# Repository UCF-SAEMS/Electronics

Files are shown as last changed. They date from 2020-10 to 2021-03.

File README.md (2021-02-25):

# Electronics
This project contains the main electronics for the SAEMS Senior Design Project. Currently, this consists of a mainboard and an secondary LED daughter board.

## Mainboard
This is the main controller board for the SAEMS project. It's main functionality is the coordination with the Zigbee base station and sensor data acquisition.

### Block Diagram
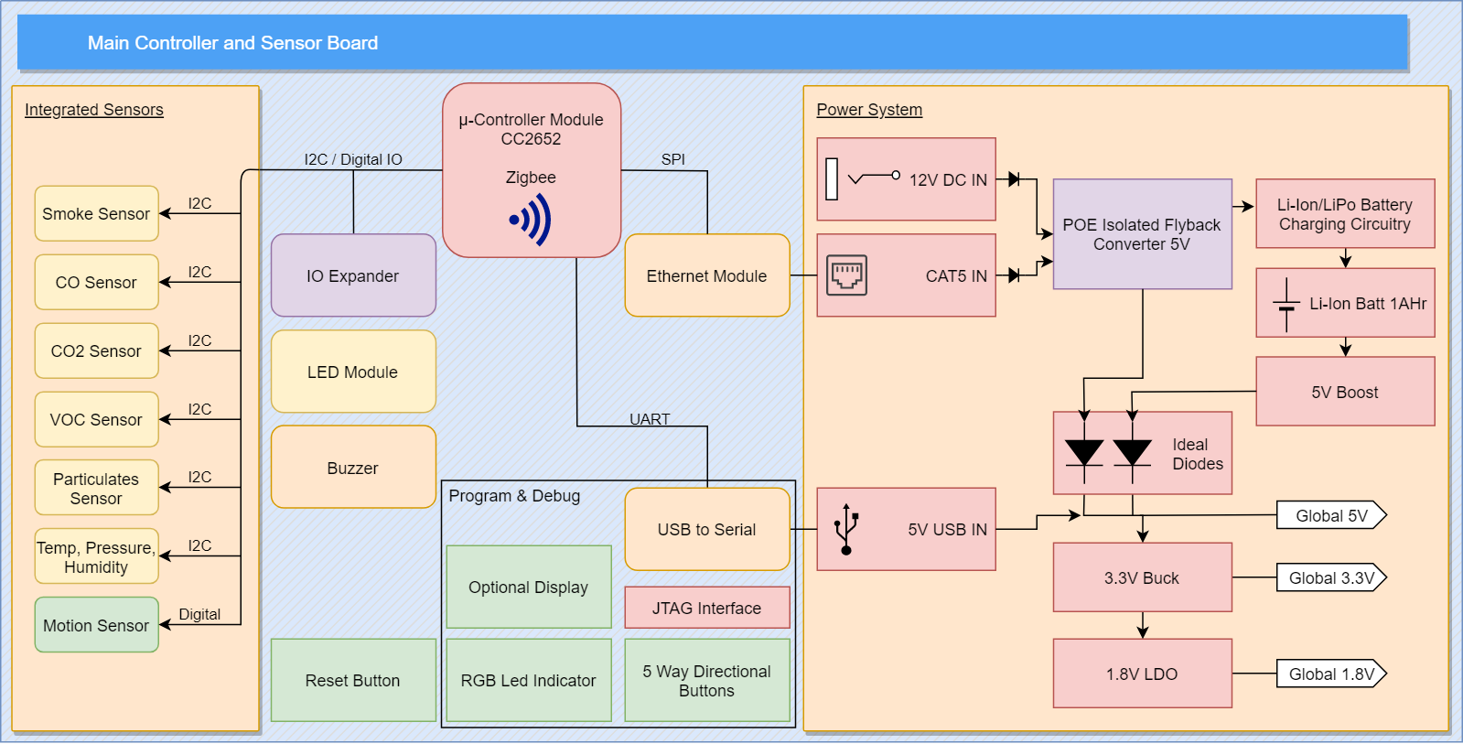
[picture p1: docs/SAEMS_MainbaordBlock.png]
Mainboard_Diagram


[Edit on draw.io](https://app.diagrams.net/#HUCF-SAEMS%2FElectronics%2Fmain%2Fdocs%2FSAEMS_MainbaordBlock.png)

### Schematic
STAIR_Mainboard-schematic

### Layout
<span>PCB Top</span>
<span>PCB Bottom</span>

## Gerbers
Can be found within the Github [repository](build/gerbers).

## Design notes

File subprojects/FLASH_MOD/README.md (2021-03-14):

## FLASH_MOD
This is a bit of a hack. The embedded web server and coresponding assets such as html, css, and javascript libraries took more space than expected to host completly locally. To solve this problem, a FLASH_MOD was developed to add additional external flash memory over SPI.

### Schematic
FLASH_MOD-schematic

### Layout
<span>PCB Top</span>
<span>PCB Bottom</span>

## Gerbers
Can be found within the Github [repository](build/gerbers).

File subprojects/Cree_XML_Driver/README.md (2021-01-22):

## LED Board / Cree_XML_Driver
This is the high power, RGBW LED driver and integrated module board. It includes 4 constant current buck switchers and a set WS2811's to control the individual brightnesses of each color.

### Block Diagram
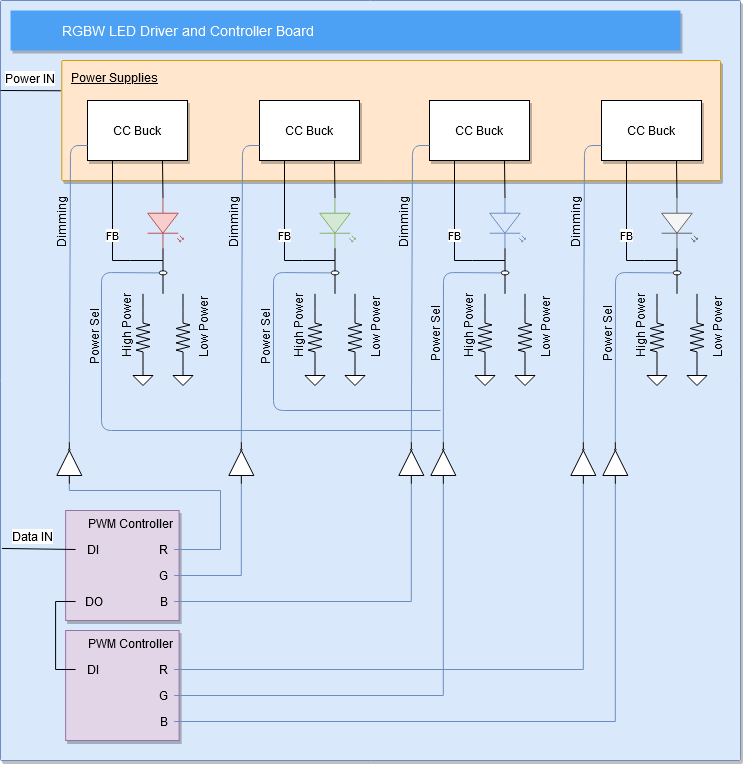
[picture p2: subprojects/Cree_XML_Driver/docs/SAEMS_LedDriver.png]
Cree_XML_Driver_Diagram


[Edit on draw.io](https://app.diagrams.net/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)

### Schematic
Cree_XML_Driver-schematic

### Layout
<span>PCB Top</span>
<span>PCB Bottom</span>

## Gerbers
Can be found within the Github [repository](build/gerbers).

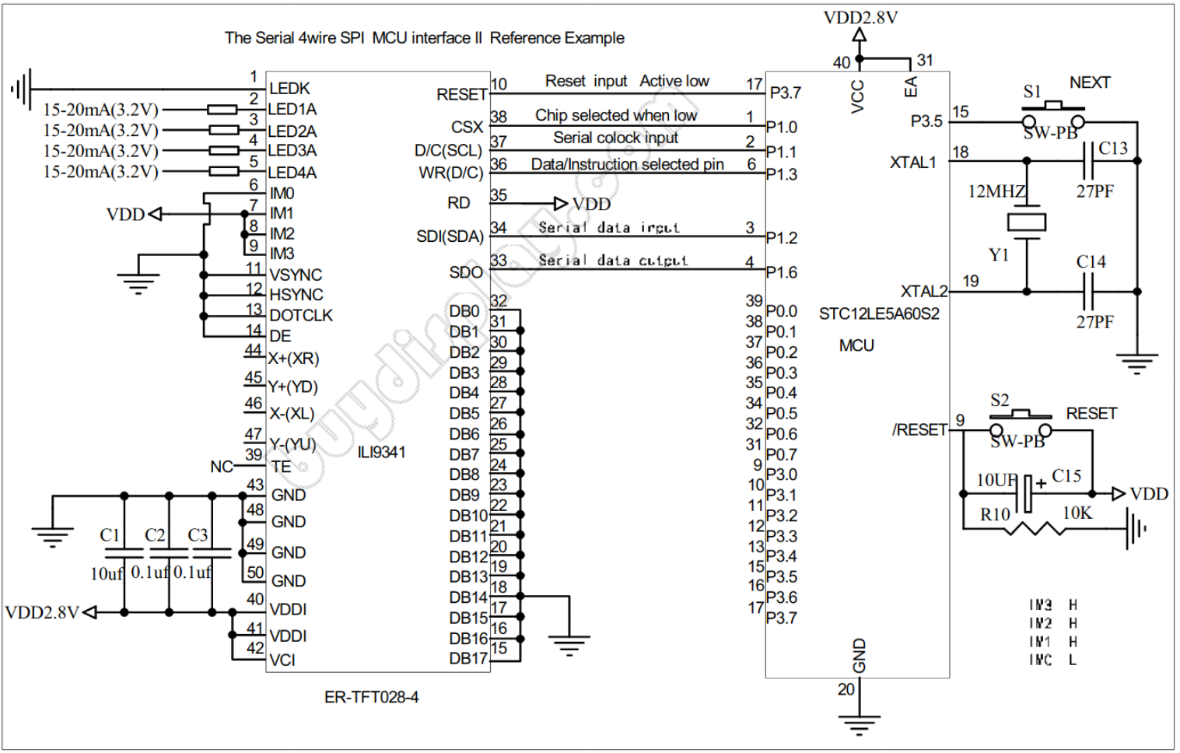
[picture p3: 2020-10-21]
docs/notes/display_rec.png

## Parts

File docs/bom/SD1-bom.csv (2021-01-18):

Row | Description | Part | References | Value | Footprint | Quantity Per PCB | Datasheet | Manufacturer | MPN | Note | Digikey | DNP | LCSC | Mouser | Error | Mfr | Size | Type | Voltage | Current | Power | Volt | Alt
1 | Particulate Matter Sensor I²C | SPS30 | $U101 | SPS30 |  | 1 |  |  | SPS30 | PM2.5 PARTICLE SENSOR | 1649-1106-ND
2 | Unpolarized capacitor, small symbol | C_Small | C602 | 0 | C_0603_1608Metric | 1 | ~ |  |  |  |  | 1
3 | Unpolarized capacitor, small symbol | C_Small | C216 C217 | 20p | C_0603_1608Metric | 2 | ~ |  | CC0603JRNPO9BN200 | CAP CER 20PF 50V C0G/NPO 0603 | 311-1424-1-ND |  | C105621
4 | Unpolarized capacitor, small symbol | C_Small | C314 C803 C807 | 100p | C_0603_1608Metric | 3 | ~ |  | CL10C101JC8NNNC | CAP CER 100PF C0G 50V 0603 | 1276-1295-1-ND | 1 | C296717 |  | 5% |  | 0603 | C0G | 50V
5 | Unpolarized capacitor, small symbol | C_Small | C313 | 330p | C_0805_2012Metric | 1 | ~ |  | CC0805KRX7RABB331 | CAP CER 330PF X7R 200V 0805 | 311-4334-1-ND |  | C527231 |  | 10% |  | 0805 | X7R | 200V
6 | Unpolarized capacitor, small symbol | C_Small | C305 | 680p | C_0603_1608Metric | 1 | ~ |  | 0603B681K500CT | CAP CER 680PF 25V X7R 0603 | 1292-1458-1-ND |  | C335547 |  | 10% |  | 0603 | X7R | 25V
7 | Unpolarized capacitor, small symbol | C_Small | C311 | 1n | C_0805_2012Metric | 1 | ~ |  | CL21B102KCANNNC | CAP CER 1NF X7R 100V 0805 | 1276-1169-1-ND |  | C15177 |  | 10% |  | 0805 | X7R | 100V
8 | Unpolarized capacitor | C | C301 | 2200p | C_1812_4532Metric | 1 | ~ |  | 202S43W222KV4E | CAP CER 2.2NF 2kV X7R 1812 |  |  | C426624 |  | 10% |  | 1812 | X7R | 2kV
9 | Unpolarized capacitor, small symbol | C_Small | C213 C214 | 6.8n | C_0603_1608Metric | 2 | ~ |  | CC0603KRX7R9BB682 | CAP CER 6800PF 50V X7R 0603 | 311-1084-1-ND |  | C107097
10 | Unpolarized capacitor, small symbol | C_Small | C215 C316 | 8.2n | C_0603_1608Metric | 2 |  |  | CC0603KRX7R9BB822 | CAP CER 8.2NF X7R 50V 0603 | 311-1811-1-ND |  | C113812 |  | 10% |  | 0603 | X7R | 50V
11 | Unpolarized capacitor, small symbol | C_Small | C212 C318 | 22n | C_0603_1608Metric | 2 | ~ |  | CL10B223KC8WPNC | CAP CER 22NF X7R 50V 0603 | 1276-CL10B223KC8WPNCCT-ND |  | C472763 |  | 10% |  | 0603 | X7R | 50V
12 | Unpolarized capacitor, small symbol | C_Small | C105 C106 C108 C203 C204 C205 C206 C207 C208 C209 C218 C315 C401 C403 C405 C501 C601 C703 C704 | 0.1u | C_0603_1608Metric | 19 | ~ |  | 0603B104K500CT | CAP CER 0.1UF 50V X7R 0603 | 1292-1643-1-ND |  |  |  | 10% |  | 0603 | X7R | 50V
13 | Unpolarized capacitor, small symbol | C_Small | C312 | 0.1u | C_0805_2012Metric | 1 | ~ |  | CL21B104KCFWPNE | CAP CER 0.1UF X7R 100V 0805 | 1276-6733-1-ND |  | C307361 |  | 10% |  | 0805 | X7R | 100V
14 | Unpolarized capacitor, small symbol | C_Small | C307 | 0.22u | C_0805_2012Metric | 1 | ~ |  | CL21B224KBFNNNE | CAP CER 220NF 25V X7R 0805 | 1276-1093-1-ND |  | C5378 |  | 10% |  | 0805 | X7R | 25V
15 | Unpolarized capacitor, small symbol | C_Small | C102 C104 C317 C701 C702 C707 | 1u | C_0603_1608Metric | 6 | ~ |  | TMK107B7105KA-T | CAP CER 1UF 25V X7R 0603 | 587-2984-1-ND
16 | Unpolarized capacitor, small symbol | C_Small | C302 C304 | 1u | C_1210_3225Metric | 2 | ~ |  | C1210C105K1RACAUTO | CAP CER 1UF 100V X7R 1210 | 399-7044-1-ND |  | C129676 |  | 10% |  | 1210 | X7R | 100V
17 | Unpolarized capacitor, small symbol | C_Small | C201 C202 C210 C211 C219 C402 C404 C808 C811 | 4.7u | C_0603_1608Metric | 9 | ~ |  | C0603C475K9PACTU | CAP CER 4.7UF 6.3V X5R 0603 | 399-3482-1-ND |  | C86016
18 | Unpolarized capacitor, small symbol | C_Small | C101 C103 C107 C705 C706 C801 C802 C806 C809 C810 | 10u | C_0603_1608Metric | 10 |  |  | C1608X5R1A106M080AC | CAP CER 10UF 10V X5R 0603 | 445-6853-1-ND
19 | Polarized capacitor, small US symbol | CP1_Small | C306 | 10u | CP_Elec_4x5.8 | 1 | ~ |  | EEEHD1C100AR | CAP ALU 10UF 16V 4x5.8 | PCE4949CT-ND |  | C401842 |  | 20% |  | .2x.21in | Aluminum | 16V
20 | Polarized capacitor, small US symbol | CP1_Small | C303 | 22u | C_Elec_6.3x7.7 | 1 | ~ |  | EEHZC1J220XP | CAP ALU 22UF 63V 6.3x7.7 | P15467CT-ND |  | C264048 |  | 20% |  | .26x.276in | Aluminum | 63V
21 | Unpolarized capacitor, small symbol | C_Small | C308 C310 C804 C805 | 47u | C_1210_3225Metric | 4 |  |  | 1210X476K160CT | CAP CER 47UF X5R 10V 1210 | 587-5922-1-ND |  | C396815 |  | 20% |  | 1210 | X5R | 10V
22 | Polarized capacitor, small US symbol | CP1_Small | C309 | 47u | CP_Elec_4x5.8 | 1 | ~ |  | EEEFT1C470AR | CAP ALU 47UF 6.3V 4x5.8 | P15090CT-ND |  | C178589 |  | 20% |  | .2x.21in | Aluminum | 6.3V
23 | Diode, filled shape | D_ALT | D305 D306 D307 D801 | BAS16 | D_SOT-23_ANK | 4 | ~ |  | BAS16-7-F | DIODE GEN PURP 75V 200MA SOT23-3 | BAS16-FDICT-ND |  | C69162* |  |  |  |  |  |  | 150mA | 350mW | 75V
24 | BAV99 High-speed switching diodes, SOT-23 | BAV99 | D310 | BAV99 | SOT-23 | 1 | https://assets.nexperia.com/documents/data-sheet/BAV99_SER.pdf |  | BAV99,215 | BAV99 switching diode, generic | 1727-2914-1-ND |  | C152481
25 | Light emitting diode, filled shape | LED_ALT | D311 D402 D403 D404 D802 D803 | LED_ALT | LED_0603_1608Metric | 6 |  |  | 150060RS75000 | LED RED CLEAR 0603 SMD | 732-4978-1-ND |  | C205443
26 | RGB LED, red/green/blue/anode | LED_RGBA | D101 | LED_RGBA | LED_19-237_1.6x1.6mm | 1 | ~ |  | 19-237 | RGB PCB TOP VIEW SMD LED 0606 | 19-237A/R6GHBHC-B01/2T |  | C264508
27 | Schottky diode, filled shape | D_Schottky_ALT | D308 | MBRS540T3 | D_SMC | 1 | ~ |  | MBRS540T3G | RECTIFIER DIODE, SCHOTTKY, 5A, 4 |  |  | C31849 |  |  |  |  |  |  | 5A |  | 40V
28 | Diode | D | D301 D302 D303 D304 | MURA120 | D_SMA | 4 | ~ |  | MURA120T3G |  | MURA120T3GOSCT-ND |  | C111832 |  |  |  |  |  |  | 1A |  | 200V
29 | Photodiode, filled shape | D_Photo_ALT | D701 | Photodiode alt | LED_D3.0mm_Clear | 1 | ~ |  | PD204-6C | SENSOR PHOTODIODE 940NM RADIAL | 1080-1140-ND |  | C264281
30 | Bidirectional transient-voltage-suppression diode, filled shape | D_TVS_ALT | D309 | SMAJ58A | D_SMA | 1 | ~ |  | SMAJ58CA-E3/61 | TVS DIODE 58V 93.6V DO214AC | SMAJ58CA-E3/61GICT-ND |  | C506567 |  |  |  |  |  |  |  | 1W | 58V
31 | TVS Diode Array, 5.5V Standoff, 3 Channels, SOT-143 package | SP0503BAHT | D401 | SP0503BAHT | SOT-143 | 1 | http://www.littelfuse.com/~/media/files/littelfuse/technical%20resources/documents/data%20sheets/sp05xxba.pdf |  | SP0503BAHTG | TVS DIODE 5.5V 8.5V SOT143-4 | F2715CT-ND |  | C7074
32 | Ferrite bead, small symbol | Ferrite_Bead_Small | FB301 FB302 | 10 | L_0603_1608Metric | 2 | ~ | Chilisin Elec | PBY160808T-110Y-N | 11Ω @ 100MHz 4A 1 20mΩ 0603 Ferrite Beads |  |  | C280672 |  |  | MMZ2012R150AT000
33 | Ferrite bead, small symbol | Ferrite_Bead_Small | FB101 FB201 FB601 FB701 | Ferrite_Bead_Small | L_0603_1608Metric | 4 | ~ |  | BLM18PG471SN1D | 470 Ohms @ 100MHz 1 Power Line Ferrite Bead 0603 1A 200mOhm | 490-5223-1-ND |  | C97853 | 81-BLM18PG471SN1D
34 | USB Micro Type B connector | USB_B_Micro | J403 | 10118194-0001LF | USB_Micro-B_Amphenol_10118194_Horizontal | 1 | ~ |  | 10118194-0001LF | CONN RCPT USB2.0 MICRO B SMD R/A | 609-4618-1-ND |  | C132563
35 | Generic connector, single row, 01x02, script generated (kicad-library-utils/schlib/autogen/connector/) | Conn_01x02 | J303 J304 | Conn_01x02 | PinSocket_1x02_P2.54mm_Vertical | 2 | ~
36 | Generic connector, single row, 01x02, script generated (kicad-library-utils/schlib/autogen/connector/) | Conn_01x02 | J801 | Conn_01x02 | JST_PH_B2B-PH-K_1x02_P2.00mm_Vertical | 1 | ~ |  | B2B-PH-K-S(LF)(SN) | CONN HEADER VERT 2POS 2MM | B2B-PH-K-S(LF)(SN) |  | C131337
37 | Generic connector, single row, 01x02, script generated (kicad-library-utils/schlib/autogen/connector/) | Conn_01x02 | J802 | Conn_01x02 | PinHeader_1x02_P2.54mm_Vertical | 1 | ~
38 | Generic connector, single row, 01x11, script generated (kicad-library-utils/schlib/autogen/connector/) | Conn_01x11 | J401 | Conn_01x11 | Molex_SL_171971-0011_1x11_P2.54mm_Vertical | 1 | ~ |  |  | TI Eval connector
39 | Cortex Debug Connector, standard ARM Cortex-M SWD and JTAG interface | Conn_ARM_JTAG_SWD_10 | J404 | Conn_ARM_JTAG_SWD_10 | PinHeader_2x05_P1.27mm_Wide_Shrouded_Vertical_SMD | 1 | http://infocenter.arm.com/help/topic/com.arm.doc.ddi0314h/DDI0314H_coresight_components_trm.pdf |  | FTSH-105-01-L-DV-K | 2x5 1.27mm SMD connector | SAM8799-ND |  |  |  |  |  |  |  |  |  |  |  | BXIDM03
40 | FTDI, USB to serial TTL cable | FTDI_TTL_Cable | J402 | FTDI_TTL_Cable | PinHeader_1x06_P2.54mm_Vertical | 1 |  |  |  |  |  |  | C190819
41 | RJ45 PoE 10/100 Base-TX Jack with Magnetic Module | RJ45_Abracon_ARJP11A-MASA-B-A-EMU2 | J201 | HR861153C | RJ45_Abracon_ARJP11A-MA_Horizontal | 1 | https://abracon.com/Magnetics/lan/ARJP11A.PDF |  | ARJP11A-MASA-B-A-EMU2 | Alt HR861153C verified | ARJP11A-MASA-B-A-EMU2-ND |  | HR861153C
42 | Generic connectable mounting pin connector, single row, 01x08, script generated (kicad-library-utils/schlib/autogen/connector/) | Conn_01x08_MountingPin | J101 | JST 1.25mm | Molex_PicoBlade_53398-0871_1x08-1MP_P1.25mm_Vertical | 1 | ~ |  | 0533980871 |  | WM7612CT-ND |  | C53040
43 | RECAPS connector pinout | RECAPS_Master_r0 | J102 | JST 1.25mm | Molex_PicoBlade_53398-0871_1x08-1MP_P1.25mm_Vertical | 1 |  |  | 0533980871 |  | WM7612CT-ND |  | C53040 | -
44 | Generic connectable mounting pin connector, single row, 01x05, script generated (kicad-library-utils/schlib/autogen/connector/) | Conn_01x05_MountingPin | J103 | JST ZH 1.5mm 1x5 | JST-ZR-B5B-SM4-TFLFSN_1x05-1MP_P1.5mm_Vertical | 1 | ~ |  | B5B-ZR-SM4-TF(LF)(SN) | 1.5mm 01x05 JST ZH | 455-1684-1-ND |  | C265440
45 | DC Barrel Jack with an internal switch | Barrel_Jack_Switch | J301 J302 | PJ-102AH | BarrelJack_CUI_PJ-102AH_Horizontal | 2 | ~ |  | PJ-102AH | CONN PWR JACK 2X5.5MM SOLDER | CP-102AH-ND |  | C84007
46 | Jumper, 3-pole, both open | Jumper_3_Open | JP104 | Jumper_3_Open | PinHeader_1x03_P2.54mm_Vertical | 1 | ~
47 | Jumper, normally open, small symbol | Jumper_NO_Small | JP401 | Jumper_NO_Small | PinHeader_1x02_P2.54mm_Vertical | 1 | ~
48 | Inductor with ferrite core | L_Core_Ferrite | L801 L802 | 1u | L_Wuerth_HCI-5040 | 2 | ~ |  | 744316100 | FIXED IND 1UH 11.5A 4.75 MOHM | 732-6176-1-ND
49 | Inductor with ferrite core | L_Core_Ferrite | L301 | 4.7u | L_Taiyo-Yuden_MD-4040 | 1 | ~ |  | SLW4030S4R7MST | 4.7uH ±20% 2A 60mΩ SMD,4x4x3mm | 587-5994-1-ND |  | C206284, C326301, C15269
50 | Crystal speaker/transducer | Speaker_Crystal | LS101 | Speaker_Crystal | Buzzer_TDK_PS1240P02BT_D12.2mm_H6.5mm | 1 | ~ |  | PS1240P02BT | AUDIO PIEZO TRANSDUCER 30V TH | 445-2525-1-ND |  | C76871
51 | 50V Vds, 0.22A Id, N-Channel MOSFET, SOT-23 | BSS138 | Q101 | BSS138 | SOT-23 | 1 | https://www.fairchildsemi.com/datasheets/BS/BSS138.pdf |  | BSS138 | MOSFET N-CH 50V 200MA SOT23-3 | BSS138-FDICT-ND
52 | Dual PNP transistor, 6 pin package | Q_DUAL_PNP_PNP_C1B1B2C2E2E1 | Q302 Q802 | DMMT5401 | SOT-23-6 | 2 | ~ |  | DMMT5401-7-F | TRANS 2PNP 150V 0.2A SOT26 | DMMT5401-FDICT-ND |  | C154733
53 | P-MOSFET transistor, gate/source/drain | Q_PMOS_GSD | Q301 Q801 | DMP3098L-7 | SOT-23-6 | 2 | ~ |  | DMP3098L-7 | MOSFET P-CH 30V 3.8A SOT23-3 | DMP3098LDICT-ND |  | C150492
54 | N-MOSFET transistor, gate/drain/source | Q_NMOS_GDS | Q303 | FDT86244 | SOT-223-3_TabPin2 | 1 | https://www.onsemi.com/pub/Collateral/FDT86244-D.pdf |  | FDT86244 | MOSFET N-CH 150V 2.8A SOT-223 | FDT86244CT-ND |  | C489347
55 | NPN bias resistor transistor, base/emitter/collector | Q_NPN_BEC_BRT | Q102 | PDTC114EU,115 | SOT-323_SC-70 | 1 | ~ |  | PDTC114EU,115 | TRANS PREBIAS NPN 200MW SOT323 | 1727-5132-1-ND |  | C135830
56 | Resistor, US symbol | R_US | R308 R316 | 0 | R_0603_1608Metric | 2 | ~ |  |  |  |  |  |  |  | 1% |  | 0603 |  |  |  | 1/16W
57 | Resistor, small US symbol | R_Small_US | R602 | 0 | R_0603_1608Metric | 1 | ~ |  |  |  |  | 1
58 | Resistor, US symbol | R_US | R318 | 0.56 | R_1206_3216Metric | 1 | ~ |  | KDV12FR560ET | RES 560M OHM 1% 1/2W 1206 | 273-KDV12FR560ETCT-ND |  | C175807 |  | 1% |  | 1206 |  |  |  | 1/4W
59 | Resistor, US symbol | R_US | R201 | 10 | R_0603_1608Metric | 1 |  |  | RC0603JR-0710RL | RES SMD 10 OHM 5% 1/10W 0603 | 311-10GRDKR-ND |  | C109317
60 | Resistor, US symbol | R_US | R302 R401 | 22.1 | R_0603_1608Metric | 2 |  |  | RC0603FR-0722R1L | RES SMD 22.1 OHM 1% 1/10W 0603 | 311-22.1HRCT-ND |  | C137767
61 | Resistor, US symbol | R_US | R202 R203 R207 R208 R304 R311 | 49.9 | R_0603_1608Metric | 6 |  |  | RC0603FR-0749R9L | RES SMD 49.9 OHM 1% 1/16W 0603 | 311-49.9HRCT-ND |  | C114625 |  | 1% |  | 0603 |  |  |  | 1/16W
62 | Resistor, US symbol | R_US | R312 | 82 | R_2010_5025Metric | 1 | ~ |  |  | RES SMD 82 OHM 5% 1/2W 2010 |  |  | C421678, C20464 |  | 5% |  | 2010 |  |  |  | 1/2W
63 | Resistor, US symbol | R_US | R320 | 499 | R_0603_1608Metric | 1 | ~ |  | AC0603FR-07499RL | RES SMD 499 OHM 1% 1/16W 0603 | 13-AC0603FR-07499RLCT-ND |  | C144655 |  | 1% |  | 0603 |  |  |  | 1/16W
64 | Resistor, US symbol | R_US | R109 R110 R111 R112 R113 R204 R205 R206 R313 R322 R323 R326 R403 R404 R405 R406 R810 R811 | 1k | R_0603_1608Metric | 18 | ~ |  | RC0603FR-071KL | RES SMD 1K OHM 1% 1/10W 0603 | 311-1.00KHRCT-ND |  | C125933 |  | 1% |  | 0603 |  |  |  | 1/16W
65 | Resistor, US symbol | R_US | R317 | 1.27k | R_0603_1608Metric | 1 | ~ |  | RC0603FR-071K27L | RES SMD 1.27K OHM 1% 1/16W 0603 | 311-1.27KHRCT-ND |  | C245930 |  | 1% |  | 0603 |  |  |  | 1/16W
66 | Resistor, US symbol | R_US | R105 R106 R107 R108 R210 R211 R212 R213 R214 R215 R309 R314 R501 R502 R503 R804 R808 R812 R813 | 10k | R_0603_1608Metric | 19 |  |  | RC0603FR-0710KL | RES SMD 10K OHM 1% 1/10W 0603 | 311-10.0KHRCT-ND |  | C98220 |  | 1% |  | 0603 |  |  |  | 1/16W
67 | Resistor, US symbol | R_US | R216 | 12.4k | R_0603_1608Metric | 1 |  |  | RC0603FR-0712K1L | RES SMD 12.1K OHM 1% 1/10W 0603 | 311-12.1KHRCT-ND |  | C123417
68 | Resistor, US symbol | R_US | R324 | 13.3k | R_0603_1608Metric | 1 | ~ |  | RC0603FR-0713K3L | RES SMD 13.3K OHM 1% 1/16W 0603 | 311-13.3KHRCT-ND |  | C185373 |  | 1% |  | 0603 |  |  |  | 1/16W
69 | Resistor, US symbol | R_US | R319 | 19.1k | R_0603_1608Metric | 1 | ~ |  | AC0603FR-0719K1L | RES SMD 19.1K OHM 1% 1/16W 0603 | 13-AC0603FR-0719K1LCT-ND |  | C227638 |  | 1% |  | 0603 |  |  |  | 1/16W
70 | Resistor, US symbol | R_US | R301 | 24.9k | R_0603_1608Metric | 1 | ~ |  | RC0603FR-0724K9L | RES SMD 24.9K OHM 1% 1/16W 0603 | 311-24.9KHRCT-ND |  | C137761 |  | 1% |  | 0603 |  |  |  | 1/16W
71 | Resistor, US symbol | R_US | R305 | 39.2k | R_0603_1608Metric | 1 | ~ |  | AC0603FR-0739K2L | RES SMD 39.2K OHM 1% 1/16W 0603 | YAG3602CT-ND |  | C227854 |  | 1% |  | 0603 |  |  |  | 1/16W
72 | Resistor, US symbol | R_US | R315 | 41.2k | R_0603_1608Metric | 1 | ~ |  | RC0603FR-0741K2L | RES SMD 41.2K OHM 1% 1/16W 0603 | 311-41.2KHRCT-ND |  | C185330 |  | 1% |  | 0603 |  |  |  | 1/16W
73 | Resistor, US symbol | R_US | R115 R310 R402 R805 | 47.5k | R_0603_1608Metric | 4 |  |  | RC0603FR-0747K5L | RES SMD 47.5K OHM 1% 1/10W 0603 | 311-47.5KHRCT-ND |  | C137715
74 | Resistor, US symbol | R_US | R306 R807 | 59k | R_0603_1608Metric | 2 | ~ |  | RC0603FR-0759KL | RES SMD 59K OHM 1% 1/16W 0603 | 311-59.0KHRCT-ND |  | C309564 |  | 1% |  | 0603 |  |  |  | 1/16W
75 | Resistor, US symbol | R_US | R307 | 80.6k | R_0603_1608Metric | 1 | ~ |  | RC0603FR-0780K6L | RES SMD 80.6K OHM 1% 1/16W 0603 | 311-80.6KHRCT-ND |  | C482928 |  | 1% |  | 0603 |  |  |  | 1/16W
76 | Resistor, US symbol | R_US | R101 R321 R325 R407 R801 R803 R809 | 100k | R_0603_1608Metric | 7 | ~ |  | RC0603FR-07100KL | RES SMD 100K OHM 1% 1/10W 0603 | 311-100KHRCT-ND
77 | Resistor, US symbol | R_US | R303 R806 | 392k | R_0603_1608Metric | 2 | ~ |  | RC0603FR-07392KL | RES SMD 392K OHM 1% 1/16W 0603 | 311-392KHRCT-ND |  | C245963 |  | 1% |  | 0603 |  |  |  | 1/16W
78 | Resistor, US symbol | R_US | R114 R601 R802 | 732k | R_0603_1608Metric | 3 |  |  | RC0603FR-07732KL | RES SMD 732K OHM 1% 1/10W 0603 | 311-732KHRCT-ND |  | C246003
79 | Resistor, US symbol | R_US | R102 R103 R104 R209 R701 | 1M | R_0603_1608Metric | 5 |  |  | RC0603FR-071ML | RES SMD 1M OHM 1% 1/10W 0603 | 311-1.00MHRCT-ND |  | C105578
80 | Alps 4-direction Type with Center-push Function | Multidirection_Switch | SW101 | Multidirection_Switch | SKRHA_bosses | 1 | https://tech.alpsalpine.com/prod/e/html/multicontrol/switch/skrh/skrh_list.html |  | SKRHADE011, SKRHADE010 |  |  |  | C602036, C202415
81 | Push button switch, generic, two pins | SW_Push | SW401 | PTS810 | SW_SPST_PTS810 | 1 | ~ |  |  | SWITCH TACTILE SPST-NO 0.05A 16V | CKN10503CT-ND |  | C221897
82 | SMT POE Gate Drive Transformer, 1:0.667:0.262, 36-72 to 5V | HR051067 | T301 | HR051067 | HR051067 | 1 |  |  | HR051067 |  |  |  | C93830
83 | SPEC Carbon Monoxide (CO) Sensor 1000ppm THT | 110-102 | U601 | 110-102 | SPEC_110-102 | 1 |  | SPEC Sensors, LLC | 110-102 |  | 1684-1000-ND
84 | Integrated Optical Module for Smoke Detection | ADPD188BI | U702 | ADPD188BI | ADPD188BI | 1 | https://www.analog.com/media/en/technical-documentation/data-sheets/ADPD188BI.pdf | Analog Devices Inc. | ADPD188BI-ACEZR7 | SENSOR SMOKE 470NM/850NM AMB 24LGA | ADPD188BI-ACEZR7
85 | 3-in-1 sensor, humidity, pressure, temperature, I2C and SPI interface, 1.71-3.6V, LGA-8 | BME280 | U105 | BME280 | Bosch_LGA-8_2.5x2.5mm_P0.65mm_ClockwisePinNumbering | 1 | https://www.bosch-sensortec.com/media/boschsensortec/downloads/datasheets/bst-bme280-ds002.pdf | Bosch | BME280 | Humidity Temperature Sensor 0 ~ 100% RH I²C, SPI ±3% 1s Surface Mount | 828-1063-1-ND |  | C92489 | 262-BME280
86 | RF TxRx+MCU 802.15.4, Bluetooth Bluetooth v5.0, Thread, Zigbee | CC2652P | U103 | CC2652P | RF-BM-2652P2 | 1 | https://www.szrfstar.com/product/237-en.html | RF-star | RF-BM-2652P2
87 | Ultra-low power digital gas sensor for monitoring indoor air quality | CCS811 | U501 | CCS811 | AMS_LGA-10-1EP_2.7x4mm_P0.6mm | 1 | http://ams.com/eng/Products/Environmental-Sensors/Air-Quality-Sensors/CCS811 | ScioSense | CCS811B-JOPR5K | CCS811B-JOPR5K LGA10 LF T&R | CCS811B-JOPR5KCT-ND
88 | USB to UART master bridge, QFN-28 | CP2102N-A01-GQFN28 | U401 | CP2102N-A02-GQFN28R | QFN-28-1EP_5x5mm_P0.5mm_EP3.35x3.35mm | 1 | https://www.silabs.com/documents/public/data-sheets/cp2102n-datasheet.pdf | Silicon Labs | CP2102N-A02-GQFN28R | USB Bridge, USB to UART USB 2.0 UART Interface 28-QFN (5x5) | 336-5890-1-ND |  | C428937 |  |  |  |  |  |  |  |  |  | CP2102N-A02-GQFN28R
89 | PIR Motion Sensor EKMC VZ Panasonic | EKMC1691111 | U106 | EKMC1691111 | EKM | 1 | https://www3.panasonic.biz/ac/ae/search_num/index.jsp?c=detail&part_no=EKMC1691111 | Panasonic Electric Works | EKMC1691111 | Sensor PIR (Passive Infrared) 98.425 (2.5m) - Module | 255-6303-ND
90 | 2.8"TFT Touch Shield for Arduino w/Capacitive Touch Screen Module | ER-TFTM028-4 | U101 | ER-TFTM028-4 | ER-TFTM028-4 | 1 | https://www.buydisplay.com/2-8-inch-tft-touch-shield-for-arduino-w-capacitive-touch-screen-module |  | DS1023-2*20SF11 | Header Female 2x20 2.54mm |  |  | C132132
91 | Electrochemical Sensor AFE | LMP91000 | U602 | LMP91000 | WSON-14-1EP_4.0x4.0mm_P0.5mm_EP2.6x2.6mm | 1 | https://www.ti.com/lit/ds/symlink/lmp91000.pdf | Texas Instruments | LMP91000SD | IC AFE 1 CHAN 8BIT 14WSON | 296-44382-1-ND |  | C181364, C84366
92 | 16-bit I/O expander, I2C, interrupts, w pull-ups, SSOP-28 | MCP23017_SS | U102 | MCP23017 | SSOP-28_5.3x10.2mm_P0.65mm | 1 |  | Microchip Technology | MCP23017T-E/SS | IC I/O EXPANDER 16BIT I2C 28SSOP | MCP23017T-E/SSCT-ND
93 | Single cell, Li-Ion/Li-Po charge management controller, 4.20V, Tri-State Status Output, in SOT23-5 package | MCP73831-2-OT | U803 | MCP73831-2-OT | SOT-23-5 | 1 | http://ww1.microchip.com/downloads/en/DeviceDoc/20001984g.pdf | Microchip Technology | MCP73831T-2ACI/OT | IC CONTROLLR LI-ION 4.2V SOT23-5 | MCP73831T-2ACI/OTCT-ND |  | C424093
94 | I2C CO2, humidity, and temperature sensor | SCD30 | U104 | SCD30 | SCD30_reverse_mount | 1 | https://www.sensirion.com/fileadmin/user_upload/customers/sensirion/Dokumente/9.5_CO2/Sensirion_CO2_Sensors_SCD30_Datasheet.pdf | Sensirion | SCD30 | CO2 SENSOR I2C/MODBUS/PWM DIGITL | 1649-1098-ND |  |  | 403-SCD30
95 | Smoke Chamber for ADPD188BI | Chamber | U703 | Smoke Chamber | ADPD188BI_Chamber | 1 |  |  |  | 3D printed smoke chamber |  | 1
96 | Optocoupler, Phototransistor Output, 5300 VRMS, VCEO 70V, CTR% 40-80, -55 to +110 degree Celcius, UL, BSI, FIMKO, cUL, THT PDIP-4 | SFH617A-1 | U303 | TCMT1107 | SOIC-4_4.55x2.6mm_P1.27mm | 1 | https://www.vishay.com/docs/83510/tcmt1100.pdf |  | TCMT1107 | Optoisolator Transistor Output 3750Vrms 1 Channel 4-SOP | TCMT1107CT-ND |  | C81148
97 | Shunt Regulator, SOT-23 | TL431DBZ | U302 | TL431A | SOT-23 | 1 | http://www.ti.com/lit/ds/symlink/tl431.pdf | Texas Instruments | TL431ACDBZR | IC VREF SHUNT 36V 1% SOT23-3 | 296-17328-1-ND |  | C113312
98 | High Efficiency Synchronous Buck Converter, Adjustable Output 0.6V-5.5V, 3A, SOT563 | TLV62585 | U802 | TLV62585 | SOT-563 | 1 | http://www.ti.com/lit/ds/symlink/tlv62585.pdf |  | TLV62585DRLR | IC REG BUCK ADJUSTABLE 3A SOT563 | 296-51694-1-ND |  | C485117
99 | 200mA Low Dropout Voltage Regulator, Fixed Output 1.8V, SOT-23-5 | TLV70018_SOT23-5 | U701 | TLV70018 | SOT-353_SC-70-5 | 1 | http://www.ti.com/lit/ds/symlink/tlv700.pdf | Texas Instruments | TLV70018DCK | IC REG LINEAR 1.8V 200MA SC70-5 | 296-32409-1-ND |  | C133796
100 | IEEE 802.3 PoE Interfaceand ConverterController | TPS23753A | U301 | TPS23753A | TSSOP-14_4.4x5mm_P0.65mm | 1 |  | Texas Instruments | TPS23753APWR | IC POE CNTRL 1 CHANNEL 14TSSOP | 296-39365-1-ND |  | C92115
101 | 1MHz 8A Boost converter with 0.5-V ultra-low input voltage | TPS61022 | U801 | TPS61022 | Texas_VQFN-HR-7 | 1 | http://www.ti.com/lit/ds/symlink/tps61022.pdf | Texas Instruments | TPS61022 | Boost Switching Regulator IC Positive Adjustable 2.2V 1 Output 7-VFQFN | 296-TPS61022RWURCT-ND
102 | 10/100Mb SPI Ethernet controller with TCP/IP stack, LQFP-48 | W5500 | U201 | W5500 | LQFP-48_7x7mm_P0.5mm | 1 | http://wizwiki.net/wiki/lib/exe/fetch.php/products:w5500:w5500_ds_v109e.pdf | WIZnet | W5500 | IC CTLR 3-1 ETH TCP/IP 48LQFP | 1278-1021-ND |  | C32843
103 | Three pin crystal, GND on pin 2 | Crystal_GND2 | Y201 | 25MHz | Crystal_SMD_3225-4Pin_3.2x2.5mm | 1 | ~ |  | X1E000021035200 | CRYSTAL 25MHZ 20PF SMD | SER4375CT-ND |  | C91738, C255955
Project info:
Schematic: | SD1
Variant: | default
Revision:
Date: | 2021-01-18_13-06-37
KiCad Version: | 5.1.7-a382d34a8~87~ubuntu18.04.1
Statistics:
Component Groups: | 103
Component Count: | 232
Fitted Components: | 232
Number of PCBs: | 1
Total Components: | 232

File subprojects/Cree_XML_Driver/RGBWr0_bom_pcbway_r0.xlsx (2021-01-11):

 |  |  | RGBW_R0 4PCS BOM
Item # | *Ref Des | *Qty | Manufacturer | *Mfg Part # | Description / Value | *Package | Type | Your Instructions / Notes | LCSC | DigiKey
1 | C106 C102 C107 C103 C104 C108 C101 C105 | 8 | Murata Electronics | GRM21BR61C106KE15L | CAP CER 10UF 16V X5R 0805 | Capacitor_SMD:C_0805_2012Metric | SMD |  | C77075 | 490-3886-1-ND
2 | C111 C110 C109 | 3 | Walsin | 0603B104K500CT | CAP CER 0.1UF 50V X7R 0603 | Capacitor_SMD:C_0603_1608Metric | SMD |  | C314282 | 1292-1643-1-ND
3 | D101 | 1 |  |  |  | mylib:LED_Cree_XM-L_20mm_Module | DNS
4 | D102 | 1 |  | PMEG4030ER,115 | DIODE SCHOTTKY 40V 3A SOD123W | Diode_SMD:D_SOD-123F | SMD |  | C389355 | 1727-5313-1-ND
5 | J101 | 1 |  | PJ-102AH | CONN PWR JACK 2X5.5MM SOLDER | Connector_BarrelJack:BarrelJack_CUI_PJ-102AH_Horizontal | DNS |  | C84007 | CP-102AH-ND
6 | J102 | 1 |  |  |  | Connector_PinHeader_2.54mm:PinHeader_1x03_P2.54mm_Horizontal | DNS
7 | J103 | 1 |  | 0532610871 | CONN HEADER SMD R/A 8POS 1.25MM | Connector_Molex:Molex_PicoBlade_53261-0871_1x08-1MP_P1.25mm_Horizontal | SMD |  | C29041 | WM7626CT-ND
8 | JP104 JP103 JP102 JP101 | 4 |  |  |  | Jumper:SolderJumper-3_P1.3mm_Bridged12_Pad1.0x1.5mm | DNS
9 | L101 L103 L102 L104 | 4 |  | SLW4030S4R7MST | 4.7uH ±20% 2A 60m Ohm SMD,4x4x3mm | Inductor_SMD:L_Taiyo-Yuden_MD-4040 | SMD | LCSC | C206284, C15269 | 587-5994-1-ND
10 | LOGO101 | 1 |  |  |  | mylib:MYLIB_CWW_COPPER | DNS
11 | MK101 MK102 MK103 MK104 | 4 |  |  |  | mylib:MountingHole_3.2mm_M3_ISO14580_Pad | DNS
12 | Q101 Q102 Q103 Q104 | 4 |  | Si2302CDS-T1 | MOSFET N-CH 20V 2.6A SOT-23 | Package_TO_SOT_SMD:SOT-23 | SMD |  | C10488 | SI2302CDS-T1-E3CT-ND
13 | R101 R104 R108 R105 | 4 |  | SR732ATTDR120F | RES 0.12 OHM 1% 1/3W 0805 | Resistor_SMD:R_0805_2012Metric | SMD | Order from Digikey | C186575, C171368 | RL12S.12FCT-ND
14 | R102 R103 R107 R106 | 4 |  | SR732ATTDR270F | RES 0.27 OHM 1% 1/3W 0805 | Resistor_SMD:R_0805_2012Metric | SMD | Order from Digikey | C186583, C171374 | RL12S.27FCT-ND
15 | R113 R118 R109 R110 R112 R111 | 6 |  | RC0603FR-07100RL | RES SMD 100 OHM 1% 1/10W 0603 | Resistor_SMD:R_0603_1608Metric | SMD |  | C105588 | 311-100HRCT-ND
16 | R114 R115 R116 R119 R120 R121 | 6 |  | RC0603FR-07100KL | RES SMD 100K OHM 1% 1/10W 0603 | Resistor_SMD:R_0603_1608Metric | SMD |  | C14675 | 311-100KHRCT-ND
17 | R117 R122 | 2 |  | RC0603FR-0733RL | RES SMD 33 OHM 1% 1/10W 0603 | Resistor_SMD:R_0603_1608Metric | SMD |  | C108661 | 311-33.0HRCT-ND
18 | TP101 | 1 |  |  |  | TestPoint:TestPoint_THTPad_1.0x1.0mm_Drill0.5mm | DNS
19 | U101 U103 U102 U104 | 4 | Diodes Incorporated | PAM2804AAB010 | IC LED DRIVER RGLTR 1A TSOT25 | Package_TO_SOT_SMD:TSOT-23-5 | SMD |  | C71463 | PAM2804AAB010DICT-ND
20 | U106 | 1 | Nexperia | 74HC14D,653 | IC INVERTER SCHMITT 6CH 14SO | Package_SO:SOIC-14_3.9x8.7mm_P1.27mm | SMD |  | C5605 | 1727-2783-1-ND
21 | U107 U105 | 2 | Worldsemi | WS2811 | IC LED DRIVER RGB | Package_SO:SOIC-8_3.9x4.9mm_P1.27mm | SMD |  | C114581
Need a quick and accurante quote? Need an efficient production? Please read SMT Ordering Necessary Files & Info in 1 minute. Thank you very much! (https://www.pcbway.com/smt_ordering_guide.html)
Click for Instructions on How to Create a BOM (https://www.pcbway.com/blog/PCB_Assembly/How_to_Build_a_BOM__Bill_Of_Materials_.html)
 | for expensive parts (more than $1) please also quote LCSC and pick the cheaper.

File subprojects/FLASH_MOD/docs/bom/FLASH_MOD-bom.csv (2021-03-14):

Row | Description | Part | References | Value | Footprint | Quantity Per PCB | Datasheet | DNP | MPN | Note | LCSC | Digikey
1 | Unpolarized capacitor, small symbol | C_Small | C2 | 0.1u | C_0603_1608Metric | 1 | ~ |  | 0603B104K500CT | CAP CER 0.1UF 50V X7R 0603 |  | 1292-1643-1-ND
2 | Unpolarized capacitor, small symbol | C_Small | C1 | 1u | C_0603_1608Metric | 1 | ~ |  | TMK107B7105KA-T | CAP CER 1UF 25V X7R 0603 |  | 587-2984-1-ND
3 | Jumper, normally open, small symbol | Jumper_NO_Small | JP1 JP2 JP3 | Jumper_NO_Small | R_0201_0603Metric | 3 | ~
4 | CWW Logo | MYLIB_CWW_COPPER | LOGO101 | MYLIB_CWW_COPPER | MYLIB_CWW_COPPER | 1 |  | 1
5 | Resistor, US symbol | R_US | R1 | 10k | R_0603_1608Metric | 1 |  |  | RC0603FR-0710KL | RES SMD 10K OHM 1% 1/10W 0603 | C98220 | 311-10.0KHRCT-ND
6 | 2.8"TFT Touch Shield for Arduino w/Capacitive Touch Screen Module | ER-TFTM028-4 | U101 | ER-TFTM028-4 | ER-TFTM028-4 | 1 | https://www.buydisplay.com/2-8-inch-tft-touch-shield-for-arduino-w-capacitive-touch-screen-module |  | DS1023-2*20SF11 | Header Female 2x20 2.54mm | C132132
7 | 128Mb Serial Flash Memory, Standard/Dual/Quad SPI, SOIC-8 | W25Q128JVS | U1 | W25Q128JVS | SOIC-8_5.23x5.23mm_P1.27mm | 1 | http://www.winbond.com/resource-files/w25q128jv_dtr%20revc%2003272018%20plus.pdf
Project info:
Schematic: | FLASH_MOD
Variant: | default
Revision:
Date: | 2021-03-14_15-13-46
KiCad Version: | 5.1.7-a382d34a8~87~ubuntu18.04.1
Statistics:
Component Groups: | 7
Component Count: | 9
Fitted Components: | 9
Number of PCBs: | 1
Total Components: | 9

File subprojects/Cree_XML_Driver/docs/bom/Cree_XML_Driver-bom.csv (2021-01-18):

Row | Description | Part | References | Value | Footprint | Quantity Per PCB | Datasheet | LCSC | Manufacturer | Digikey | MPN | Note | DNP | RDS
1 | Unpolarized capacitor, small symbol | C_Small | C109 C110 C111 | 0.1u | C_0603_1608Metric | 3 | ~ | C314282 | Walsin | 1292-1643-1-ND | 0603B104K500CT | CAP CER 0.1UF 50V X7R 0603
2 | Unpolarized capacitor, small symbol | C_Small | C101 C102 C103 C104 C105 C106 C107 C108 | 10u | C_0805_2012Metric | 8 | ~ | C77075 | Murata Electronics | 490-3886-1-ND | GRM21BR61C106KE15L | CAP CER 10UF 16V X5R 0805
3 | RGB LED, 6 pin package with exposed pad | LED_RGBW_EP | D101 | Cree XM-L | LED_Cree_XM-L_20mm_Module | 1 | https://www.cree.com/led-components/media/documents/XLampXML_Color.pdf |  |  |  |  |  | 1
4 | Schottky diode, filled shape | D_Schottky_ALT | D102 | PMEG4030 | D_SOD-123F | 1 | ~ | C389355 |  | 1727-5313-1-ND | PMEG4030ER,115 | DIODE SCHOTTKY 40V 3A SOD123W
5 | Generic connector, single row, 01x03, script generated (kicad-library-utils/schlib/autogen/connector/) | Conn_01x03 | J102 | Conn_01x03 | PinHeader_1x03_P2.54mm_Horizontal | 1 | ~ |  |  |  |  |  | 1
6 | Generic connectable mounting pin connector, single row, 01x08, script generated (kicad-library-utils/schlib/autogen/connector/) | Conn_01x08_MountingPin | J103 | JST 1.25mm | Molex_PicoBlade_53261-0871_1x08-1MP_P1.25mm_Horizontal | 1 | ~ | C29041 |  | WM7626CT-ND | 0532610871 | 1.25mm JST-like 01x08
7 | DC Barrel Jack with an internal switch | Barrel_Jack_Switch | J101 | PJ-102AH | BarrelJack_CUI_PJ-102AH_Horizontal | 1 | ~ | C84007 |  | CP-102AH-ND | PJ-102AH | CONN PWR JACK 2X5.5MM SOLDER
8 | Inductor with ferrite core | L_Core_Ferrite | L101 L102 L103 L104 | 4.7u | L_Taiyo-Yuden_MD-4040 | 4 | ~ | C206284, C15269 |  | 587-5994-1-ND | SLW4030S4R7MST | 4.7uH ±20% 2A 60mΩ SMD,4x4x3mm
9 | N-MOSFET transistor, gate/source/drain | Q_NMOS_GSD | Q101 Q102 Q103 Q104 | Si2302CDS-T1 | SOT-23 | 4 | https://www.vishay.com/docs/68645/si2302cds.pdf | C10488 |  | SI2302CDS-T1-E3CT-ND | Si2302CDS-T1 | MOSFET N-CH 20V 2.6A SOT-23 |  | 0.045@1A
10 | Resistor, US symbol | R_US | R101 R104 R105 R108 | 0.120 | R_0805_2012Metric | 4 | ~ | C186575, C171368 |  | RL12S.12FCT-ND | SR732ATTDR120F | 0.12 0805 330mW
11 | Resistor, US symbol | R_US | R102 R103 R106 R107 | 0.270 | R_0805_2012Metric | 4 | ~ | C186583, C171374 |  | RL12S.27FCT-ND | SR732ATTDR270F | 0.27 0805 330mW
12 | Resistor, US symbol | R_US | R117 R122 | 33 | R_0603_1608Metric | 2 | ~ | C108661 |  | 311-33.0HRCT-ND | RC0603FR-0733RL
13 | Resistor, US symbol | R_US | R109 R110 R111 R112 R113 R118 | 100 | R_0603_1608Metric | 6 | ~ | C105588 |  | 311-100HRCT-ND | RC0603FR-07100RL
14 | Resistor, US symbol | R_US | R114 R115 R116 R119 R120 R121 | 100k | R_0603_1608Metric | 6 | ~ | C14675 |  | 311-100KHRCT-ND | RC0603FR-07100KL
15 | IC INVERTER SCHMITT 6CH | SN74HC14N-dk_Logic-Gates-and-Inverters | U106 | 74HC14D,653 | SOIC-14_3.9x8.7mm_P1.27mm | 1 |  | C5605 | Nexperia | 1727-2783-1-ND | 74HC14D,653 | IC INVERTER SCHMITT 6CH 14SO
16 | 1A, Step-Down CC Led Driver, 250kHz, TSOT-23 | PAM2804 | U101 U102 U103 U104 | PAM2804 | TSOT-23-5 | 4 | https://www.diodes.com/assets/Datasheets/PAM2804.pdf | C71463 | Diodes Incorporated | PAM2804AAB010DICT-ND | PAM2804AAB010 | IC LED DRIVER RGLTR 1A TSOT25
17 | 3-Channel 8-Bit PWM LED Driver, DIP-8/SOIC-8 | WS2811 | U105 U107 | WS2811 | SOIC-8_3.9x4.9mm_P1.27mm | 2 | https://cdn-shop.adafruit.com/datasheets/WS2811.pdf | C114581 | Worldsemi
Project info:
Schematic: | Cree_XML_Driver
Variant: | default
Revision:
Date: | 2021-01-18_14-16-22
KiCad Version: | 5.1.7-a382d34a8~87~ubuntu18.04.1
Statistics:
Component Groups: | 17
Component Count: | 53
Fitted Components: | 53
Number of PCBs: | 1
Total Components: | 53

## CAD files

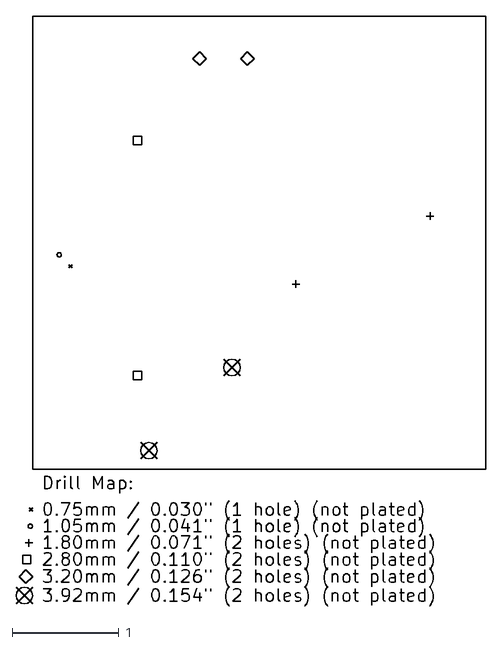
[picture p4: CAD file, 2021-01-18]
build/gerber/SD1-NPTH_drill_map.dxf
4.41 x 5.53

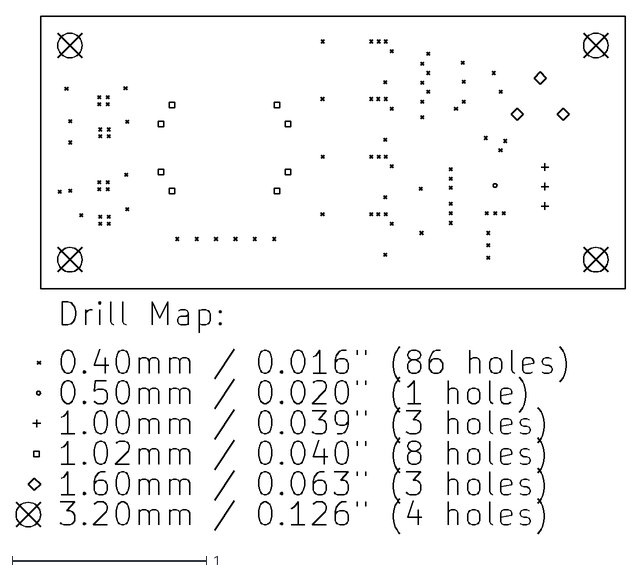
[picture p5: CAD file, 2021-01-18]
subprojects/Cree_XML_Driver/build/gerber/Cree_XML_Driver-PTH_drill_map.dxf
3.13 x 2.66

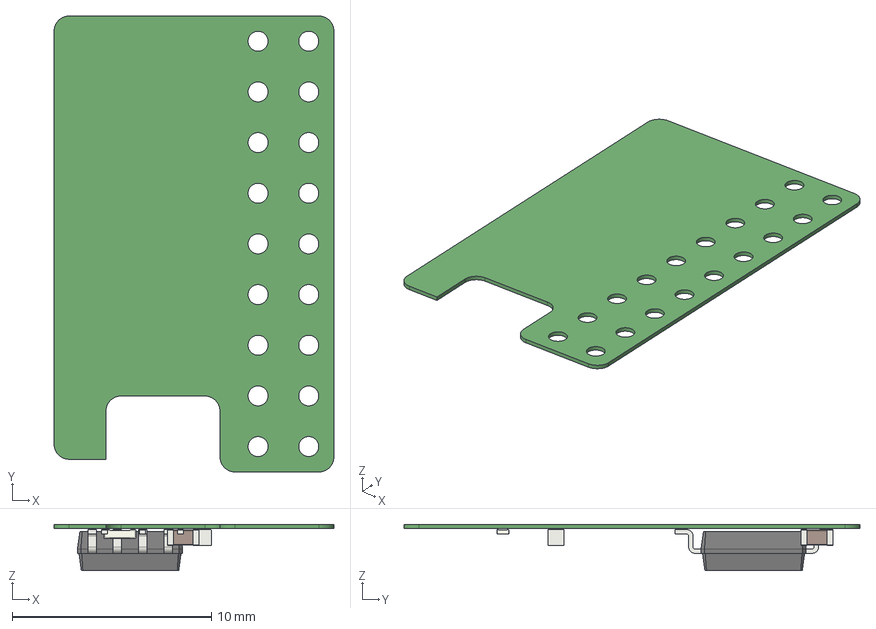
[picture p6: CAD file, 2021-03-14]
subprojects/FLASH_MOD/build/cad/FLASH_MOD.step
14.0 x 22.9 x 2.32 mm

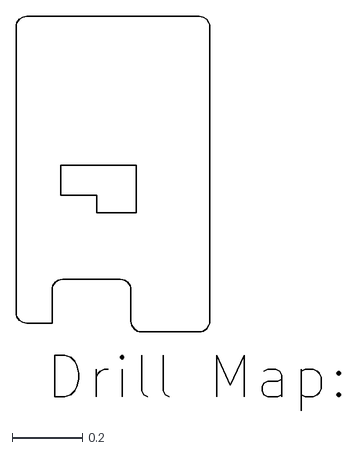
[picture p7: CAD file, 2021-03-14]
subprojects/FLASH_MOD/build/gerber/FLASH_MOD-NPTH_drill_map.dxf
0.926 x 1.12

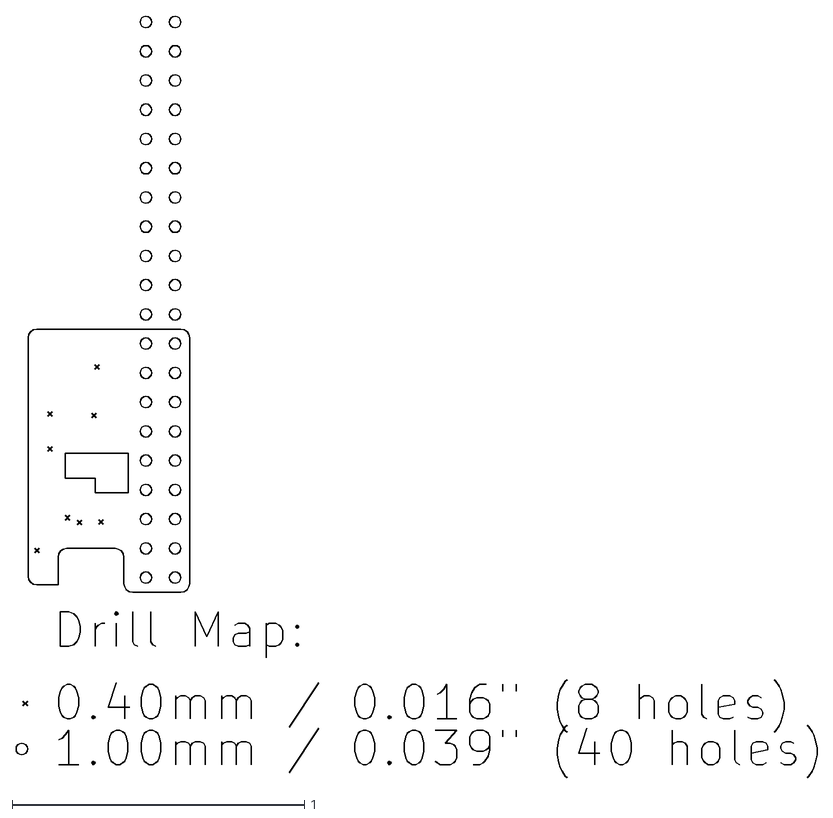
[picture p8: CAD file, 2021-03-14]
subprojects/FLASH_MOD/gerber/FLASH_MOD-PTH-drl_map.dxf
2.74 x 2.60

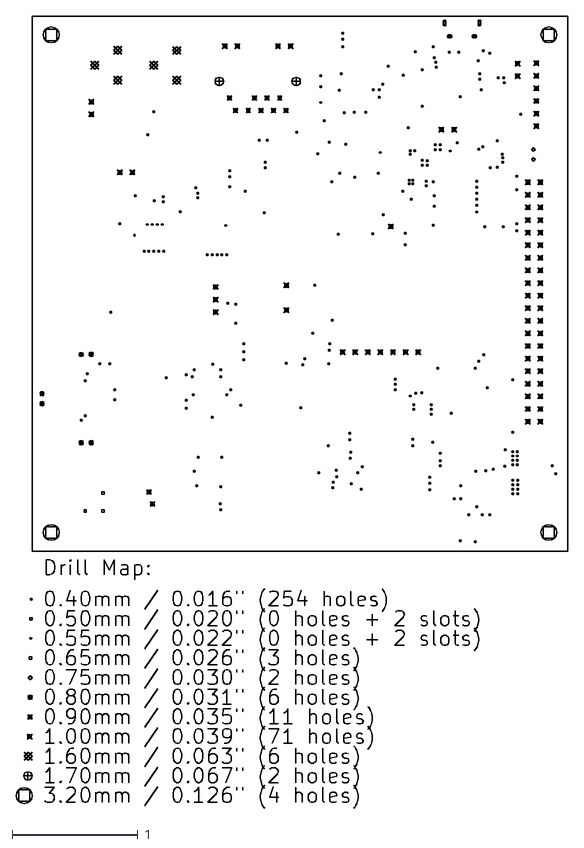
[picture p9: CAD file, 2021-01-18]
build/gerber/SD1-PTH_drill_map.dxf
4.38 x 6.29

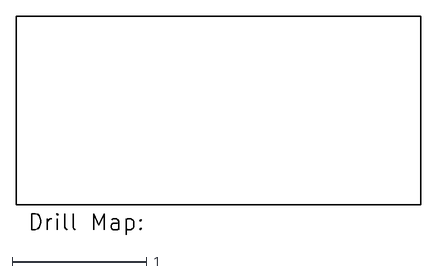
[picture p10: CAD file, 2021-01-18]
subprojects/Cree_XML_Driver/build/gerber/Cree_XML_Driver-NPTH_drill_map.dxf
3.00 x 1.62

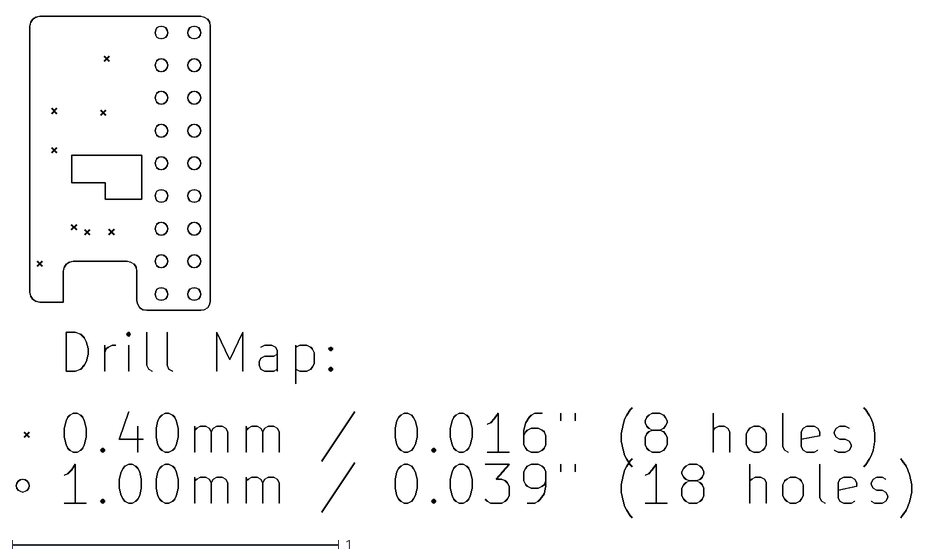
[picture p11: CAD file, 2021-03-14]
subprojects/FLASH_MOD/build/gerber/FLASH_MOD-PTH_drill_map.dxf
2.74 x 1.53

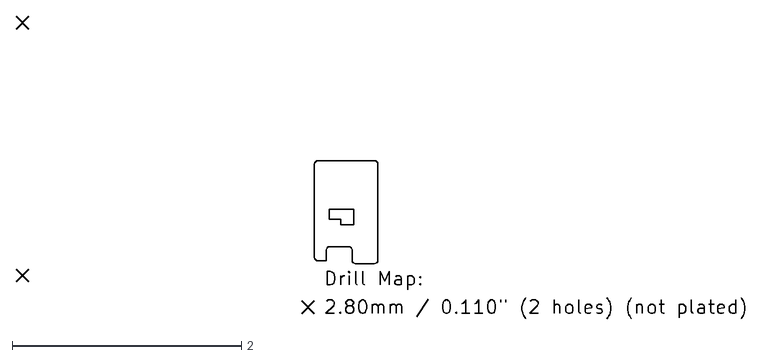
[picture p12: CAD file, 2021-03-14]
subprojects/FLASH_MOD/gerber/FLASH_MOD-NPTH-drl_map.dxf
6.36 x 2.64

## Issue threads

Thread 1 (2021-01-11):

Incorrect footprints: ideal doide fet

clayton13, 2021-01-11:
Q301 and Q801 both have SOT-23-6 footprints when the physical part is really just a SOT-23.

clayton13, 2021-01-11:
As the board is in the middle of SMT we cannot change the PCB design. To wiremod this we will need to do the following:

| Part | Pcbnew | 3D |
| --- | --- | --- |
| Q301 | |
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

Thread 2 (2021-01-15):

Incorrect footprint:    RF-BM-2652P2

clayton13, 2021-01-15:
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

clayton13, 2021-01-15:
Now that its morning, I can more clearly describe the issue.

## Antenna options
The [datasheet](https://www.szrfstar.com/download/604-en.html) lists the following:
> RF-BM-2652P2 integrates three kind of antenna output modes: PCB, IPEX connector and half-hole interface,
which make the module more convenient for application and development.

Meaning there are 3 antenna configuration based on the jumper configuration on the top of the board:

1. Internal Embedded PCB Antenna 🔴
2. External IPEX 🔵
3. External on the parent board 🟢

## Module documentation
| Functional Schematic | PCB | Desc |
| --- | --- | --- |
| 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 | 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 | Position 1[🔴]  and 2[🔵+🟢] control which antenna configuration is being used. <br><br> When not in use, the other channel is left floating. |

## Our case
For our case, as we are using the factory default of Position 1, the `ANT` #3 🟢 signal, exposed on the half-hole interface, is fully floating and not connected to anything. As it is completely floating, it will not be and issue if the pin were to be shorted to the nearby `GND` pad.

The current board can be manufactured as planned with no changes.

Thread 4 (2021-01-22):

Incorrect footprint design: RGB LED, D101 - 19-237/R6GHBHW-C01/2T

clayton13, 2021-01-22:
The assembler caught this and came up with a solution, of merely rotating the part 90deg. If one zooms in on the left photo it can be more clearly seen.

| PIC | Footprint |
| --- | --- |
| 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 | 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 |

clayton13, 2021-01-22:
Researching the root cause, I made the mistake as the datasheet did not indicate the footprint numbering was from the bottom view, so the pads' numbering is reversed.

This can be further checked if one looks at the die and observes the 3 gold bond wires meeting at the common anode.

The correct view is as follows:
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

clayton13, 2021-01-22:
As it looks like we can get away with the rotated part, as in no shorts. The color mapping will have to be changed. The color mapping for this revision can be found as follows.

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

The previous mapping is shown in yellow where the new mapping is in pink. This means that software we will have to swap the red and blue channels when interfacing with this led.

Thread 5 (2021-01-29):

Ethernet jack 3D model going through board surface

clayton13, 2021-01-29:
The J201 jack is not properly offset in the part. This directly drives the connector faceplate in SolidWorks and as such should be amended here. I have added a fix there, but going forward we should fix this. See image:

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

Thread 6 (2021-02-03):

Flyback reference not correct

clayton13, 2021-02-03:
The U302 reference was correctly chosen as a TL431 ([TL431ACDBZR](https://www.digikey.com/en/products/detail/texas-instruments/TL431ACDBZR/686855)) which has a reference voltage of 2.5V instead of the expected 1.24V. This has the effect of doubling the expected 5V output from the flyback.

clayton13, 2021-02-03:
I see two possible solutions:

1. Recalculate the feedback resistors to match, R315 and R324
2. Purchase the expected TL**V**431 and put in its place.

clayton13, 2021-02-11:
As option 2 does not work due to incompatible footprints so we will proceed with option 1.

This is an easy calculation to get 5V as it is exactly double the 2.5V reference so if two identical resistors are used in the range of 30k - 100k the output voltage would be suitable. However, under load this voltage my droop so we want to aim a little higher.

Taking advantage of the existing 41.2k and a parallel combo of common 75k and 100k (42.857k equivalent) generates an output voltage of 5.10V.

| Original | Modded |
| --- | --- |
| | <ol><li>Desolder R324 (marking is **13C**), discard</li><li>Move R315 to R324 (marking is **60C**)</li><li> Solder 100k on R315</li><li>Solder 75k ontop of R315</li></ol>|
| 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  | 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 |

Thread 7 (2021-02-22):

CO Sensor, analog ground reference not connected

clayton13, 2021-02-22:
The LMP91000's GNDA is not directly connected to the system digital GND or to the ground of the ADC.

clayton13, 2021-02-23:
Temporary fix: simply short the localized GNDA into system global GND. This can be achieved by shorting The GNDA side of R601 or C601 to the ground pour.

Going forward: a local nettie will have to be added or GNDA should be replaced with GND.

| Schematic | Options |
| --- | --- |
| 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  | 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

After employing the 🔴 option above, I was able to get correct (enough) analog readings from the LMP's internal temperature sensor.  The separated grounds lead to an erroneous measurement of ~0.5V over expected.

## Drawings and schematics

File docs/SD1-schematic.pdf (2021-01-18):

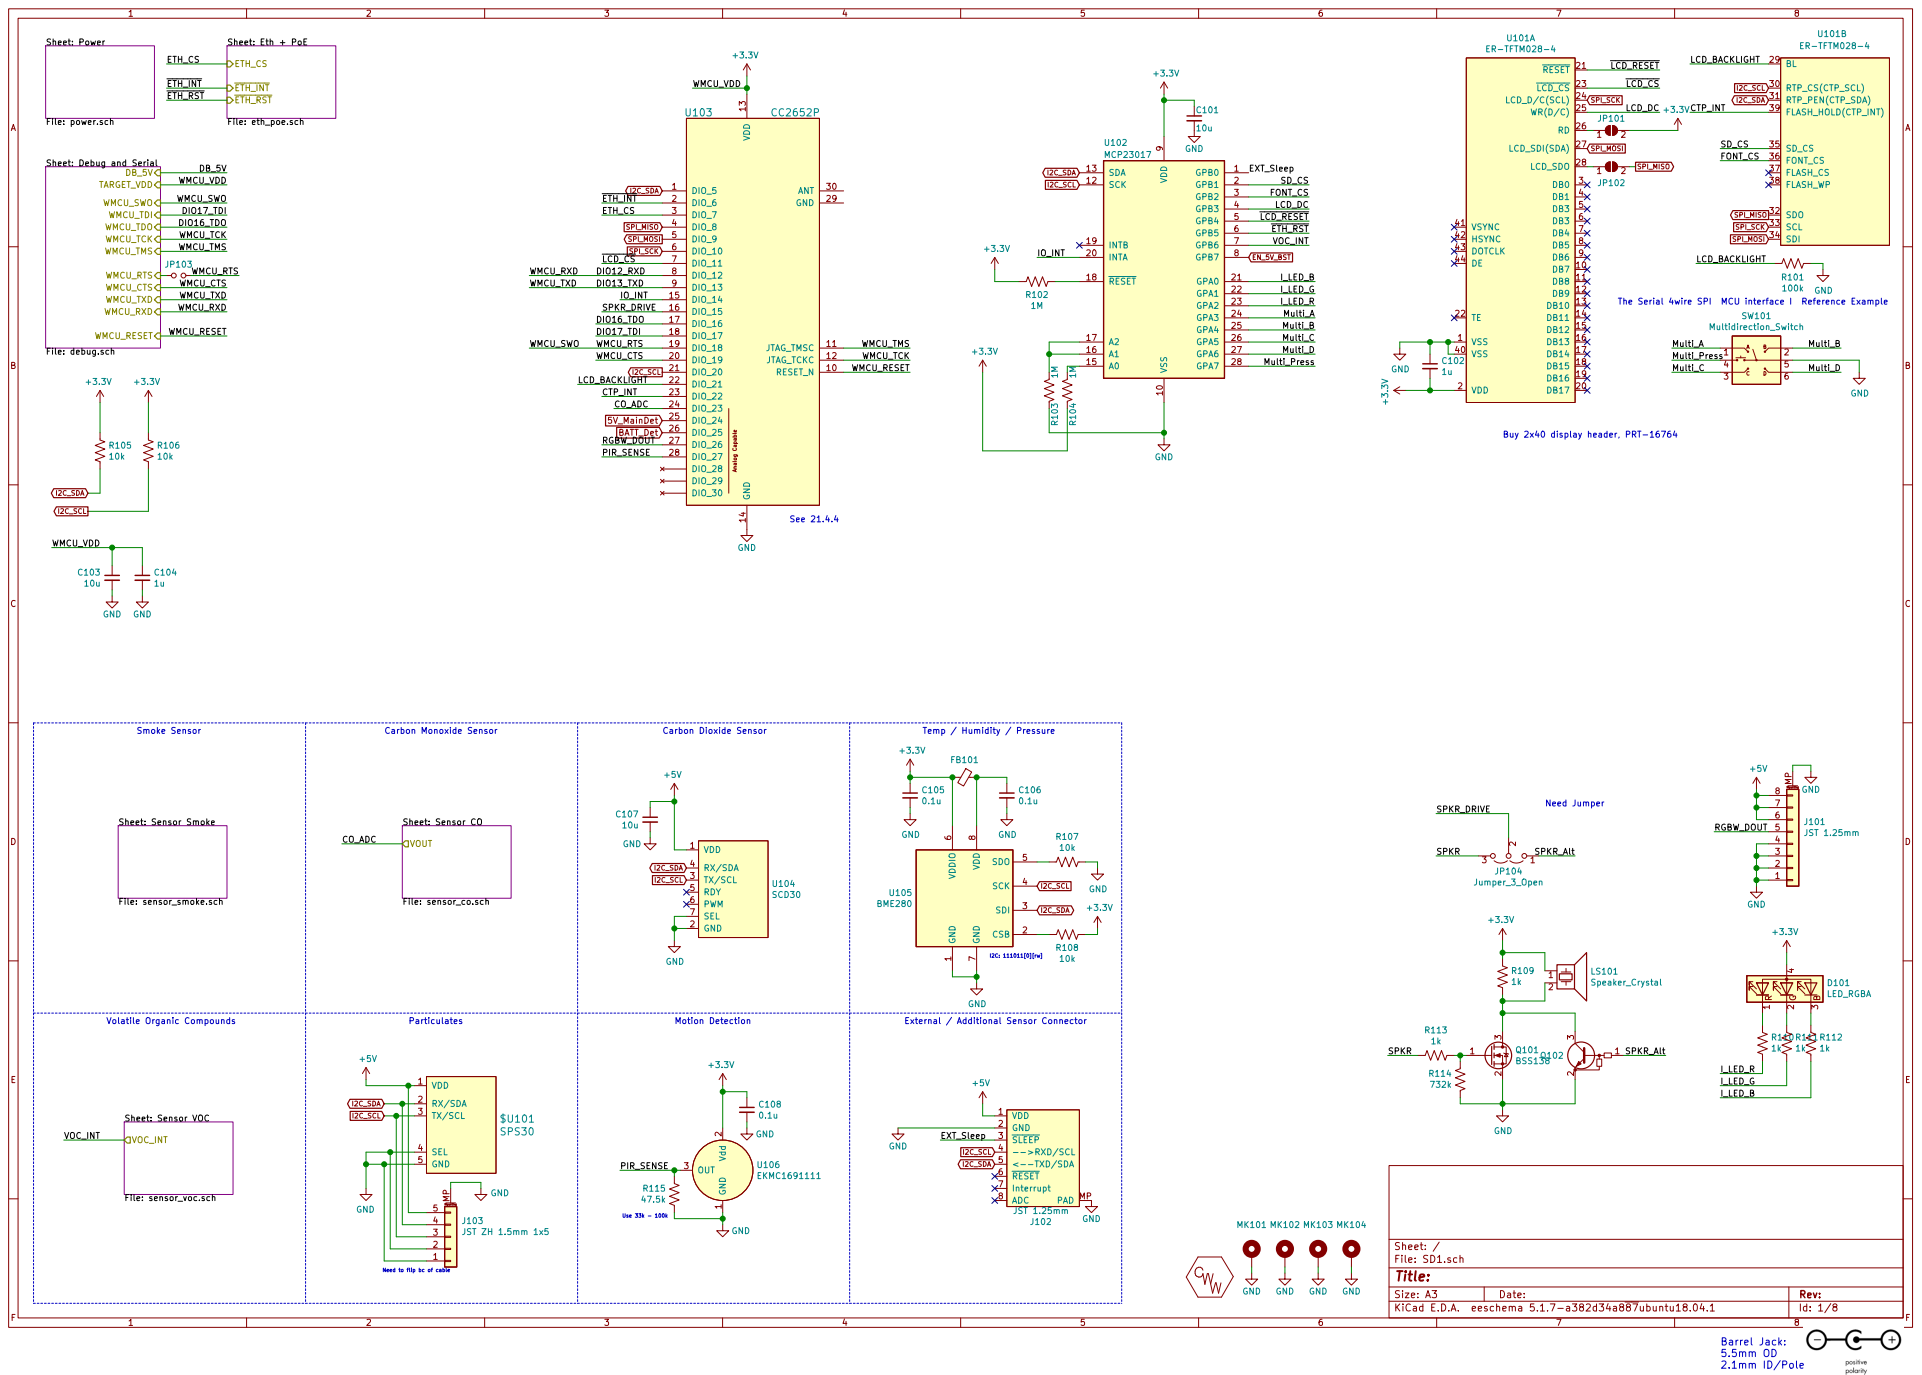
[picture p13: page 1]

The Serial 4wire SPI MCU interface I Reference Example See 21.4.4

Temp / Humidity / Pressure Particulates

1 CSB 2 SDI 3 SCK 4 SDO 5 VDDIO

Id: 1/8 Title: File: SD1.sch Sheet: /

Need to flip bc of cable

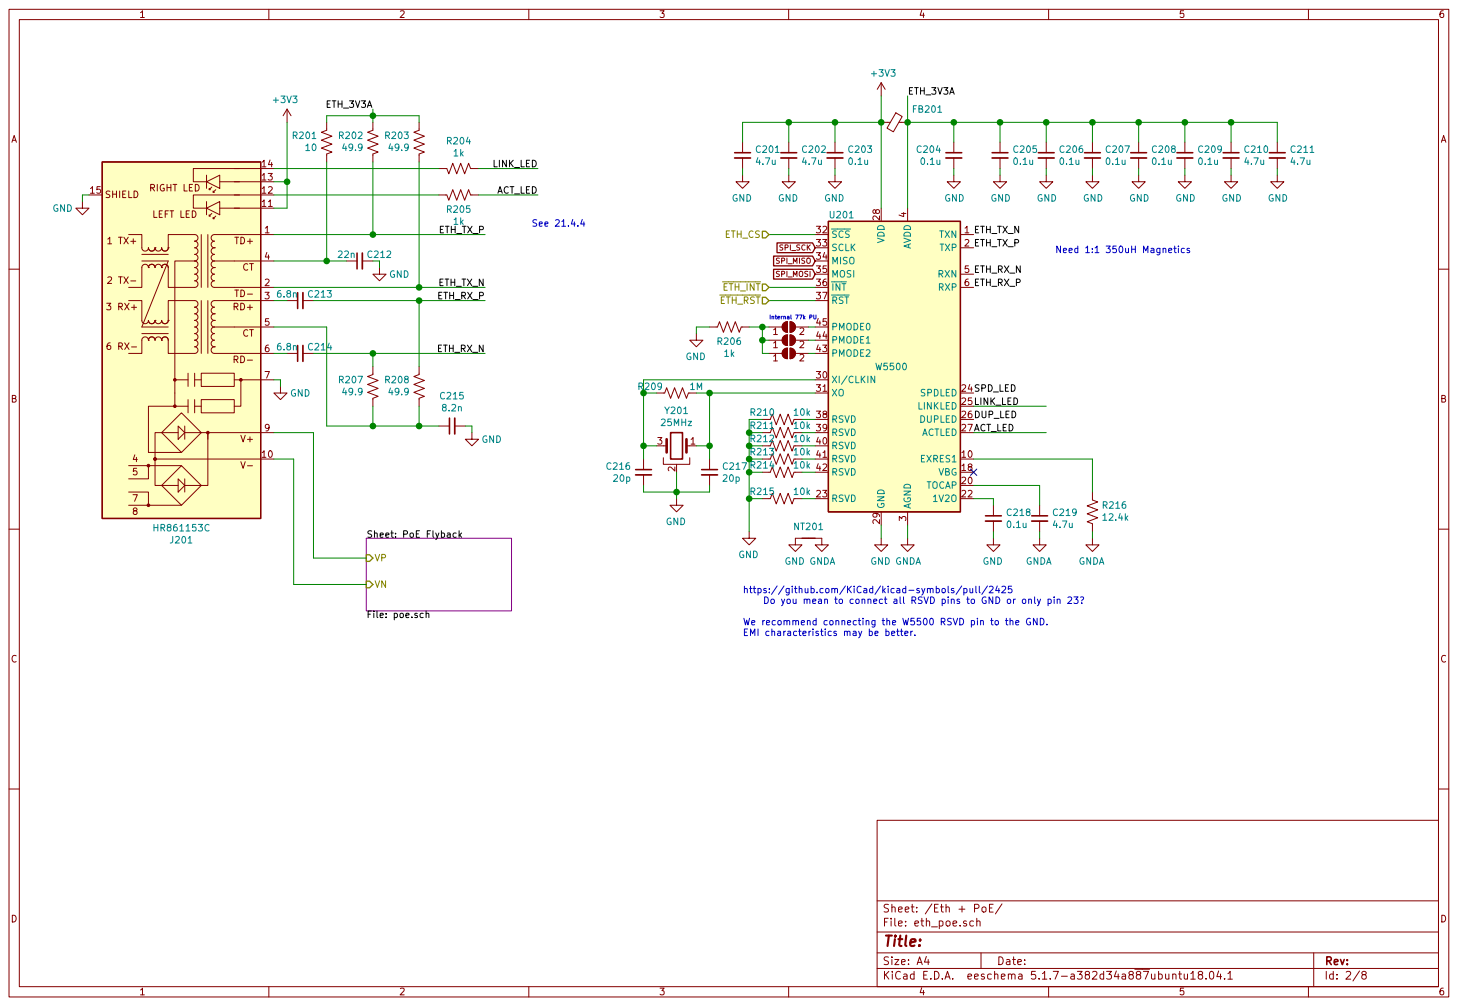
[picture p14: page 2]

V+V- CT RD+ RIGHT LED

4 RSVD 40 RSVD 41 RSVD 42 PMODE2 43 PMODE1 44 PMODE0 45 RXN 5 RXP 6 U201 W5500 GND

3 XI/CLKIN 30 XO 31 SCS 32 SCLK 33 MISO 34 MOSI 35

File: eth_poe.sch Sheet: /Eth + PoE/ Sheet: PoE Flyback

File: poe.sch VP

https://github.com/KiCad/kicad-symbols/pull/2425
Do you mean to connect all RSVD pins to GND or only pin 23?

We recommend connecting the W5500 RSVD pin to the GND.
EMI characteristics may be better.

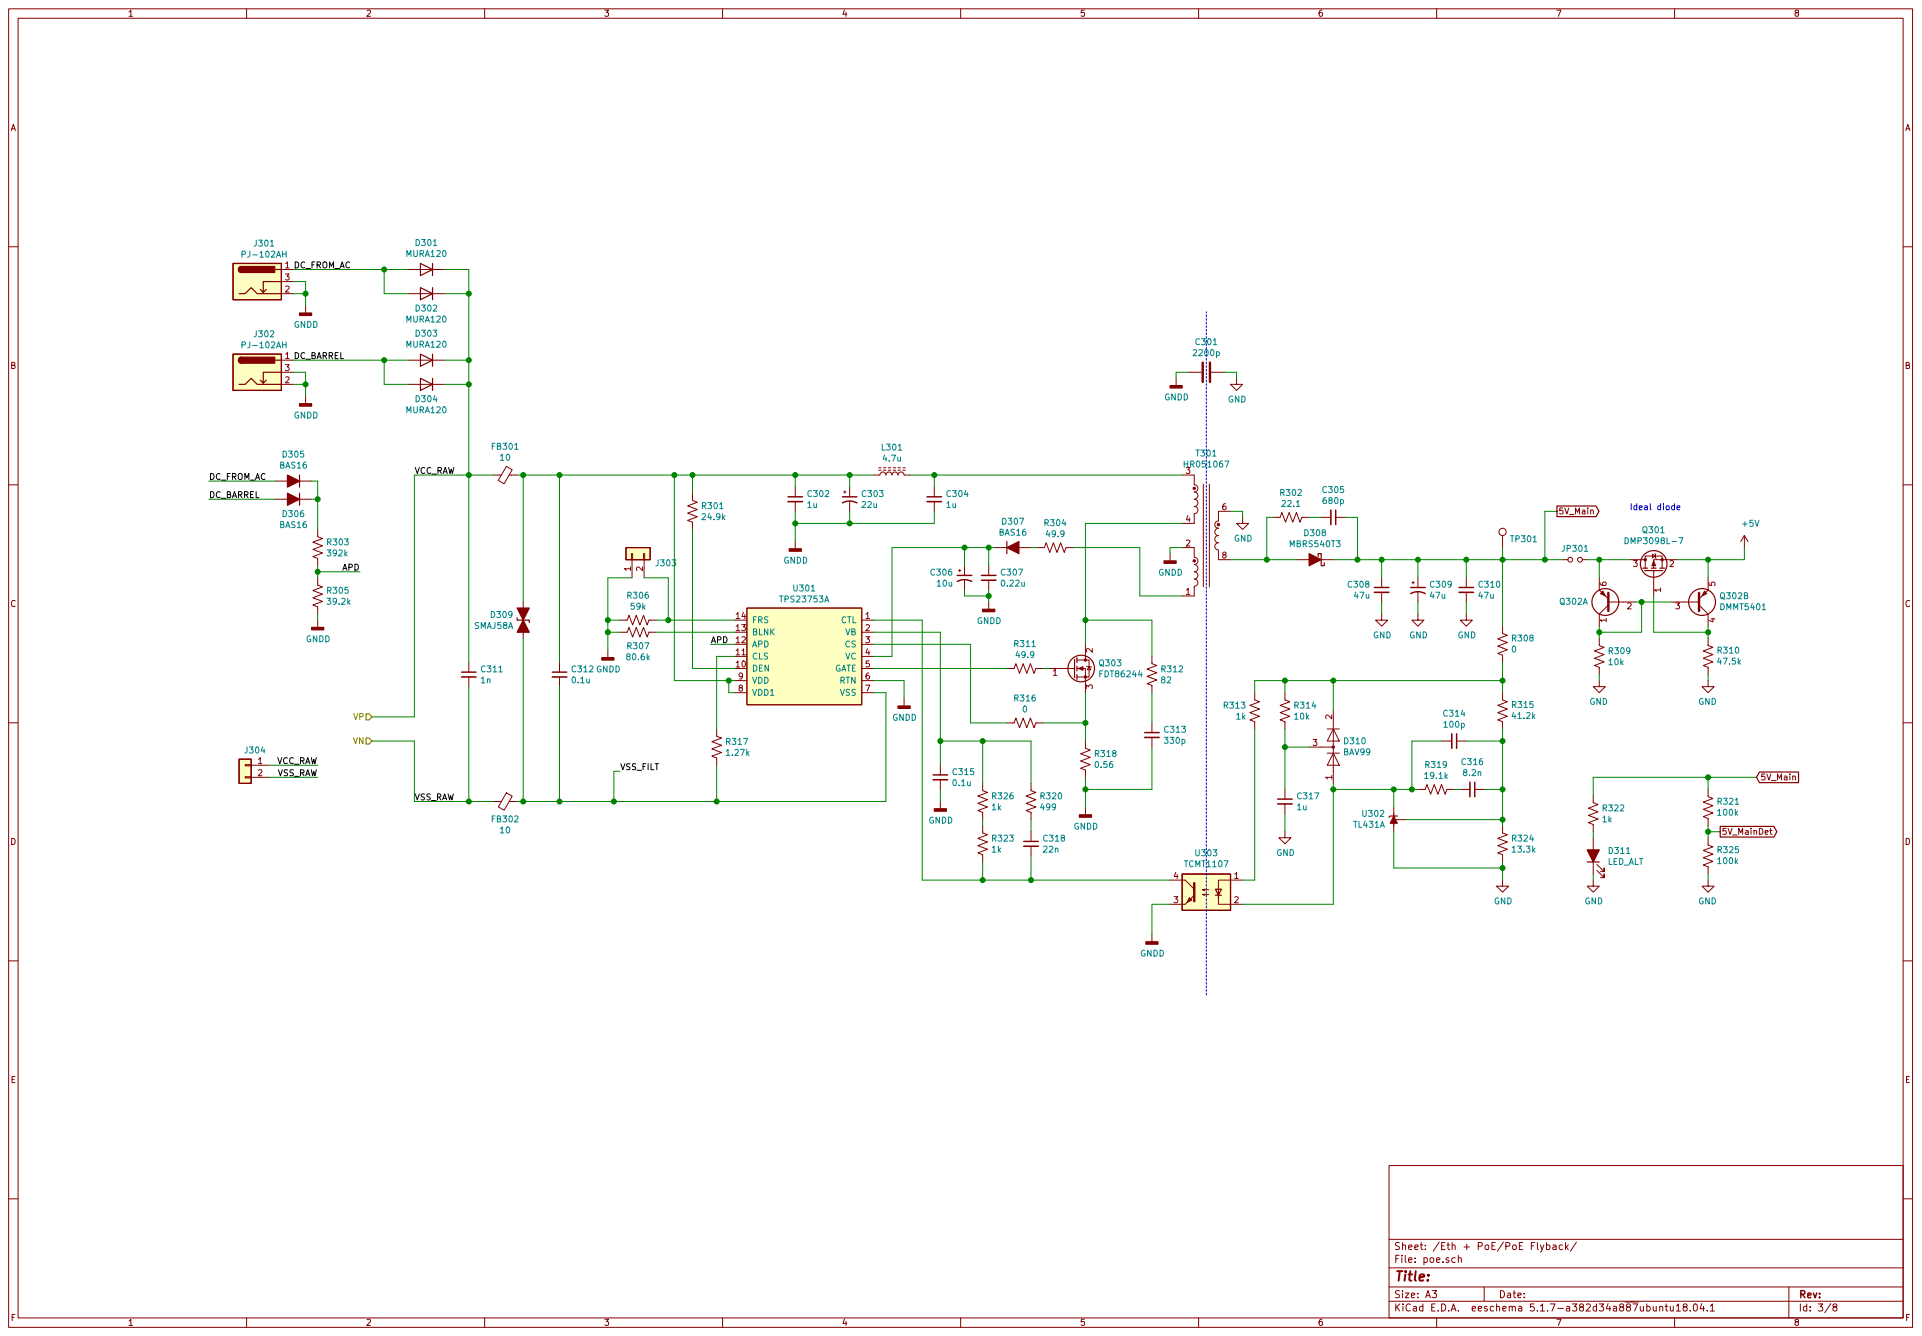
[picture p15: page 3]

Sheet: /Eth + PoE/PoE Flyback/
File: poe.sch
Id: 3/8 Title:

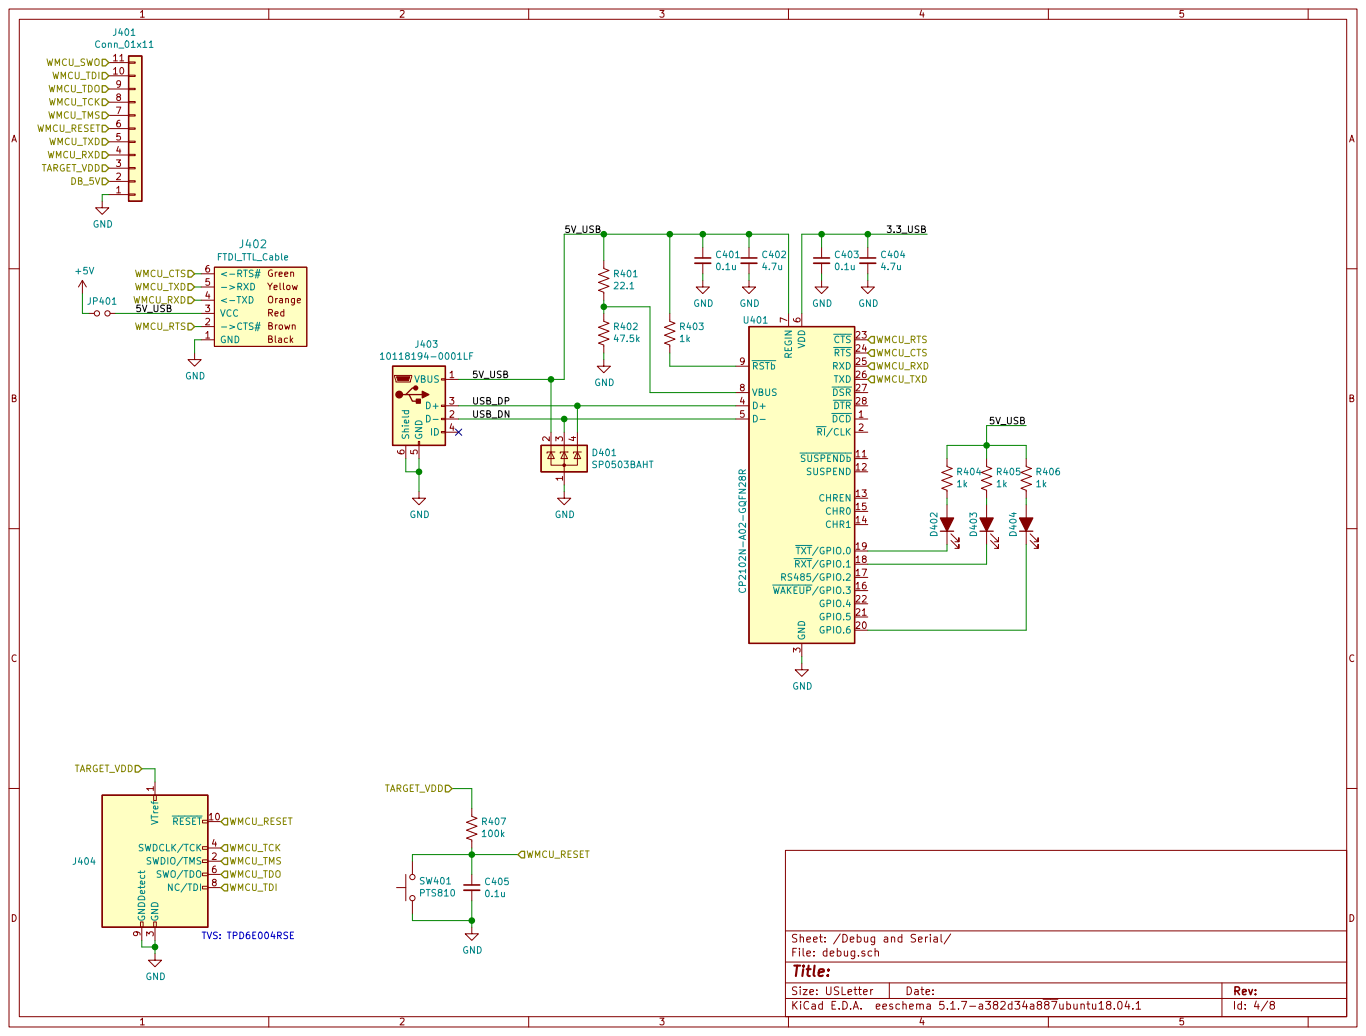
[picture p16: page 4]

FTDI_TTL_Cable GND
Black Brown Green Orange Red Yellow GND 1

Sheet: /Debug and Serial/
File: debug.sch
Id: 4/8 Title:

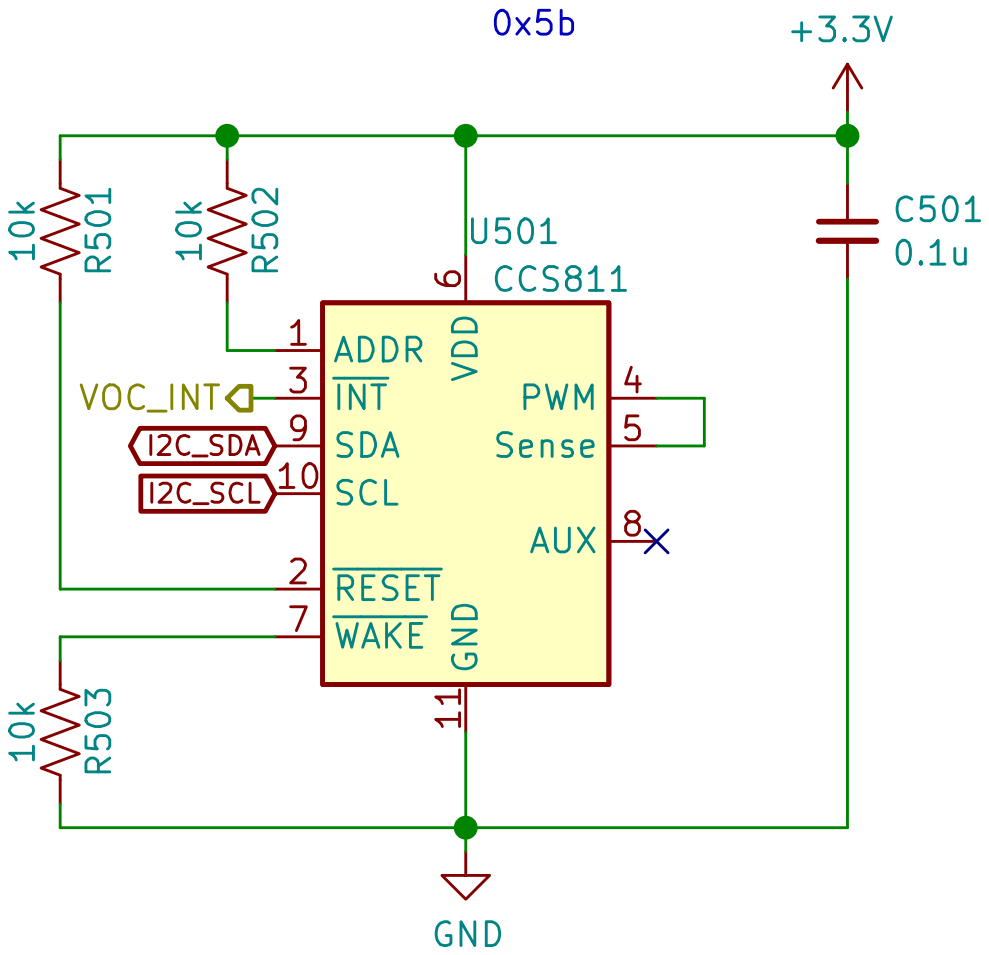
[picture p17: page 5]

File: sensor_voc.sch Sheet: /Sensor VOC/ GND

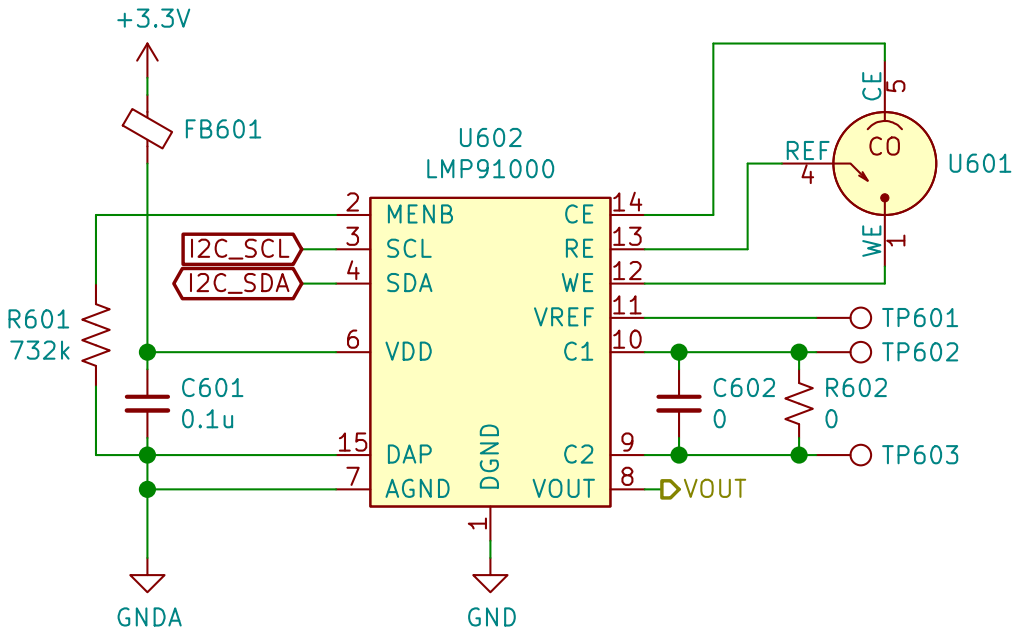
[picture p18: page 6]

1 C1 10 VREF 11 WE 12 RE 13 CE 14 MENB 2 SCL 3 SDA 4 VDD 6 AGND 7 VOUT 8 C2 9 DAP 15 U602

1) No external bias required for CO, thus no accurate bias source for ic

File: sensor_co.sch Sheet: /Sensor CO/
Id: 6/8 Title:

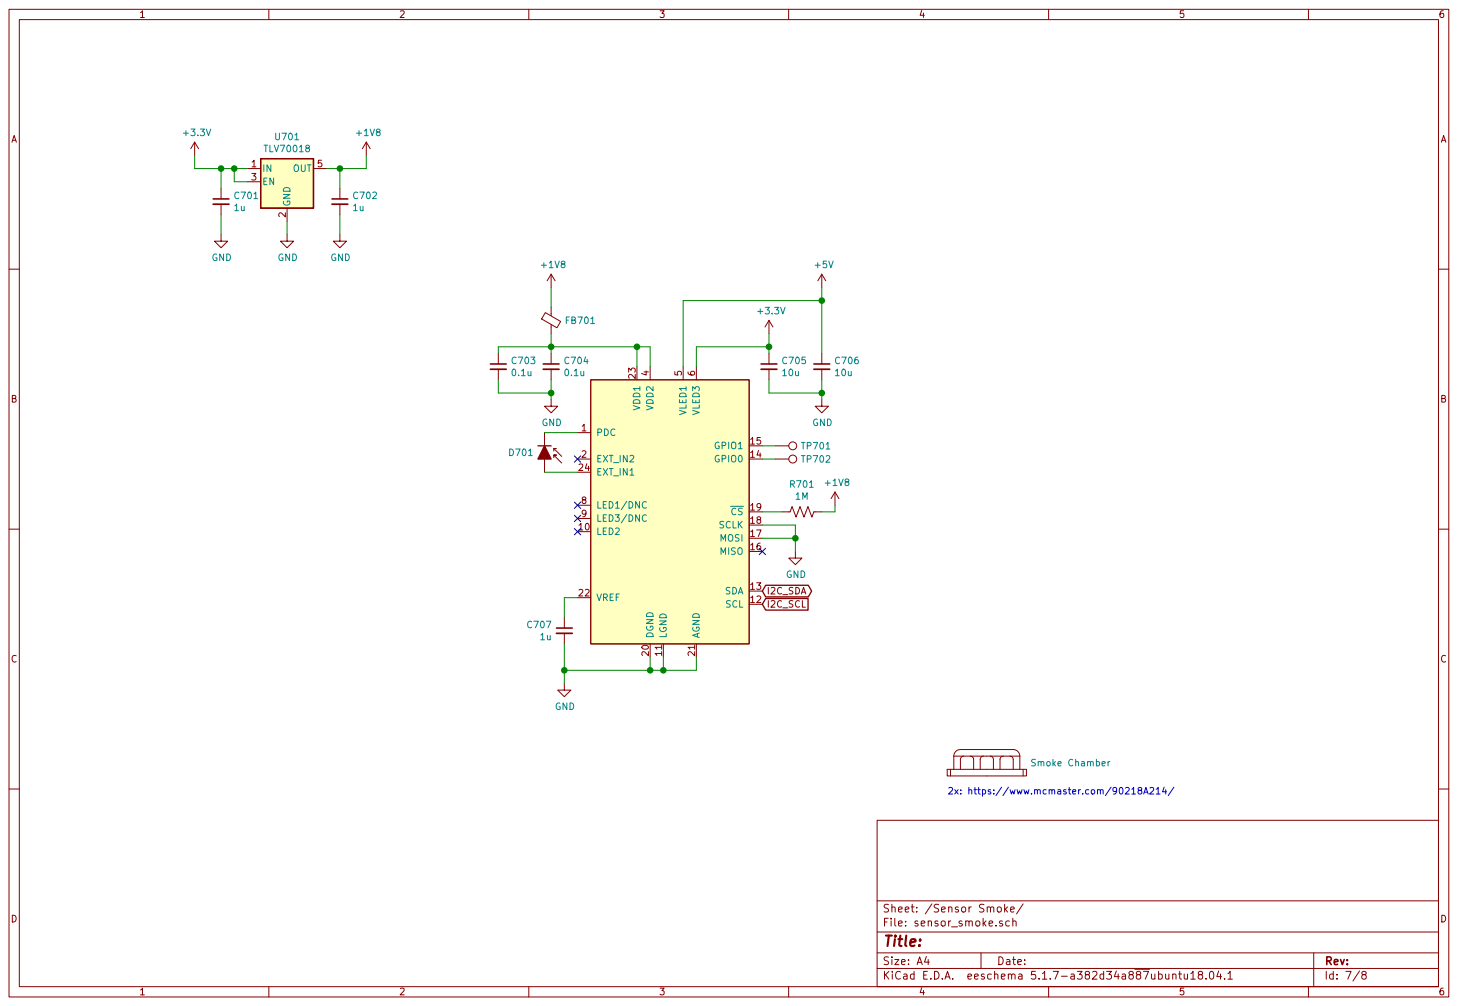
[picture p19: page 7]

2x: https://www.mcmaster.com/90218A214/ SERCOM 0

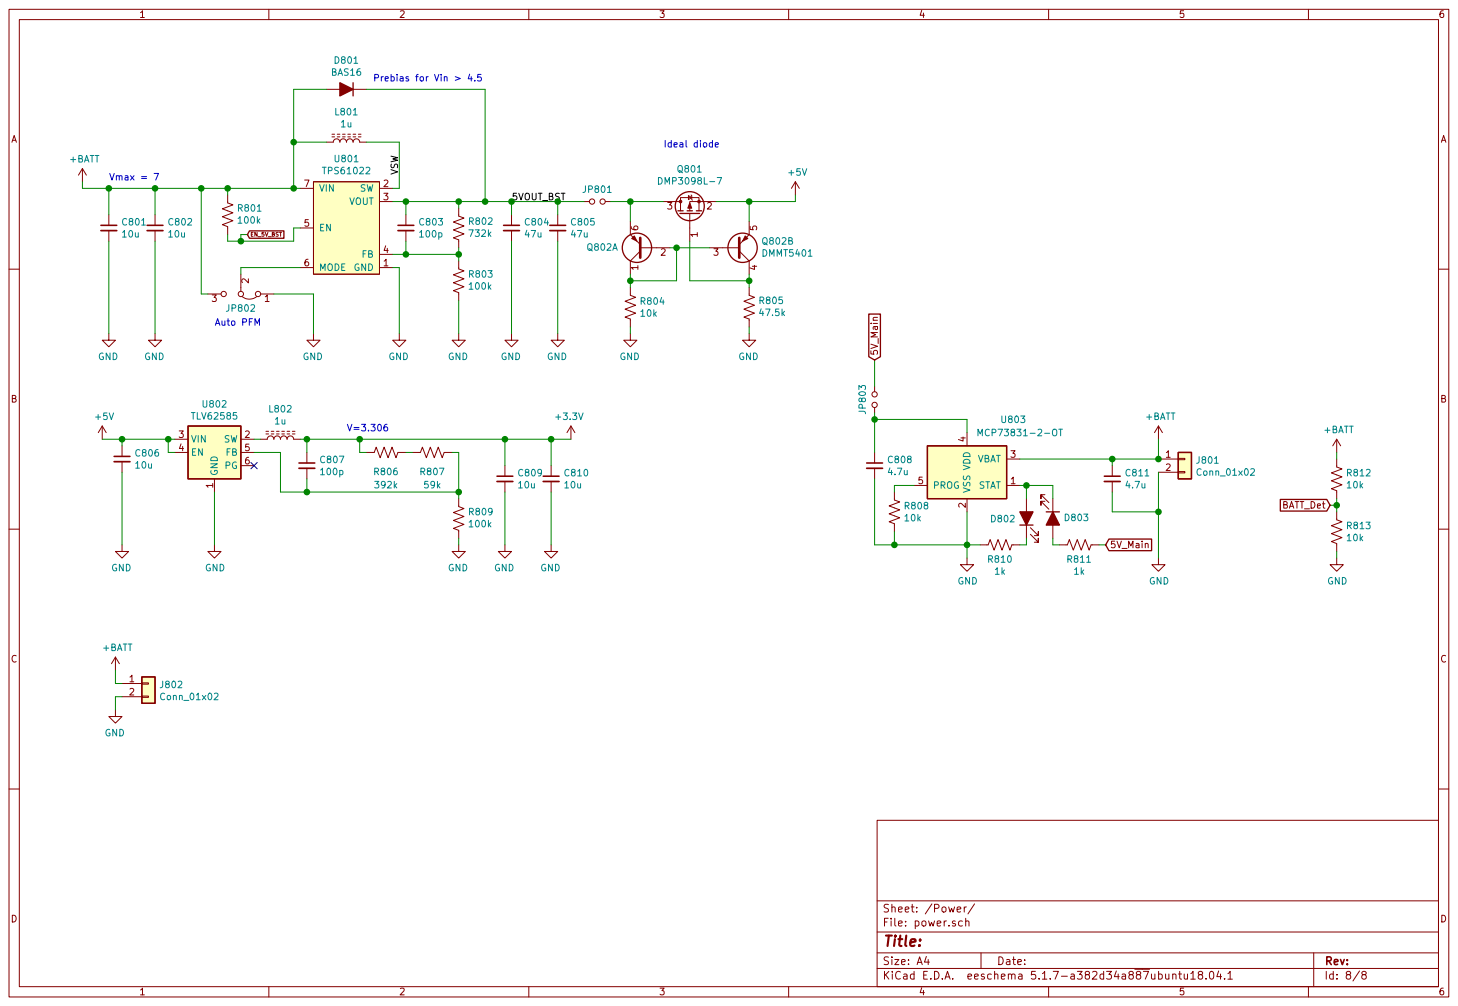
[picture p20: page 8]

Prebias for Vin > 4.5 Vmax = 7

Ideal diode Auto PFM

1 SW 2 VIN 3 EN 4 FB 5 PG 6 U802 TLV62585 R809

File: power.sch Sheet: /Power/
Id: 8/8 Title:

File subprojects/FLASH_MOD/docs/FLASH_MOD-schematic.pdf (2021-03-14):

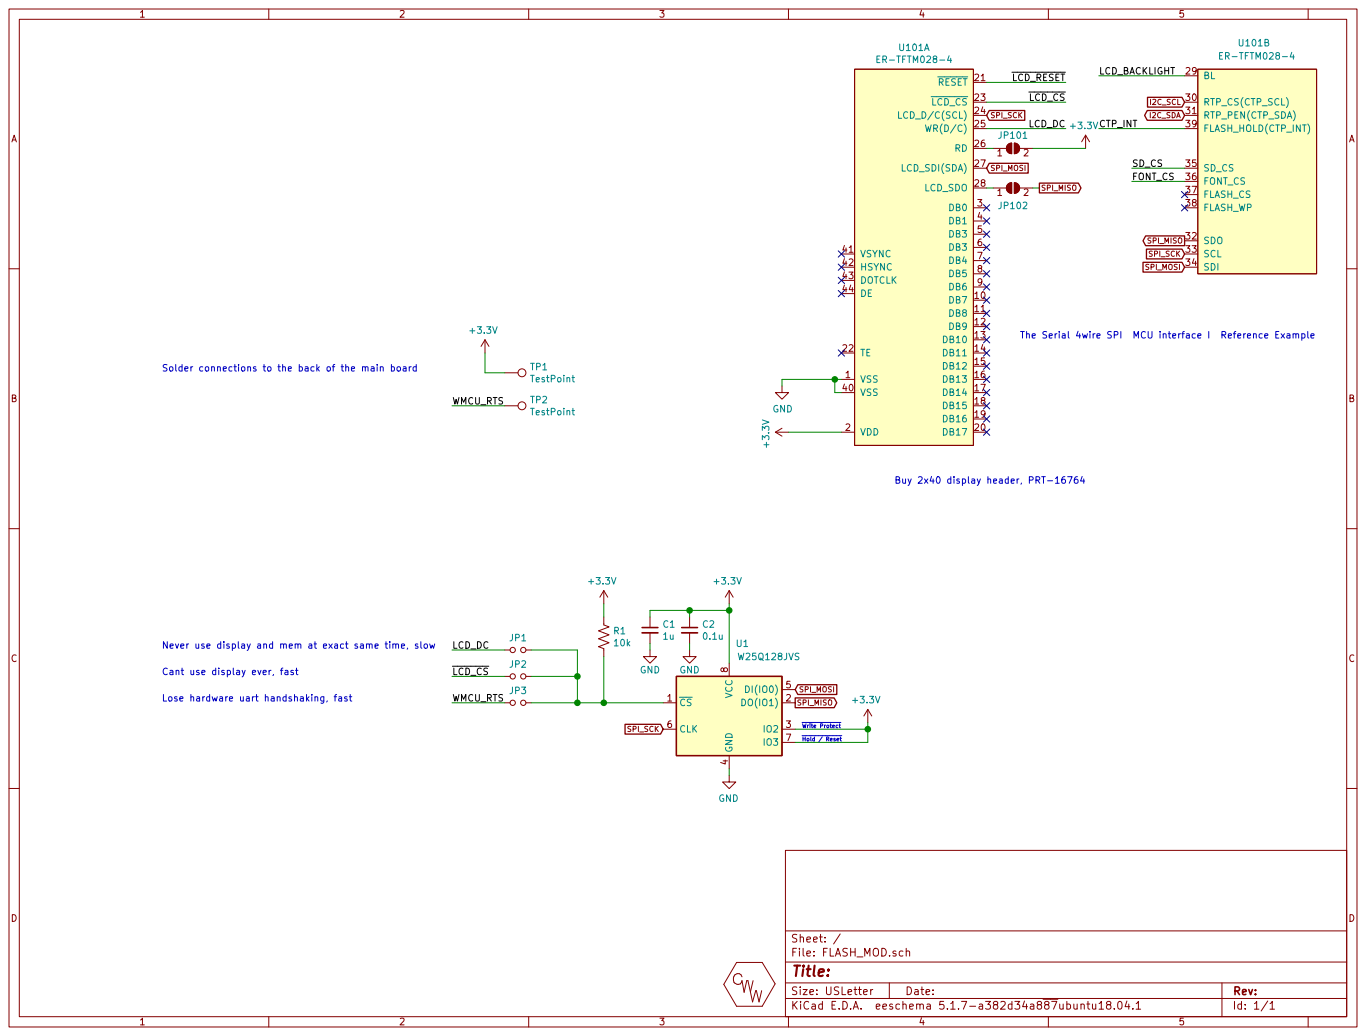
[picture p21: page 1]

The Serial 4wire SPI MCU interface I Reference Example SERCOM 0

Write Protect Hold / Reset Solder connections to the back of the main board Never use display and mem at exact same time, slow

Buy 2x40 display header, PRT-16764

Cant use display ever, fast

Lose hardware uart handshaking, fast

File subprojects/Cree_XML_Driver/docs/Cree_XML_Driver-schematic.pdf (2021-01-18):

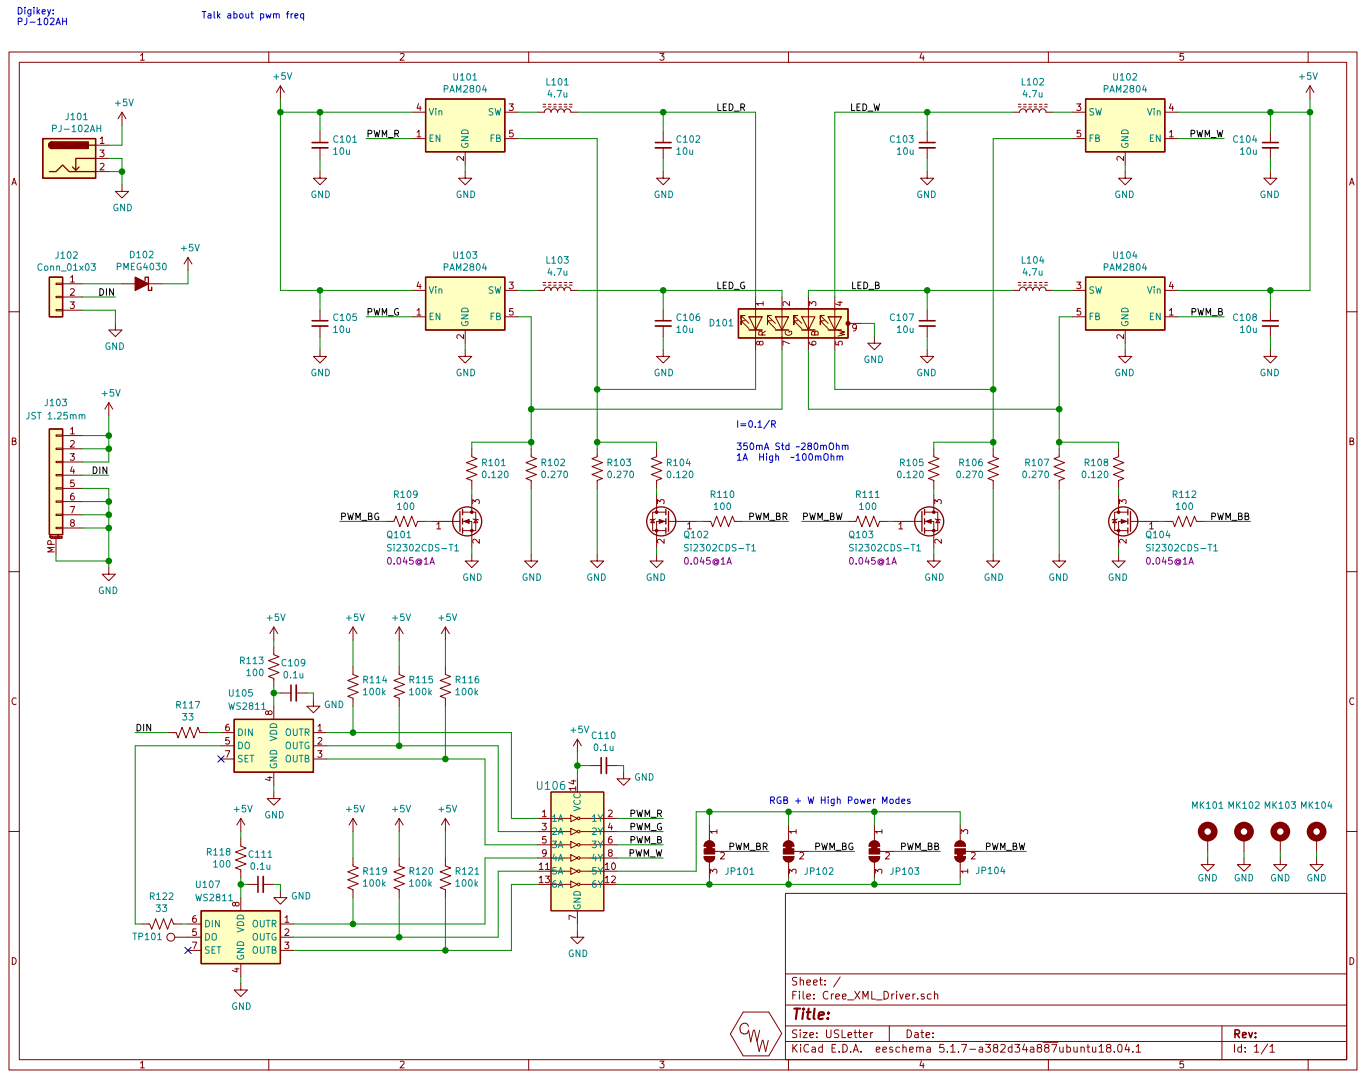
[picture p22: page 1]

Talk about pwm freq

2 SW 3 Vin 4 FB 5 U102 PAM2804 RG

2 SW 3 Vin 4 FB 5 U103 PAM2804 GND MK103 GND GND GND MK102

4.7u GND
RGB + W High Power Modes 350mA Std 280mOhm
1A High 100mOhm

4 DO 5 DIN 6 SET 7 VDD

File: Cree_XML_Driver.sch Sheet: / GND

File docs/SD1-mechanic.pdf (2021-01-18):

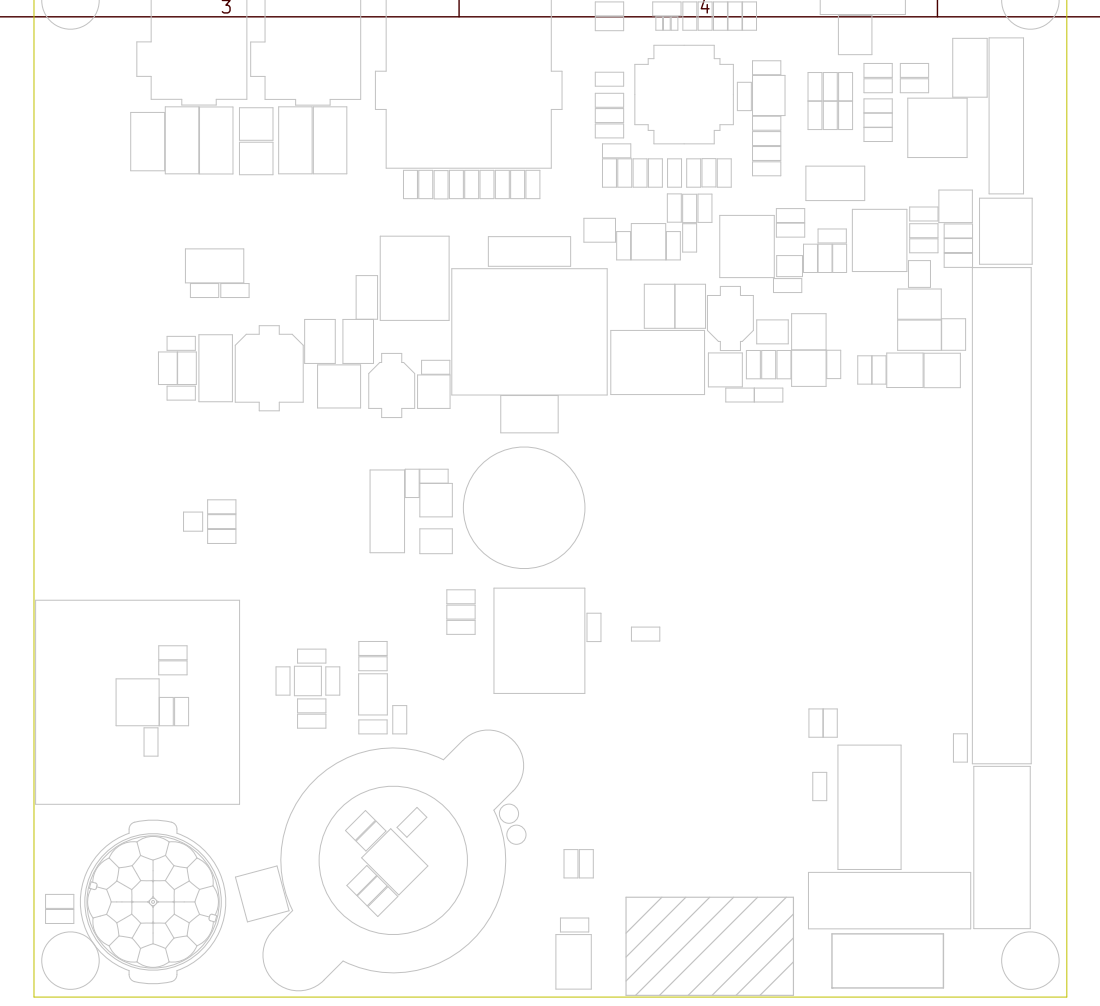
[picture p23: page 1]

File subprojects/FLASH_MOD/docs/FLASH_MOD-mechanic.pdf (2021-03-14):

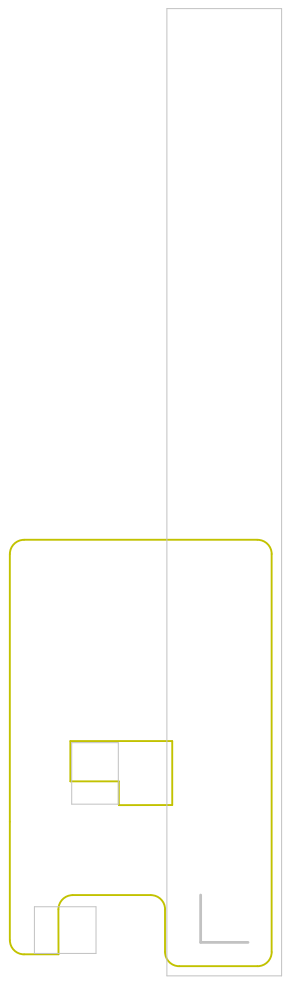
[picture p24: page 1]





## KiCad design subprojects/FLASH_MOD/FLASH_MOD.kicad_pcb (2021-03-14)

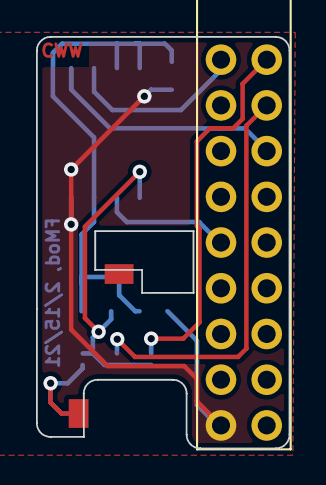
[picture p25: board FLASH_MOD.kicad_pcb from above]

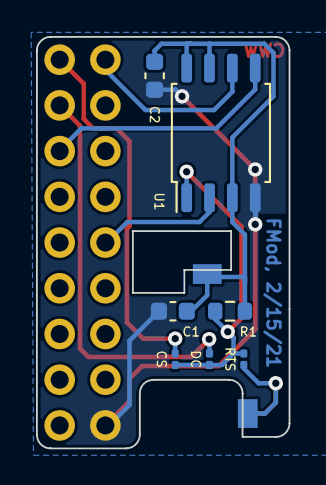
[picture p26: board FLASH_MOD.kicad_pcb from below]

Board: 2 copper layers, 14.0 x 22.9 mm, 10 parts (7 on the bottom side), 9 nets.

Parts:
C1: 1u; C_0603_1608Metric
C2: 0.1u; C_0603_1608Metric
JP1, JP2, JP3: Jumper_NO_Small; R_0201_0603Metric
R1: 10k; R_0603_1608Metric
TP1, TP2: TestPoint; Jumper_ModPad
U1: W25Q128JVS; SOIC-8_5.23x5.23mm_P1.27mm
U101: ER-TFTM028-4

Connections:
+3V3: C1.1, C2.1, R1.1, TP1.1, U1.3, U1.7, U1.8
/LCD_DC: JP1.1, U101.25
/WMCU_RTS: JP3.1, TP2.1
/~LCD_CS: JP2.1, U101.23
GND: C1.2, C2.2, U1.4, U101.40
unnamed: JP1.2, JP2.2, JP3.2, R1.2, U1.1
SPI_MISO: U1.2, U101.32
SPI_MOSI: U1.5, U101.27, U101.34
SPI_SCK: U1.6, U101.24, U101.33

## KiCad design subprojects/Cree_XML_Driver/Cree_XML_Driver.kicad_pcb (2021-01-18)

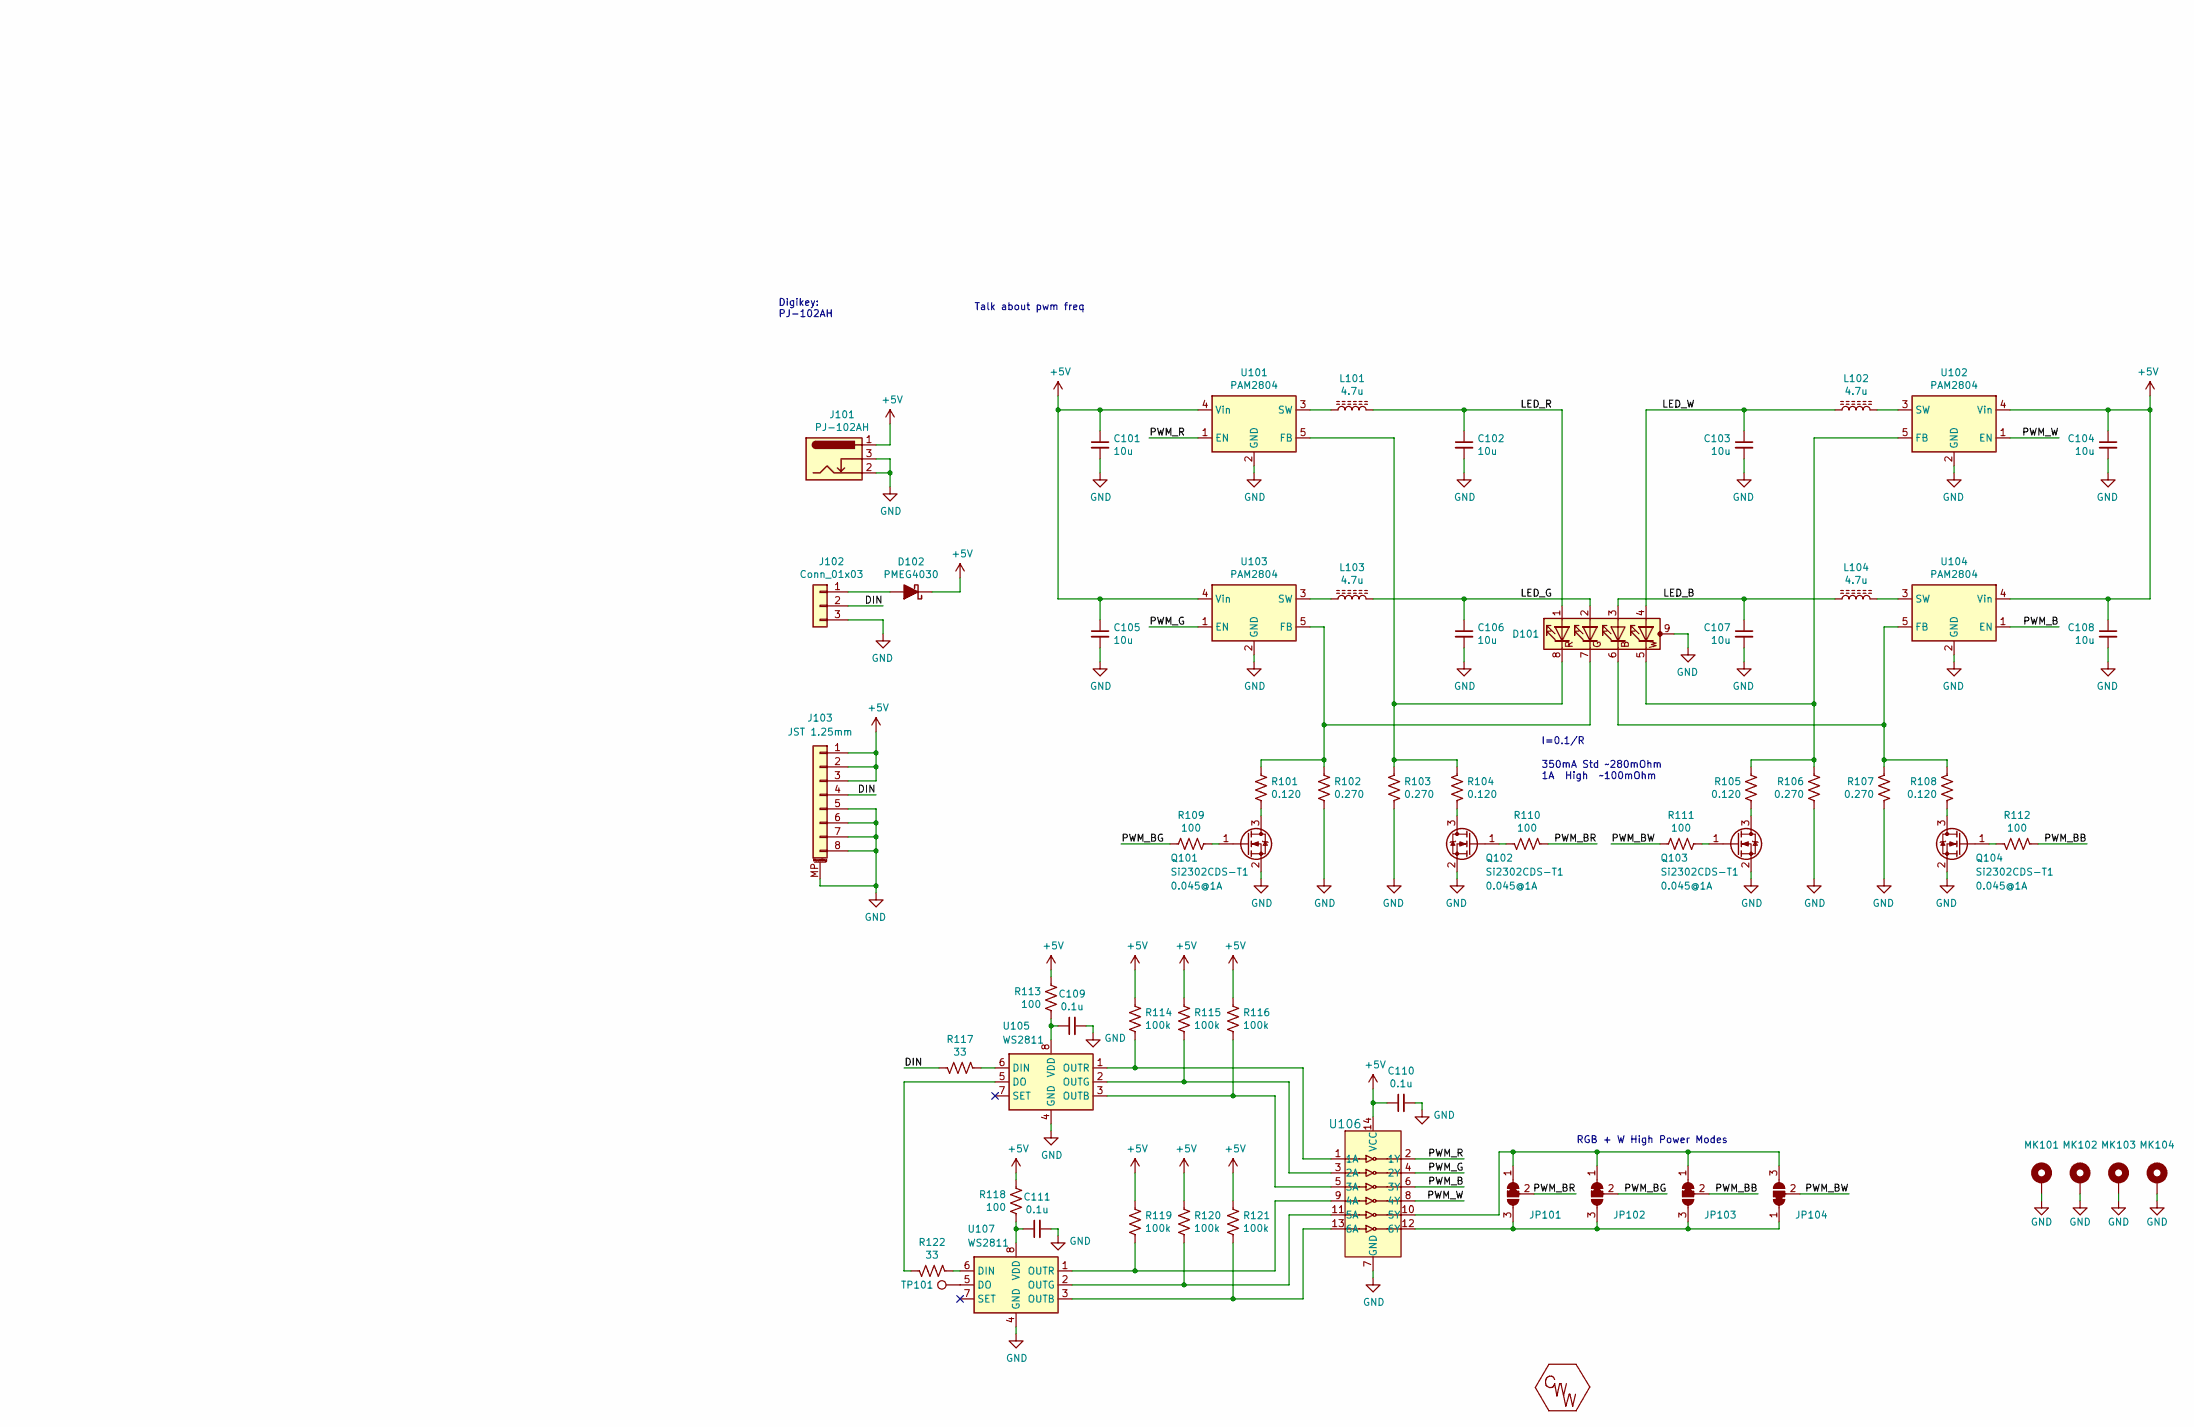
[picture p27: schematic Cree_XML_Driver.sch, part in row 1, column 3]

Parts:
C101, C102, C103, C104, C105, C106, C107, C108: 10u; C_0805_2012Metric; MPN GRM21BR61C106KE15L; Digikey 490-3886-1-ND
C109, C110, C111: 0.1u; C_0603_1608Metric; MPN 0603B104K500CT; Digikey 1292-1643-1-ND
D101: Cree XM-L; LED_Cree_XM-L_20mm_Module
D102: PMEG4030; D_SOD-123F; MPN PMEG4030ER,115; LCSC C389355
J101: PJ-102AH; BarrelJack_CUI_PJ-102AH_Horizontal; MPN PJ-102AH; Digikey CP-102AH-ND
J102: Conn_01x03; PinHeader_1x03_P2.54mm_Horizontal
J103: JST 1.25mm; Molex_PicoBlade_53261-0871_1x08-1MP_P1.25mm_Horizontal; MPN 0532610871; Digikey WM7626CT-ND
JP101, JP102, JP103, JP104: SolderJumper_3_Bridged12; SolderJumper-3_P1.3mm_Bridged12_Pad1.0x1.5mm
L101, L102, L103, L104: 4.7u; L_Taiyo-Yuden_MD-4040; MPN SLW4030S4R7MST; LCSC C206284, C15269
LOGO101: MYLIB_CWW_COPPER
MK101, MK102, MK103, MK104: Mounting_Hole_PAD; MountingHole_3.2mm_M3_ISO14580_Pad
Q101, Q102, Q103, Q104: Si2302CDS-T1; SOT-23; MPN Si2302CDS-T1; LCSC C10488
R101, R104, R105, R108: 0.120; R_0805_2012Metric; MPN SR732ATTDR120F; Digikey RL12S.12FCT-ND
R102, R103, R106, R107: 0.270; R_0805_2012Metric; MPN SR732ATTDR270F; Digikey RL12S.27FCT-ND
R109, R110, R111, R112, R113, R118: 100; R_0603_1608Metric; MPN RC0603FR-07100RL; Digikey 311-100HRCT-ND
R114, R115, R116, R119, R120, R121: 100k; R_0603_1608Metric; MPN RC0603FR-07100KL; Digikey 311-100KHRCT-ND
R117, R122: 33; R_0603_1608Metric; MPN RC0603FR-0733RL; Digikey 311-33.0HRCT-ND
TP101: TestPoint; TestPoint_THTPad_1.0x1.0mm_Drill0.5mm
U101, U102, U103, U104: PAM2804; TSOT-23-5; MPN PAM2804AAB010; LCSC C71463
U105, U107: WS2811; SOIC-8_3.9x4.9mm_P1.27mm; LCSC C114581
U106: 74HC14D,653; SOIC-14_3.9x8.7mm_P1.27mm; MPN 74HC14D,653; LCSC C5605

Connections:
+5V: C101.1, C104.1, C105.1, C108.1, C110.1, D102.1 (K), J101.1, J103.1, J103.2, J103.3, R113.1, R114.2, R115.2, R116.2, R118.1, R119.2, R120.2, R121.2, U101.4 (Vin), U102.4 (Vin), U103.4 (Vin), U104.4 (Vin), U106.14 (VCC)
/DIN: J102.2, J103.4, R117.2
/LED_B: C107.1, D101.3 (BA), L104.2
/LED_G: C106.1, D101.2 (GA), L103.2
/LED_R: C102.1, D101.1 (RA), L101.2
/LED_W: C103.1, D101.4 (WA), L102.2
/PWM_B: U104.1 (EN), U106.6 (3Y)
/PWM_BB: JP103.2 (C), R112.2
/PWM_BG: JP102.2 (C), R109.2
/PWM_BR: JP101.2 (C), R110.2
/PWM_BW: JP104.2 (C), R111.2
/PWM_G: U103.1 (EN), U106.4 (2Y)
/PWM_R: U101.1 (EN), U106.2 (1Y)
/PWM_W: U102.1 (EN), U106.8 (4Y)
GND: C101.2, C102.2, C103.2, C104.2, C105.2, C106.2, C107.2, C108.2, C109.2, C110.2, C111.2, D101.9 (PAD), J101.2, J101.3, J102.3, J103.5, J103.6, J103.7, J103.8, J103.MP (MountPin), MK101.1, MK102.1, MK103.1, MK104.1, Q101.2 (S), Q102.2 (S), Q103.2 (S), Q104.2 (S), R102.2, R103.2, R106.2, R107.2, U101.2 (GND), U102.2 (GND), U103.2 (GND), U104.2 (GND), U105.4 (GND), U106.7 (GND), U107.4 (GND)
unnamed: C109.1, R113.2, U105.8 (VDD)
unnamed: C111.1, R118.2, U107.8 (VDD)
unnamed: D101.5 (WK), R105.1, R106.1, U102.5 (FB)
unnamed: D101.6 (BK), R107.1, R108.1, U104.5 (FB)
unnamed: D101.7 (GK), R101.1, R102.1, U103.5 (FB)
unnamed: D101.8 (RK), R103.1, R104.1, U101.5 (FB)
unnamed: D102.2 (A), J102.1
unnamed: JP101.1 (A), JP102.1 (A), JP103.1 (A), JP104.3 (B), U106.10 (5Y)
unnamed: JP101.3 (B), JP102.3 (B), JP103.3 (B), JP104.1 (A), U106.12 (6Y)
unnamed: L101.1, U101.3 (SW)
unnamed: L102.1, U102.3 (SW)
unnamed: L103.1, U103.3 (SW)
unnamed: L104.1, U104.3 (SW)
unnamed: Q101.1 (G), R109.1
unnamed: Q101.3 (D), R101.2
unnamed: Q102.1 (G), R110.1
unnamed: Q102.3 (D), R104.2
unnamed: Q103.1 (G), R111.1
unnamed: Q103.3 (D), R105.2
unnamed: Q104.1 (G), R112.1
unnamed: Q104.3 (D), R108.2
unnamed: R114.1, U105.1 (OUTR), U106.1 (1A)
unnamed: R115.1, U105.2 (OUTG), U106.3 (2A)
unnamed: R116.1, U105.3 (OUTB), U106.5 (3A)
unnamed: R117.1, U105.6 (DIN)
unnamed: R119.1, U106.9 (4A), U107.1 (OUTR)
unnamed: R120.1, U106.11 (5A), U107.2 (OUTG)
unnamed: R121.1, U106.13 (6A), U107.3 (OUTB)
unnamed: R122.1, U107.6 (DIN)
unnamed: R122.2, U105.5 (DO)
unnamed: TP101.1, U107.5 (DO)

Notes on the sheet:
SERCOM 0
I=0.1/R
350mA Std ~~280mOhm 1A High ~~100mOhm
Digikey: PJ-102AH
Talk about pwm freq
RGB + W High Power Modes

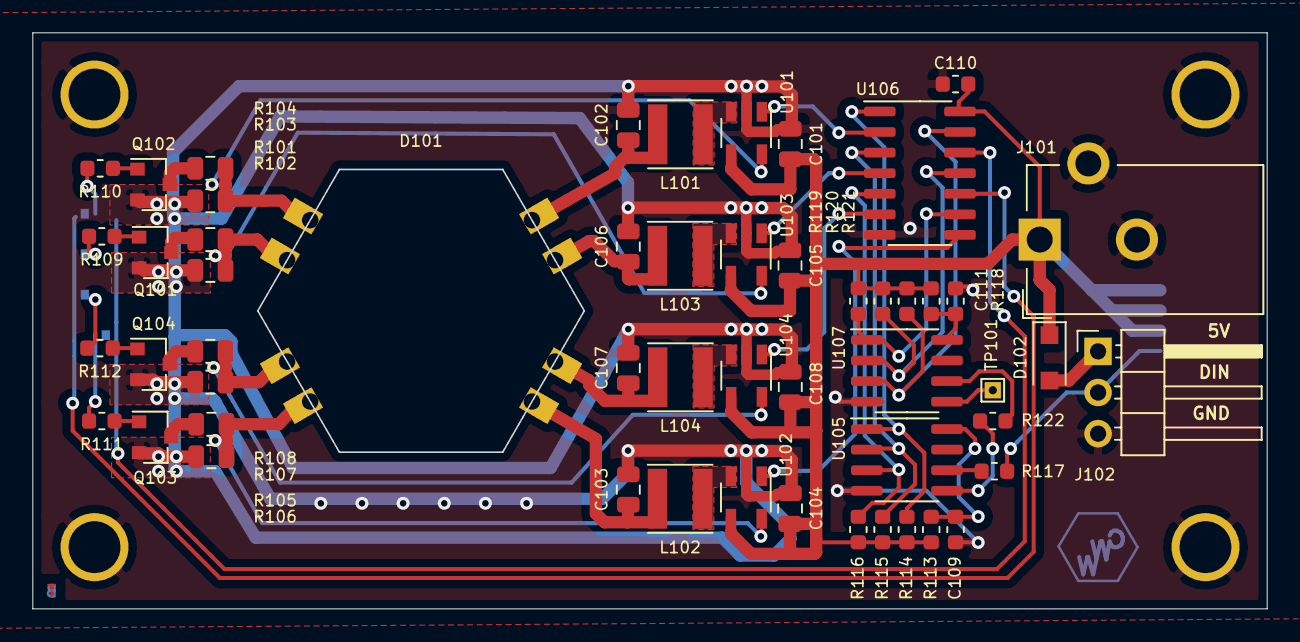
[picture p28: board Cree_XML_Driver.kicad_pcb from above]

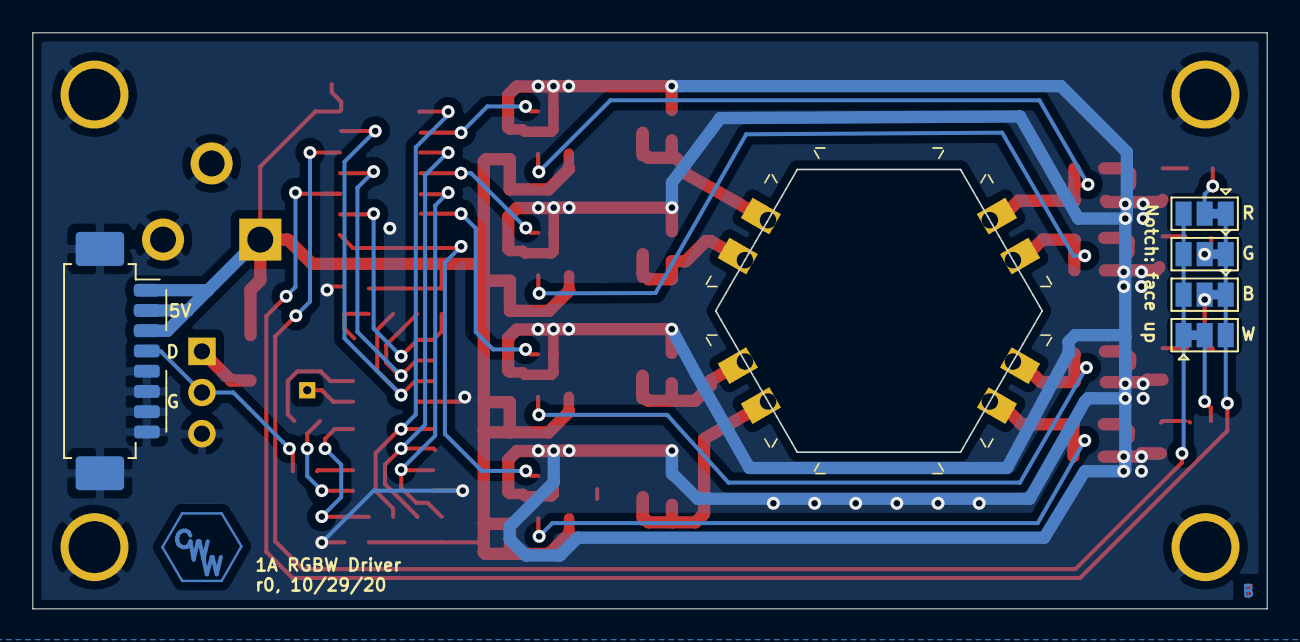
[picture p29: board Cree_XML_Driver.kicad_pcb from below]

Board: 2 copper layers, 76.2 x 35.6 mm, 63 parts (6 on the bottom side), 46 nets.

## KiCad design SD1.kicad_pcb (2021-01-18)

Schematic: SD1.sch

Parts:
$U101: SPS30; MPN SPS30; Digikey 1649-1106-ND
C101, C103, C107: 10u; C_0603_1608Metric; MPN C1608X5R1A106M080AC; Digikey 445-6853-1-ND
C102, C104: 1u; C_0603_1608Metric; MPN TMK107B7105KA-T; Digikey 587-2984-1-ND
C105, C106, C108: 0.1u; C_0603_1608Metric; MPN 0603B104K500CT; Digikey 1292-1643-1-ND
D101: LED_RGBA; LED_19-237_1.6x1.6mm; MPN 19-237; Digikey 19-237A/R6GHBHC-B01/2T
FB101: Ferrite_Bead_Small; L_0603_1608Metric; MPN BLM18PG471SN1D; Mouser 81-BLM18PG471SN1D
J101, J102: JST 1.25mm; Molex_PicoBlade_53398-0871_1x08-1MP_P1.25mm_Vertical; MPN 0533980871; Digikey WM7612CT-ND
J103: JST ZH 1.5mm 1x5; JST-ZR-B5B-SM4-TFLFSN_1x05-1MP_P1.5mm_Vertical; MPN B5B-ZR-SM4-TF(LF)(SN); Digikey 455-1684-1-ND
JP101, JP102: SolderJumper_2_Open; SolderJumper-2_P1.3mm_Open_RoundedPad1.0x1.5mm
JP103: Jumper_NO_Small; SolderJumper-2_P1.3mm_Open_RoundedPad1.0x1.5mm
JP104: Jumper_3_Open; PinHeader_1x03_P2.54mm_Vertical
LOGO101: MYLIB_CWW_COPPER
LS101: Speaker_Crystal; Buzzer_TDK_PS1240P02BT_D12.2mm_H6.5mm; MPN PS1240P02BT; Digikey 445-2525-1-ND
MK101, MK102, MK103, MK104: Mounting_Hole_PAD; MountingHole_3.2mm_M3_ISO14580_Pad
Q101: BSS138; SOT-23; MPN BSS138; Digikey BSS138-FDICT-ND
Q102: PDTC114EU,115; SOT-323_SC-70; MPN PDTC114EU,115; LCSC C135830
R101: 100k; R_0603_1608Metric; MPN RC0603FR-07100KL; Digikey 311-100KHRCT-ND
R102, R103, R104: 1M; R_0603_1608Metric; MPN RC0603FR-071ML; Digikey 311-1.00MHRCT-ND
R105, R106, R107, R108: 10k; R_0603_1608Metric; MPN RC0603FR-0710KL; Digikey 311-10.0KHRCT-ND
R109, R110, R111, R112, R113: 1k; R_0603_1608Metric; MPN RC0603FR-071KL; Digikey 311-1.00KHRCT-ND
R114: 732k; R_0603_1608Metric; MPN RC0603FR-07732KL; Digikey 311-732KHRCT-ND
R115: 47.5k; R_0603_1608Metric; MPN RC0603FR-0747K5L; Digikey 311-47.5KHRCT-ND
SW101: Multidirection_Switch; SKRHA_bosses; MPN SKRHADE011, SKRHADE010; LCSC C602036, C202415
U101: ER-TFTM028-4; MPN DS1023-2*20SF11; LCSC C132132
U102: MCP23017; SSOP-28_5.3x10.2mm_P0.65mm; MPN MCP23017T-E/SS; Digikey MCP23017T-E/SSCT-ND
U103: CC2652P; RF-BM-2652P2; MPN RF-BM-2652P2
U104: SCD30; SCD30_reverse_mount; MPN SCD30; Digikey 1649-1098-ND
U105: BME280; Bosch_LGA-8_2.5x2.5mm_P0.65mm_ClockwisePinNumbering; MPN BME280; Digikey 828-1063-1-ND
U106: EKMC1691111; EKM; MPN EKMC1691111; Digikey 255-6303-ND

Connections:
5V_MainDet: U103.25 (DIO_24); also elsewhere on the board
+5V: $U101.1 (VDD), C107.1, J101.6, J101.7, J101.8, J102.1 (VDD), J103.5, U104.1 (VDD); also elsewhere on the board
/CO_ADC: U103.24 (DIO_23); also elsewhere on the board
/CTP_INT: U101.39 (FLASH_HOLD(CTP_INT)), U103.23 (DIO_22)
/DIO12_RXD: U103.8 (DIO_12); also elsewhere on the board
/DIO13_TXD: U103.9 (DIO_13); also elsewhere on the board
/DIO16_TDO: U103.17 (DIO_16); also elsewhere on the board
/DIO17_TDI: U103.18 (DIO_17); also elsewhere on the board
/Debug and Serial/WMCU_RTS: JP103.1; also elsewhere on the board
/ETH_CS: U103.3 (DIO_7); also elsewhere on the board
/EXT_Sleep: J102.3 (~SLEEP), U102.1 (GPB0)
/FONT_CS: U101.36 (FONT_CS), U102.3 (GPB2)
/IO_INT: U102.20 (INTA), U103.15 (DIO_14)
/I_LED_B: R112.1, U102.21 (GPA0)
/I_LED_G: R111.1, U102.22 (GPA1)
/I_LED_R: R110.1, U102.23 (GPA2)
/LCD_BACKLIGHT: R101.2, U101.29 (BL), U103.22 (DIO_21)
/LCD_DC: U101.25 (WR(D/C)), U102.4 (GPB3)
/Multi_A: SW101.1 (A), U102.24 (GPA3)
/Multi_B: SW101.2 (B), U102.25 (GPA4)
/Multi_C: SW101.3 (C), U102.26 (GPA5)
/Multi_D: SW101.6 (D), U102.27 (GPA6)
/Multi_Press: SW101.4 (Cen), U102.28 (GPA7)
/PIR_SENSE: R115.2, U103.28 (DIO_27), U106.3 (OUT)
/RGBW_DOUT: J101.5, U103.27 (DIO_26)
/SD_CS: U101.35 (SD_CS), U102.2 (GPB1)
/SPKR: JP104.3 (B), R113.1
/SPKR_Alt: JP104.1 (A), Q102.1 (B)
/SPKR_DRIVE: JP104.2 (C), U103.16 (DIO_15)
/VOC_INT: U102.7 (GPB6); also elsewhere on the board
/WMCU_CTS: U103.20 (DIO_19); also elsewhere on the board
/WMCU_RESET: U103.10 (RESET_N); also elsewhere on the board
/WMCU_RTS: JP103.2, U103.19 (DIO_18)
/WMCU_TCK: U103.12 (JTAG_TCKC); also elsewhere on the board
/WMCU_TMS: U103.11 (JTAG_TMSC); also elsewhere on the board
/~ETH_INT: U103.2 (DIO_6); also elsewhere on the board
/~ETH_RST: U102.6 (GPB5); also elsewhere on the board
/~LCD_CS: U101.23 (~LCD_CS), U103.7 (DIO_11)
/~LCD_RESET: U101.21 (~RESET), U102.5 (GPB4)
BATT_Det: U103.26 (DIO_25); also elsewhere on the board
EN_5V_BST: U102.8 (GPB7); also elsewhere on the board
GND: $U101.4 (SEL), $U101.5 (GND), C101.2, C102.1, C103.2, C104.2, C105.2, C106.2, C107.2, C108.2, J101.1, J101.2, J101.3, J101.4, J101.MP (MountPin), J102.2 (GND), J102.MP (PAD), J103.1, J103.2, J103.MP (MountPin), MK101.1, MK102.1, MK103.1, MK104.1, Q101.2 (S), Q102.2 (E), R101.1, R103.2, R107.2, R114.1, R115.1, SW101.5 (Com), U101.1 (VSS), U101.40 (VSS), U102.10 (VSS), U103.14 (GND), U104.2 (GND), U104.7 (SEL), U105.1 (GND), U105.7 (GND), U106.1 (GND); also elsewhere on the board
I2C_SCL: $U101.3 (TX/SCL), J102.4 (-->RXD/SCL), J103.3, R106.2, U101.30 (RTP_CS(CTP_SCL)), U102.12 (SCK), U103.21 (DIO_20), U104.3 (TX/SCL), U105.4 (SCK); also elsewhere on the board
I2C_SDA: $U101.2 (RX/SDA), J102.5 (<--TXD/SDA), J103.4, R105.2, U101.31 (RTP_PEN(CTP_SDA)), U102.13 (SDA), U103.1 (DIO_5), U104.4 (RX/SDA), U105.3 (SDI); also elsewhere on the board
unnamed: C106.1, FB101.1, U105.8 (VDD)
unnamed: D101.1 (RK), R110.2
unnamed: D101.2 (GK), R111.2
unnamed: D101.3 (BK), R112.2
unnamed: JP101.1 (A), U101.26 (RD)
unnamed: JP102.1 (A), U101.28 (LCD_SDO)
unnamed: LS101.2, Q101.3 (D), Q102.3 (C), R109.1
unnamed: Q101.1 (G), R113.2, R114.2
unnamed: R102.2, U102.18 (~RESET~)
unnamed: R103.1, U102.16 (A1), U102.17 (A2)
unnamed: R104.1, U102.15 (A0)
unnamed: R107.1, U105.5 (SDO)
unnamed: R108.1, U105.2 (CSB)
SPI_MISO: JP102.2 (B), U101.32 (SDO), U103.4 (DIO_8); also elsewhere on the board
SPI_MOSI: U101.27 (LCD_SDI(SDA)), U101.34 (SDI), U103.5 (DIO_9); also elsewhere on the board
SPI_SCK: U101.24 (LCD_D/C(SCL)), U101.33 (SCL), U103.6 (DIO_10); also elsewhere on the board

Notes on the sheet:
SERCOM 0
Barrel Jack: 5.5mm OD 2.1mm ID/Pole
See 21.4.4
The Serial 4wire SPI MCU interface I Reference Example
See: https://www.buydisplay.com/download/interfacing/ER-TFT028-4_CTP_Interfacing.pdf
See: https://www.buydisplay.com/download/interfacing/ER-TFTM028-4_Interfacing.pdf
Use 33k - 100k
Need to flip bc of cable
I2C: 111011[0][rw]
Particulates
Temp / Humidity / Pressure
Motion Detection
External / Additional Sensor Connector
Carbon Monoxide Sensor
Carbon Dioxide Sensor
Volatile Organic Compounds
Smoke Sensor
Buy 2x40 display header, PRT-16764
Need Jumper

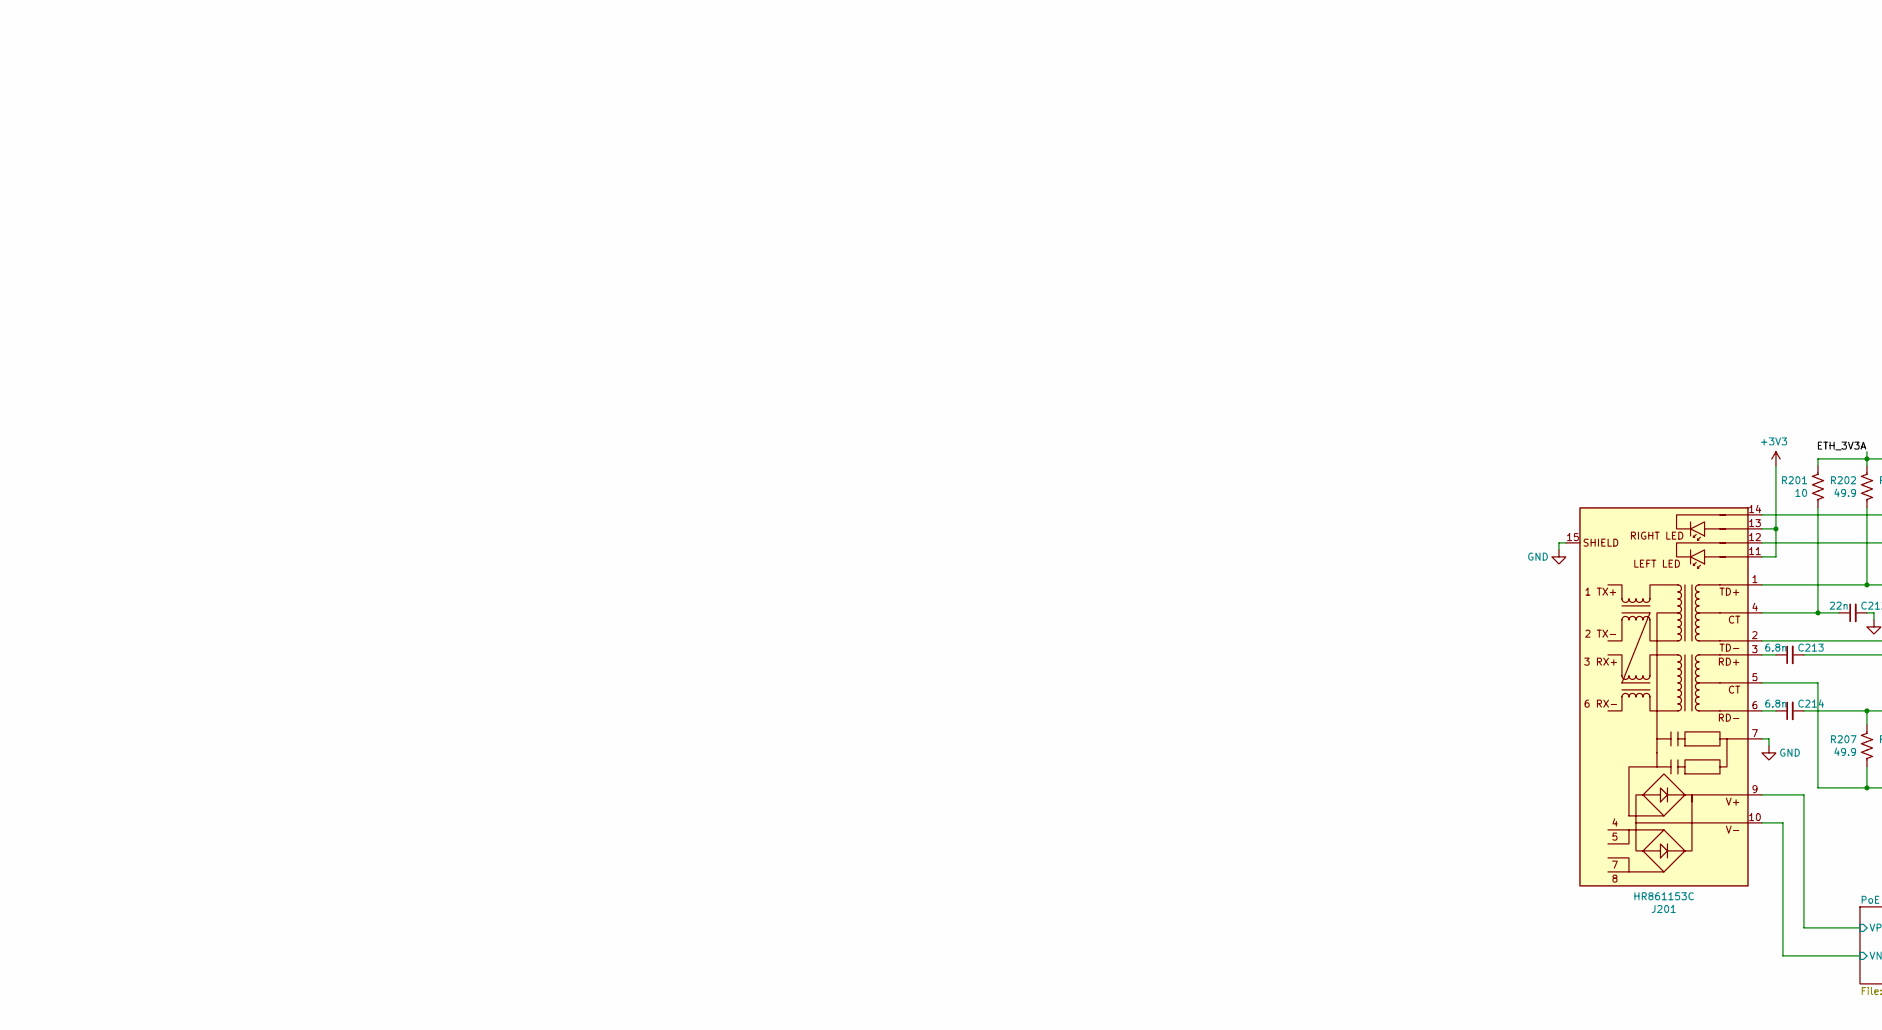
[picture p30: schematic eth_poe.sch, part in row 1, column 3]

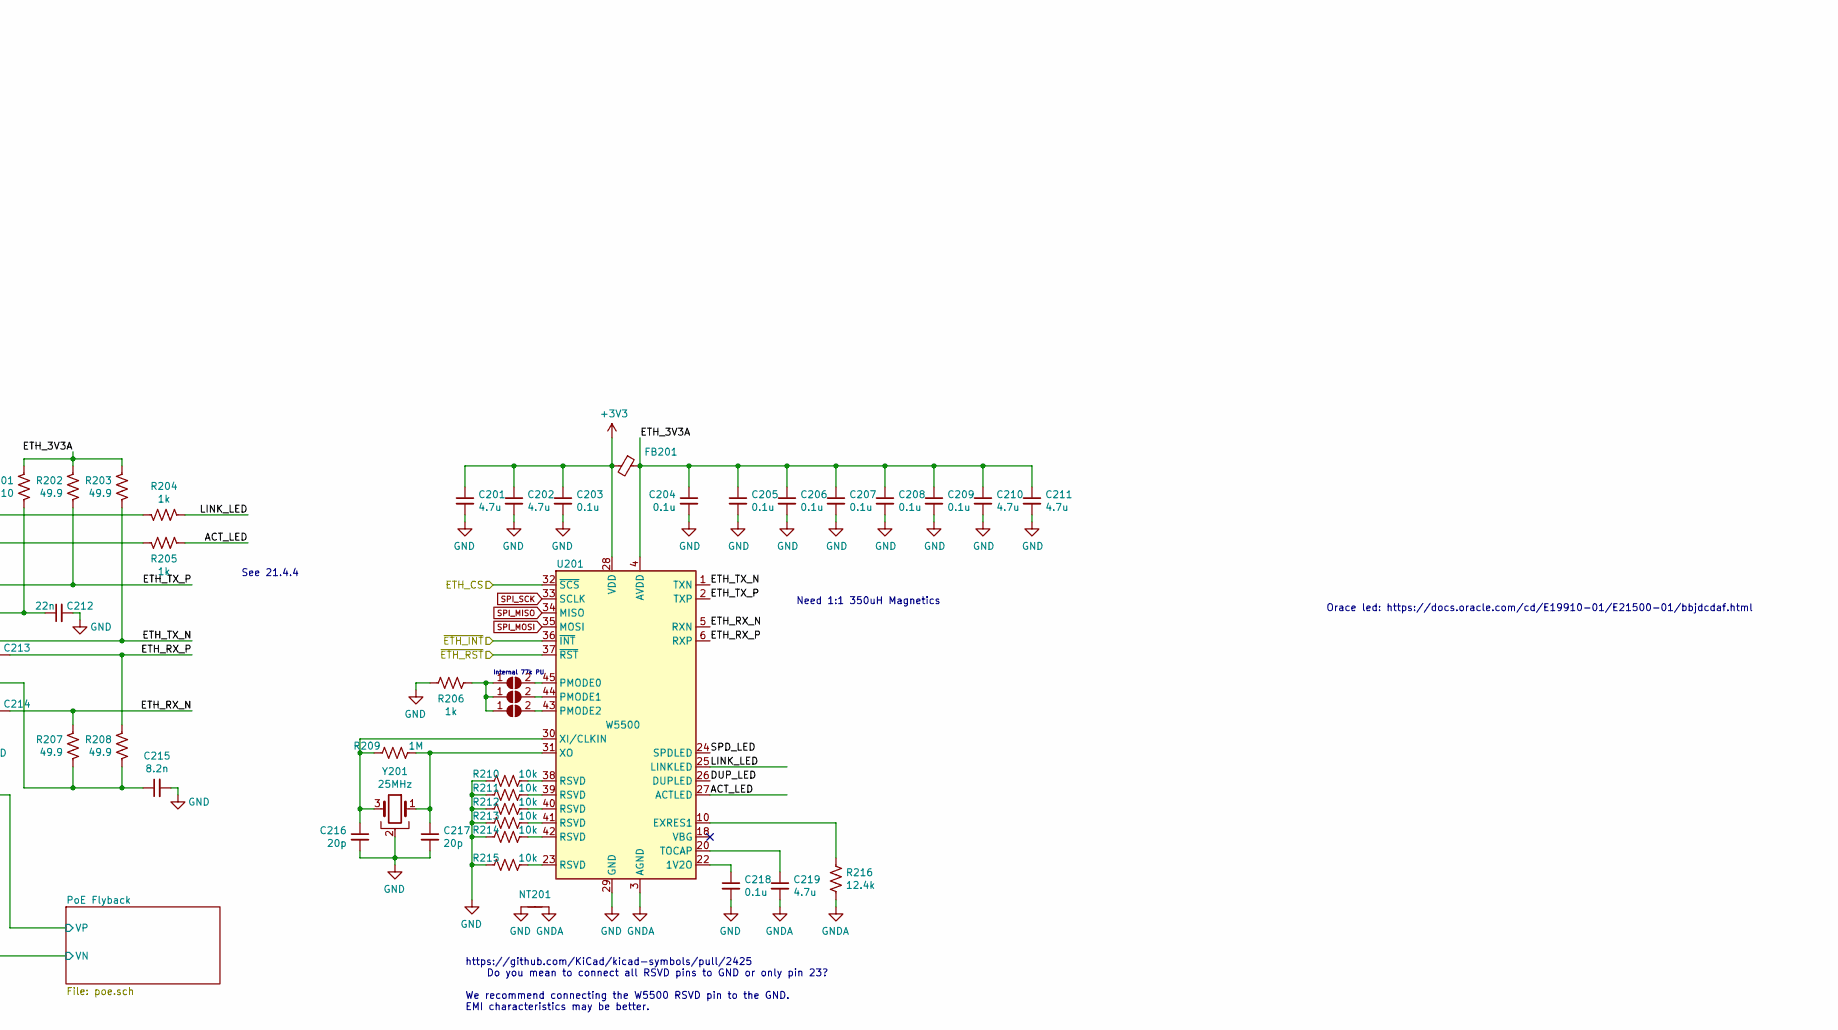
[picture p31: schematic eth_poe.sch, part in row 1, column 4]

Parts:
C201, C202, C210, C211, C219: 4.7u; C_0603_1608Metric; MPN C0603C475K9PACTU; Digikey 399-3482-1-ND
C203, C204, C205, C206, C207, C208, C209, C218: 0.1u; C_0603_1608Metric; MPN 0603B104K500CT; Digikey 1292-1643-1-ND
C212: 22n; C_0603_1608Metric; MPN CL10B223KC8WPNC; Digikey 1276-CL10B223KC8WPNCCT-ND
C213, C214: 6.8n; C_0603_1608Metric; MPN CC0603KRX7R9BB682; Digikey 311-1084-1-ND
C215: 8.2n; C_0603_1608Metric; Voltage 50V; MPN CC0603KRX7R9BB822; Digikey 311-1811-1-ND
C216, C217: 20p; C_0603_1608Metric; MPN CC0603JRNPO9BN200; Digikey 311-1424-1-ND
FB201: Ferrite_Bead_Small; L_0603_1608Metric; MPN BLM18PG471SN1D; Digikey 490-5223-1-ND
J201: HR861153C; RJ45_Abracon_ARJP11A-MA_Horizontal; MPN ARJP11A-MASA-B-A-EMU2; Digikey ARJP11A-MASA-B-A-EMU2-ND
JP201, JP202, JP203: SolderJumper_2_Open; R_0201_0603Metric
NT201: Net-Tie_2; NetTie-2_SMD_Pad0.5mm
R201: 10; R_0603_1608Metric; MPN RC0603JR-0710RL; Digikey 311-10GRDKR-ND
R202, R203, R207, R208: 49.9; R_0603_1608Metric
R204, R205, R206: 1k; R_0603_1608Metric; MPN RC0603FR-071KL; Digikey 311-1.00KHRCT-ND
R209: 1M; R_0603_1608Metric; MPN RC0603FR-071ML; Digikey 311-1.00MHRCT-ND
R210, R211, R212, R213, R214, R215: 10k; R_0603_1608Metric; MPN RC0603FR-0710KL; Digikey 311-10.0KHRCT-ND
R216: 12.4k; R_0603_1608Metric; MPN RC0603FR-0712K1L; Digikey 311-12.1KHRCT-ND
U201: W5500; LQFP-48_7x7mm_P0.5mm; MPN W5500; Digikey 1278-1021-ND
Y201: 25MHz; Crystal_SMD_3225-4Pin_3.2x2.5mm; MPN X1E000021035200; Digikey SER4375CT-ND

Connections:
/ETH_CS: U201.32 (~SCS); also elsewhere on the board
/Eth + PoE/ACT_LED: R205.1, U201.27 (ACTLED)
/Eth + PoE/ETH_3V3A: C204.1, C205.1, C206.1, C207.1, C208.1, C209.1, C210.1, C211.1, FB201.1, R201.2, R202.2, R203.2, U201.4 (AVDD), U201.8 (AVDD), U201.11 (AVDD), U201.15 (AVDD), U201.17 (AVDD), U201.21 (AVDD)
/Eth + PoE/ETH_RX_N: C214.2, R207.2, U201.5 (RXN)
/Eth + PoE/ETH_RX_P: C213.2, R208.2, U201.6 (RXP)
/Eth + PoE/ETH_TX_N: J201.2 (TD-), R203.1, U201.1 (TXN)
/Eth + PoE/ETH_TX_P: J201.1 (TD+), R202.1, U201.2 (TXP)
/Eth + PoE/LINK_LED: R204.1, U201.25 (LINKLED)
/Eth + PoE/PoE Flyback/VN: J201.10 (V-); also elsewhere on the board
/Eth + PoE/PoE Flyback/VP: J201.9 (V+); also elsewhere on the board
/~ETH_INT: U201.36 (~INT); also elsewhere on the board
/~ETH_RST: U201.37 (~RST); also elsewhere on the board
GND: C201.2, C202.2, C203.2, C204.2, C205.2, C206.2, C207.2, C208.2, C209.2, C210.2, C211.2, C212.2, C215.2, C216.2, C217.2, C218.2, J201.7, J201.15 (SHIELD), NT201.1, R206.1, R210.1, R211.1, R212.1, R213.1, R214.1, R215.1, U201.29 (GND), Y201.2; also elsewhere on the board
GNDA: C219.2, NT201.2, R216.1, U201.3 (AGND), U201.9 (AGND), U201.14 (AGND), U201.16 (AGND), U201.19 (AGND), U201.48 (AGND); also elsewhere on the board
unnamed: C212.1, J201.4 (CT), R201.1
unnamed: C213.1, J201.3 (RD+)
unnamed: C214.1, J201.6 (RD-)
unnamed: C215.1, J201.5 (CT), R207.1, R208.1
unnamed: C216.1, R209.2, U201.30 (XI/CLKIN), Y201.3
unnamed: C217.1, R209.1, U201.31 (XO), Y201.1
unnamed: C218.1, U201.22 (1V2O)
unnamed: C219.1, U201.20 (TOCAP)
unnamed: J201.12 (LLED-), R205.2
unnamed: J201.14 (RLED-), R204.2
unnamed: JP201.1 (A), JP202.1 (A), JP203.1 (A), R206.2
unnamed: JP201.2 (B), U201.45 (PMODE0)
unnamed: JP202.2 (B), U201.44 (PMODE1)
unnamed: JP203.2 (B), U201.43 (PMODE2)
unnamed: R210.2, U201.38 (RSVD)
unnamed: R211.2, U201.39 (RSVD)
unnamed: R212.2, U201.40 (RSVD)
unnamed: R213.2, U201.41 (RSVD)
unnamed: R214.2, U201.42 (RSVD)
unnamed: R215.2, U201.23 (RSVD)
unnamed: R216.2, U201.10 (EXRES1)
SPI_MISO: U201.34 (MISO); also elsewhere on the board
SPI_MOSI: U201.35 (MOSI); also elsewhere on the board
SPI_SCK: U201.33 (SCLK); also elsewhere on the board

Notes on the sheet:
SERCOM 0
See 21.4.4
Orace led: https://docs.oracle.com/cd/E19910-01/E21500-01/bbjdcdaf.html
Internal 77k PU
Need 1:1 350uH Magnetics
https://github.com/KiCad/kicad-symbols/pull/2425 Do you mean to connect all RSVD pins to GND or only pin 23? We recommend connecting the W5500 RSVD pin to the GND. EMI characteristics may be better.

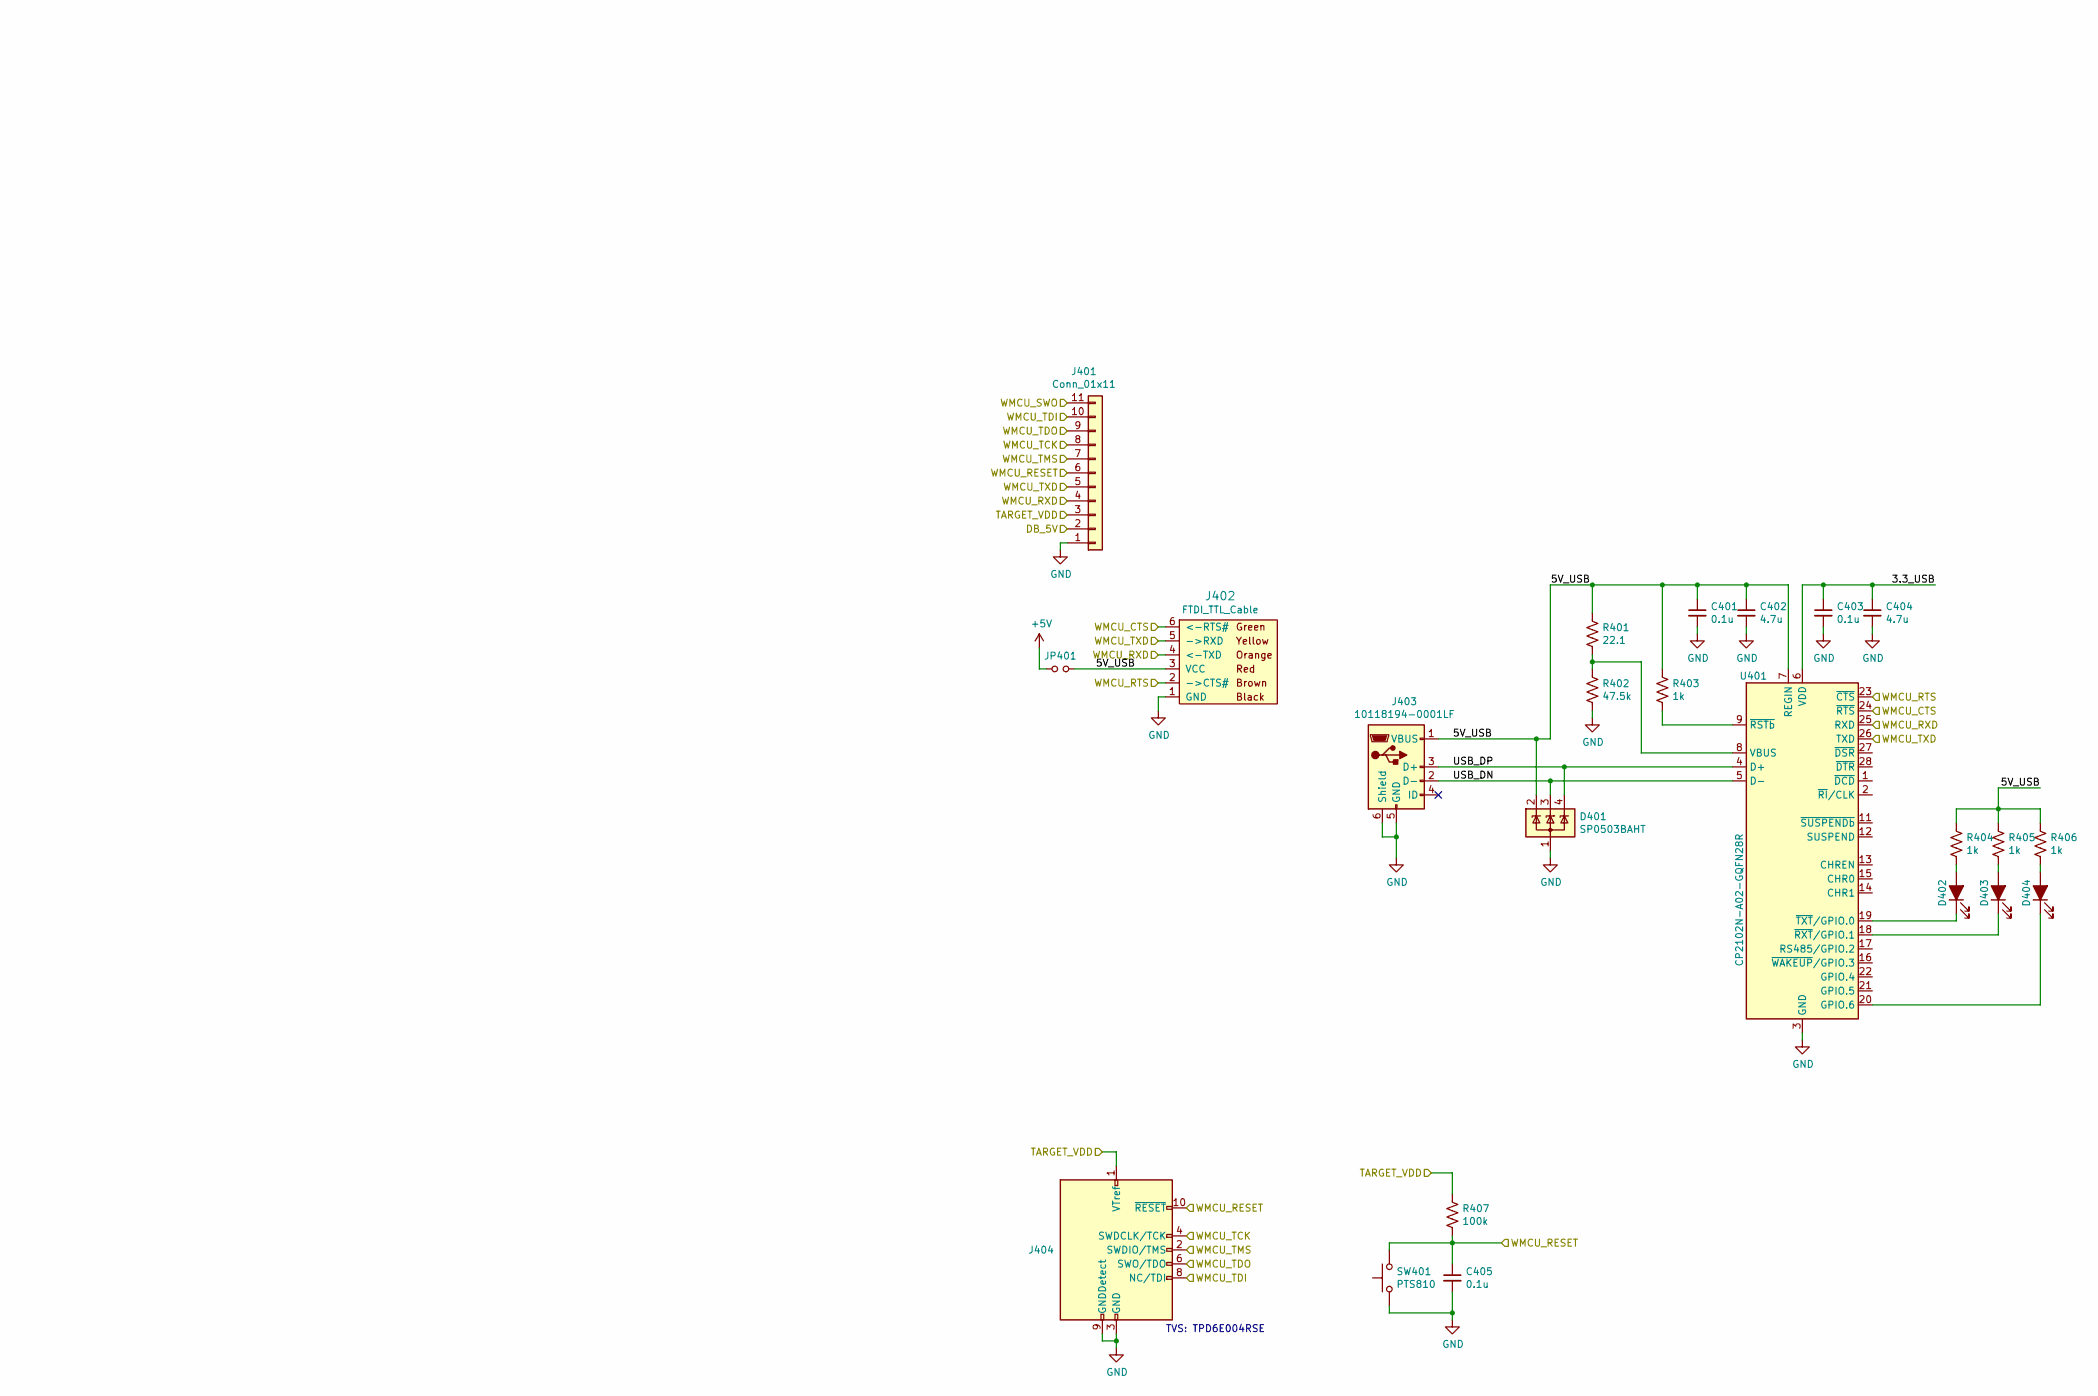
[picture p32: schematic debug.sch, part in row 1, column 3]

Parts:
C401, C403, C405: 0.1u; C_0603_1608Metric; MPN 0603B104K500CT; Digikey 1292-1643-1-ND
C402, C404: 4.7u; C_0603_1608Metric; MPN C0603C475K9PACTU; Digikey 399-3482-1-ND
D401: SP0503BAHT; SOT-143; MPN SP0503BAHTG; Digikey F2715CT-ND
D402, D403, D404: LED_ALT; LED_0603_1608Metric; MPN 150060RS75000; Digikey 732-4978-1-ND
J401: Conn_01x11; Molex_SL_171971-0011_1x11_P2.54mm_Vertical
J402: FTDI_TTL_Cable; PinHeader_1x06_P2.54mm_Vertical; LCSC C190819
J403: 10118194-0001LF; USB_Micro-B_Amphenol_10118194_Horizontal; MPN 10118194-0001LF; Digikey 609-4618-1-ND
J404: Conn_ARM_JTAG_SWD_10; PinHeader_2x05_P1.27mm_Wide_Shrouded_Vertical_SMD; MPN FTSH-105-01-L-DV-K; Digikey SAM8799-ND
JP401: Jumper_NO_Small; PinHeader_1x02_P2.54mm_Vertical
R401: 22.1; R_0603_1608Metric; MPN RC0603FR-0722R1L; Digikey 311-22.1HRCT-ND
R402: 47.5k; R_0603_1608Metric; MPN RC0603FR-0747K5L; Digikey 311-47.5KHRCT-ND
R403, R404, R405, R406: 1k; R_0603_1608Metric; MPN RC0603FR-071KL; Digikey 311-1.00KHRCT-ND
R407: 100k; R_0603_1608Metric; MPN RC0603FR-07100KL; Digikey 311-100KHRCT-ND
SW401: PTS810; SW_SPST_PTS810; Digikey CKN10503CT-ND
U401: CP2102N-A02-GQFN28R; QFN-28-1EP_5x5mm_P0.5mm_EP3.35x3.35mm; MPN CP2102N-A02-GQFN28R; Digikey 336-5890-1-ND

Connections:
+5V: JP401.1; also elsewhere on the board
/DIO12_RXD: J401.4, J402.4 (<-TXD), U401.25 (RXD); also elsewhere on the board
/DIO13_TXD: J401.5, J402.5 (->RXD), U401.26 (TXD); also elsewhere on the board
/DIO16_TDO: J401.9, J404.6 (SWO/TDO); also elsewhere on the board
/DIO17_TDI: J401.10, J404.8 (NC/TDI); also elsewhere on the board
/Debug and Serial/3.3_USB: C403.1, C404.1, U401.6 (VDD)
/Debug and Serial/5V_USB: C401.1, C402.1, D401.2 (K), J402.3 (VCC), J403.1 (VBUS), JP401.2, R401.2, R403.2, R404.2, R405.2, R406.2, U401.7 (REGIN)
/Debug and Serial/USB_DN: D401.3 (K), J403.2 (D-), U401.5 (D-)
/Debug and Serial/USB_DP: D401.4 (K), J403.3 (D+), U401.4 (D+)
/Debug and Serial/WMCU_RTS: J402.2 (->CTS#), U401.23 (~CTS); also elsewhere on the board
/WMCU_CTS: J402.6 (<-RTS#), U401.24 (~RTS); also elsewhere on the board
/WMCU_RESET: C405.1, J401.6, J404.10 (~RESET~), R407.1, SW401.2; also elsewhere on the board
/WMCU_TCK: J401.8, J404.4 (SWDCLK/TCK); also elsewhere on the board
/WMCU_TMS: J401.7, J404.2 (SWDIO/TMS); also elsewhere on the board
GND: C401.2, C402.2, C403.2, C404.2, C405.2, D401.1 (A), J401.1, J402.1 (GND), J403.5 (GND), J403.6 (Shield), J404.3 (GND), J404.5 (GND), J404.9 (GNDDetect), R402.1, SW401.1, U401.3 (GND), U401.29 (GND); also elsewhere on the board
unnamed: D402.1 (K), U401.19 (~TXT~/GPIO.0)
unnamed: D402.2 (A), R404.1
unnamed: D403.1 (K), U401.18 (~RXT~/GPIO.1)
unnamed: D403.2 (A), R405.1
unnamed: D404.1 (K), U401.20 (GPIO.6)
unnamed: D404.2 (A), R406.1
unnamed: R401.1, R402.2, U401.8 (VBUS)
unnamed: R403.1, U401.9 (~RSTb)

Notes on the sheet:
TVS: TPD6E004RSE
SERCOM 0

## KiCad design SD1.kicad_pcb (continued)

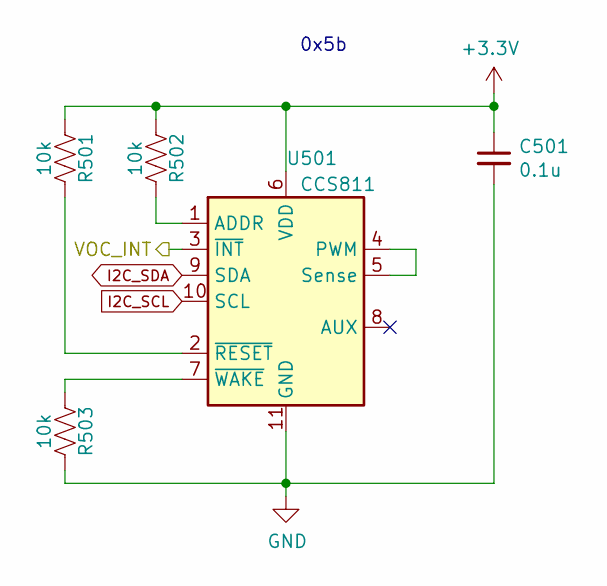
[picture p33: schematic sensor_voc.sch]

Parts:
C501: 0.1u; C_0603_1608Metric; MPN 0603B104K500CT; Digikey 1292-1643-1-ND
R501, R502, R503: 10k; R_0603_1608Metric; MPN RC0603FR-0710KL; Digikey 311-10.0KHRCT-ND
U501: CCS811; AMS_LGA-10-1EP_2.7x4mm_P0.6mm; MPN CCS811B-JOPR5K; Digikey CCS811B-JOPR5KCT-ND

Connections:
/VOC_INT: U501.3 (~INT); also elsewhere on the board
GND: C501.2, R503.2, U501.11 (GND); also elsewhere on the board
I2C_SCL: U501.10 (SCL); also elsewhere on the board
I2C_SDA: U501.9 (SDA); also elsewhere on the board
unnamed: R501.2, U501.2 (~RESET)
unnamed: R502.2, U501.1 (ADDR)
unnamed: R503.1, U501.7 (~WAKE)
unnamed: U501.4 (PWM), U501.5 (Sense)

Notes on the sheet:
0x5b

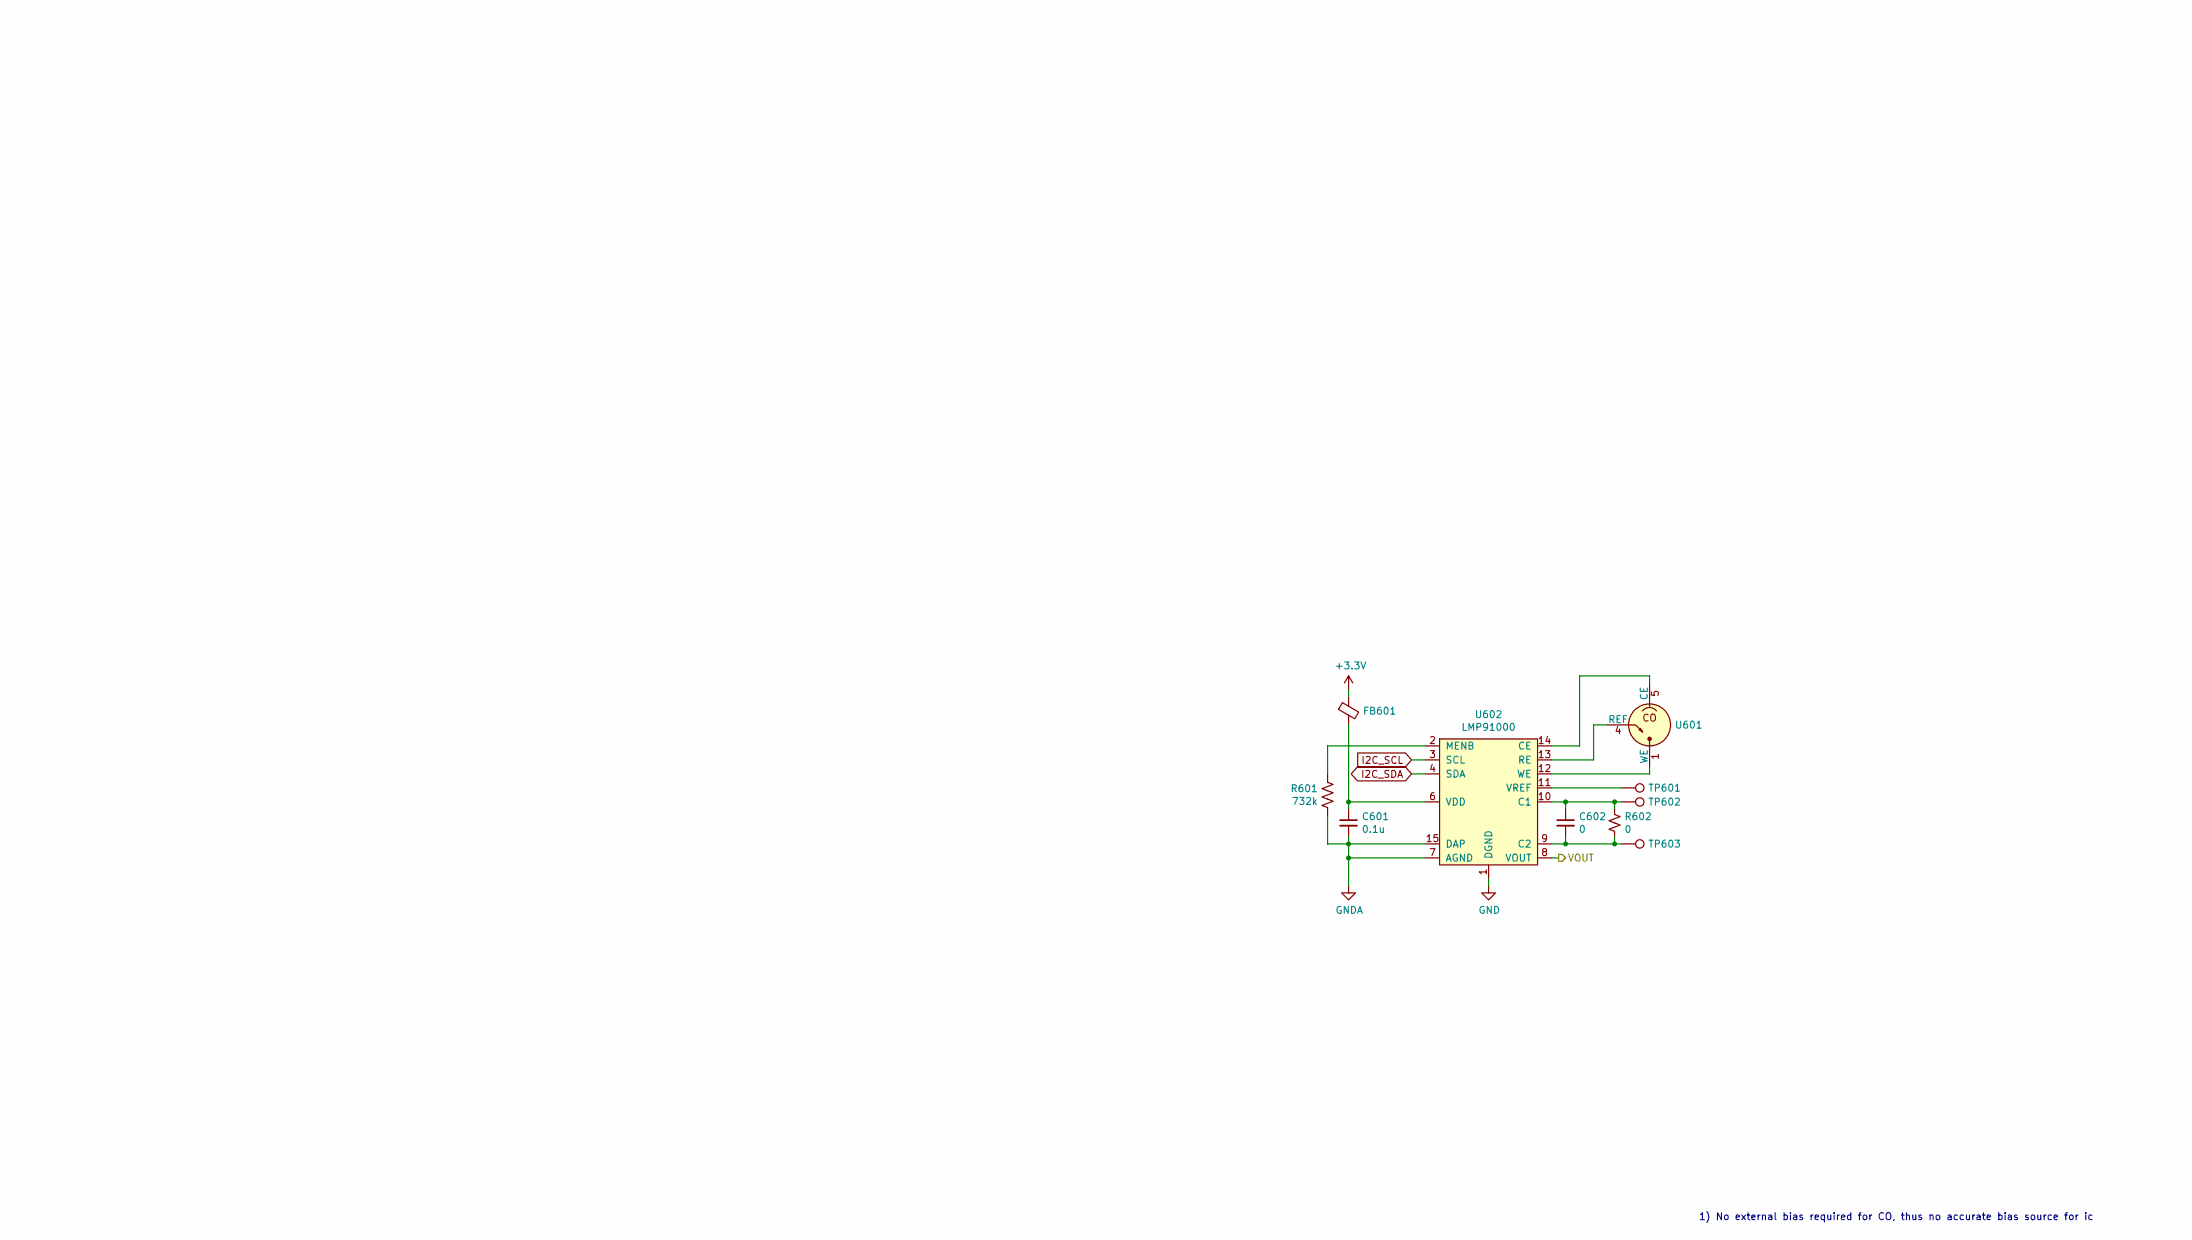
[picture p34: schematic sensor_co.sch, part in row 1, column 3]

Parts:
C601: 0.1u; C_0603_1608Metric; MPN 0603B104K500CT; Digikey 1292-1643-1-ND
C602: 0; C_0603_1608Metric
FB601: Ferrite_Bead_Small; L_0603_1608Metric; MPN BLM18PG471SN1D; Digikey 490-5223-1-ND
R601: 732k; R_0603_1608Metric; MPN RC0603FR-07732KL; Digikey 311-732KHRCT-ND
R602: 0; R_0603_1608Metric
TP601, TP602, TP603: TestPoint; TestPoint_Pad_D1.0mm
U601: 110-102; SPEC_110-102; MPN 110-102; Digikey 1684-1000-ND
U602: LMP91000; WSON-14-1EP_4.0x4.0mm_P0.5mm_EP2.6x2.6mm; MPN LMP91000SD; Digikey 296-44382-1-ND

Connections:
/CO_ADC: U602.8 (VOUT); also elsewhere on the board
GND: U602.1 (DGND); also elsewhere on the board
GNDA: C601.2, R601.2, U602.7 (AGND), U602.15 (DAP); also elsewhere on the board
I2C_SCL: U602.3 (SCL); also elsewhere on the board
I2C_SDA: U602.4 (SDA); also elsewhere on the board
unnamed: C601.1, FB601.2, U602.6 (VDD)
unnamed: C602.1, R602.1, TP602.1, U602.10 (C1)
unnamed: C602.2, R602.2, TP603.1, U602.9 (C2)
unnamed: R601.1, U602.2 (MENB)
unnamed: TP601.1, U602.11 (VREF)
unnamed: U601.1 (WE), U601.6 (WE), U602.12 (WE)
unnamed: U601.2 (NC), U601.3 (NC)
unnamed: U601.4 (REF), U602.13 (RE)
unnamed: U601.5 (CE), U602.14 (CE)

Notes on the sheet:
SERCOM 0
1) No external bias required for CO, thus no accurate bias source for ic

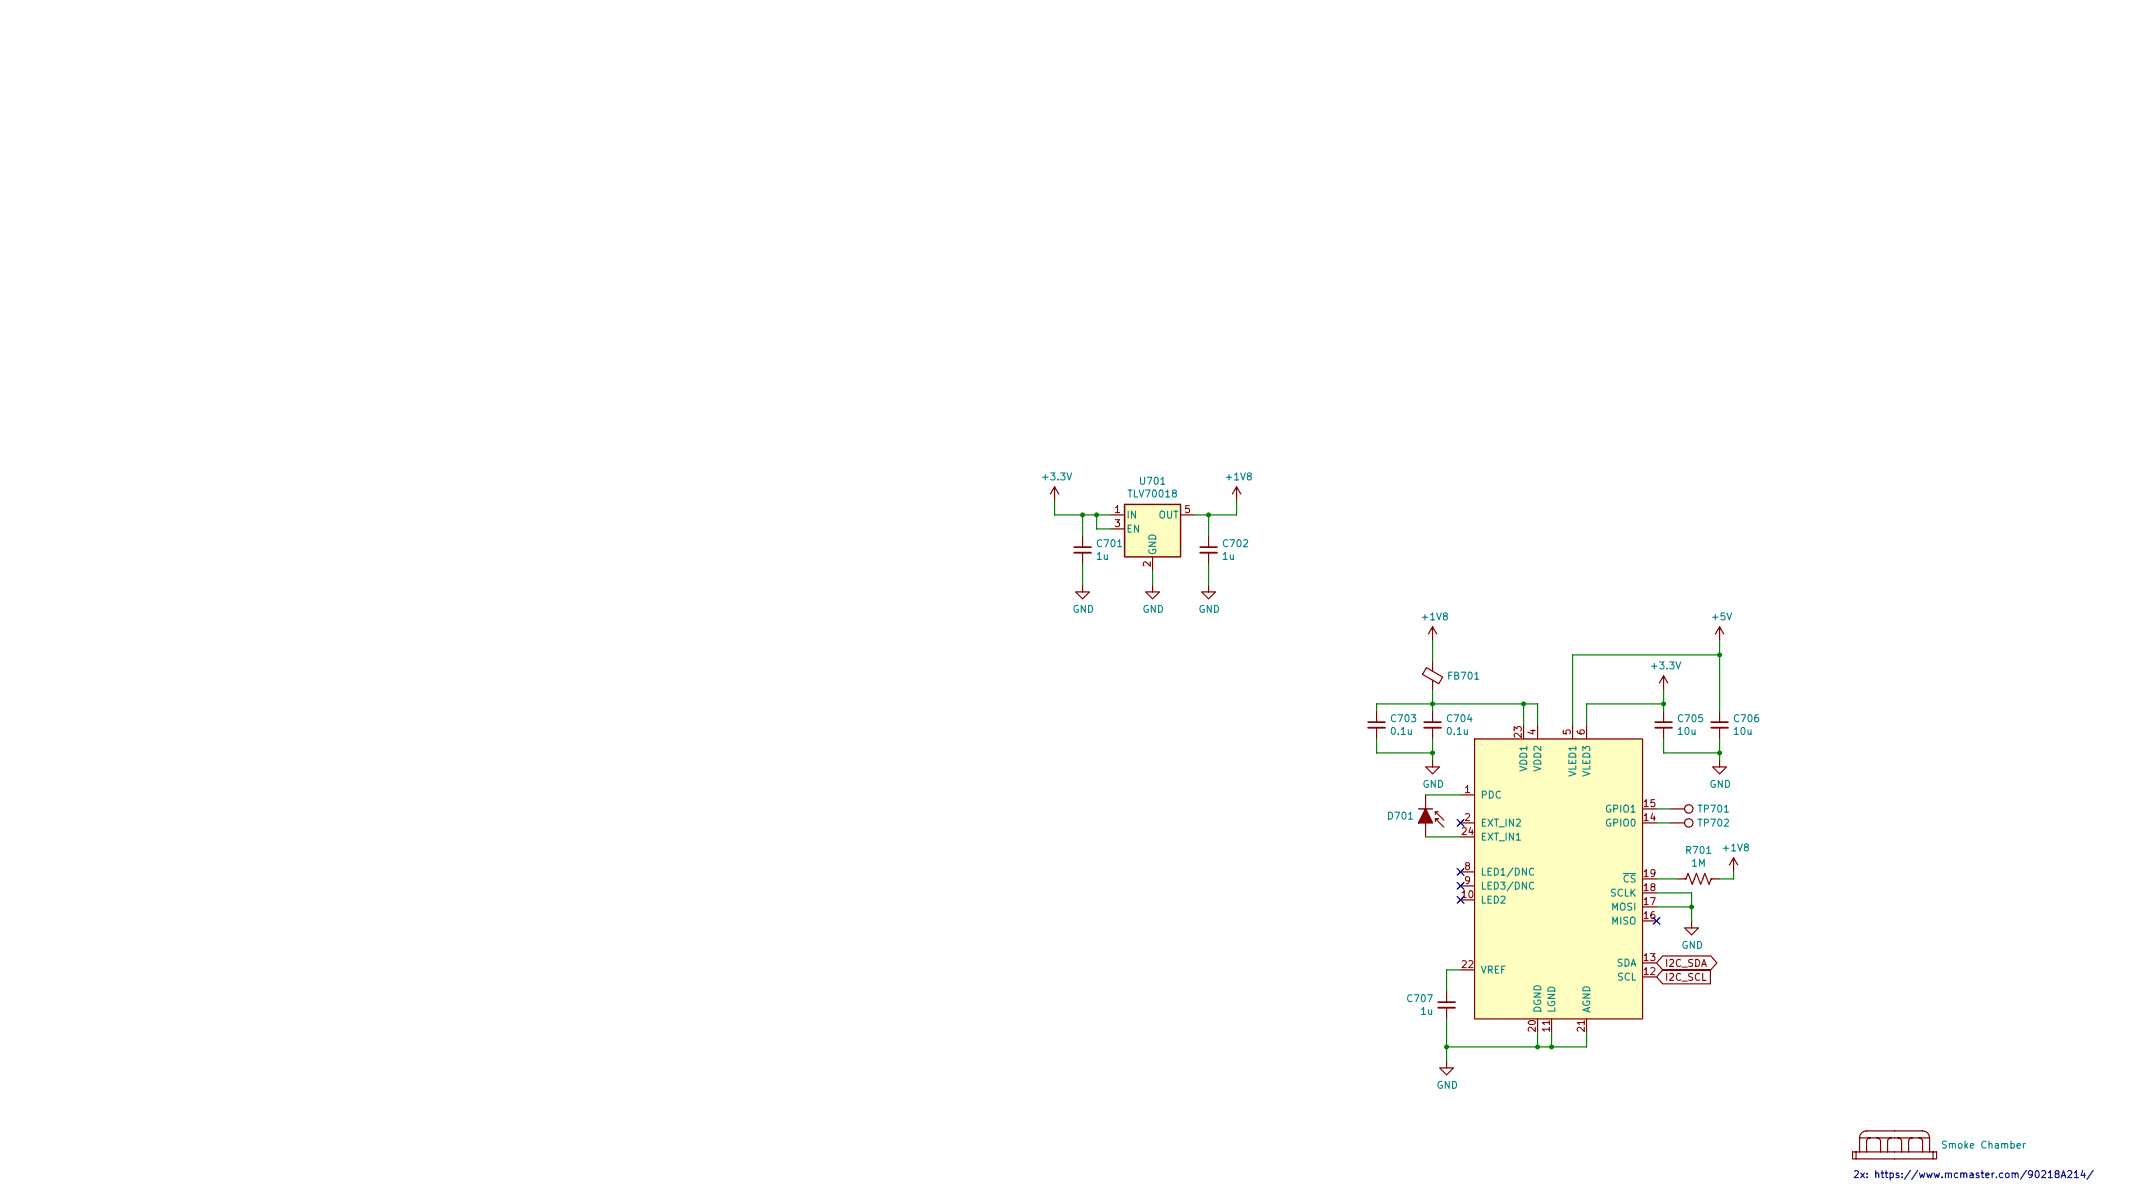
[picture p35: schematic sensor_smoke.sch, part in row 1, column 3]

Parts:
C701, C702, C707: 1u; C_0603_1608Metric; MPN TMK107B7105KA-T; Digikey 587-2984-1-ND
C703, C704: 0.1u; C_0603_1608Metric; MPN 0603B104K500CT; Digikey 1292-1643-1-ND
C705, C706: 10u; C_0603_1608Metric; MPN C1608X5R1A106M080AC; Digikey 445-6853-1-ND
D701: Photodiode alt; LED_D3.0mm_Clear; MPN PD204-6C; Digikey 1080-1140-ND
FB701: Ferrite_Bead_Small; L_0603_1608Metric; MPN BLM18PG471SN1D; Digikey 490-5223-1-ND
R701: 1M; R_0603_1608Metric; MPN RC0603FR-071ML; Digikey 311-1.00MHRCT-ND
TP701, TP702: TestPoint; TestPoint_Pad_D1.0mm
U701: TLV70018; SOT-353_SC-70-5; MPN TLV70018DCK; Digikey 296-32409-1-ND
U702: ADPD188BI; MPN ADPD188BI-ACEZR7; Digikey ADPD188BI-ACEZR7
U703: Smoke Chamber; ADPD188BI_Chamber

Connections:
+1V8: C702.1, FB701.1, R701.2, U701.5 (OUT)
+5V: C706.1, U702.5 (VLED1); also elsewhere on the board
GND: C701.2, C702.2, C703.2, C704.2, C705.2, C706.2, C707.2, U701.2 (GND), U701.4 (NC), U702.11 (LGND), U702.17 (MOSI), U702.18 (SCLK), U702.20 (DGND), U702.21 (AGND); also elsewhere on the board
I2C_SCL: U702.12 (SCL); also elsewhere on the board
I2C_SDA: U702.13 (SDA); also elsewhere on the board
unnamed: C703.1, C704.1, FB701.2, U702.4 (VDD2), U702.23 (VDD1)
unnamed: C707.1, U702.22 (VREF)
unnamed: D701.1 (K), U702.1 (PDC)
unnamed: D701.2 (A), U702.24 (EXT_IN1)
unnamed: R701.1, U702.19 (~CS)
unnamed: TP701.1, U702.15 (GPIO1)
unnamed: TP702.1, U702.14 (GPIO0)

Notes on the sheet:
SERCOM 0
2x: https://www.mcmaster.com/90218A214/

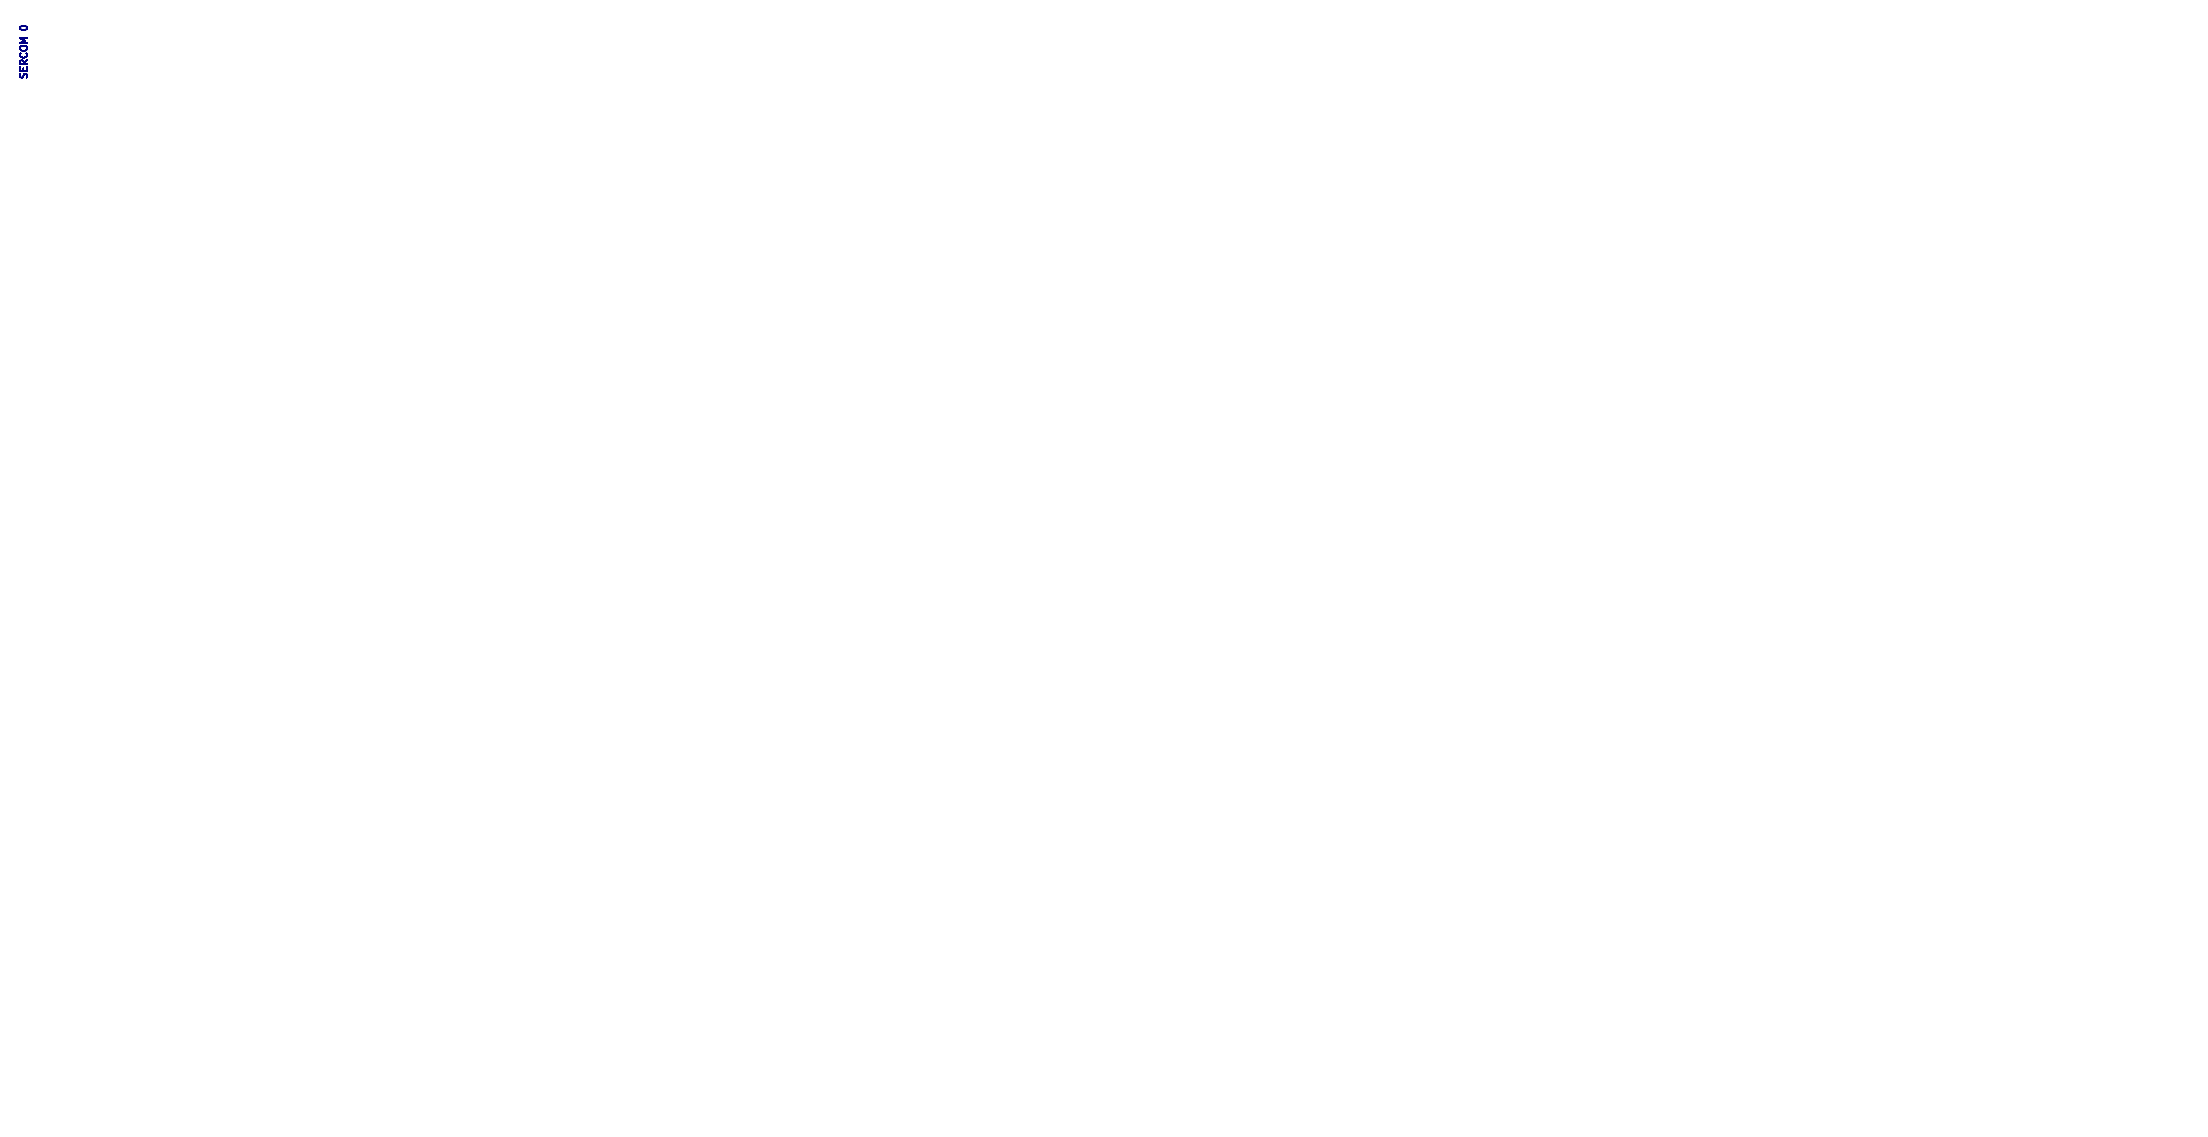
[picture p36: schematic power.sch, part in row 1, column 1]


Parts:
C801, C802, C806, C809, C810: 10u; C_0603_1608Metric; MPN C1608X5R1A106M080AC; Digikey 445-6853-1-ND
C803, C807: 100p; C_0603_1608Metric; MPN CL10C101JC8NNNC; Digikey 1276-1295-1-ND
C804, C805: 47u; C_1210_3225Metric; Voltage 10V; MPN 1210X476K160CT; Digikey 587-5922-1-ND
C808, C811: 4.7u; C_0603_1608Metric; MPN C0603C475K9PACTU; Digikey 399-3482-1-ND
D801: BAS16; D_SOT-23_ANK; MPN BAS16-7-F; Digikey BAS16-FDICT-ND
D802, D803: LED_ALT; LED_0603_1608Metric; MPN 150060RS75000; Digikey 732-4978-1-ND
J801: Conn_01x02; JST_PH_B2B-PH-K_1x02_P2.00mm_Vertical; MPN B2B-PH-K-S(LF)(SN); Digikey B2B-PH-K-S(LF)(SN)
J802: Conn_01x02; PinHeader_1x02_P2.54mm_Vertical
JP801, JP803: Jumper_NO_Small; SolderJumper-2_P1.3mm_Open_TrianglePad1.0x1.5mm
JP802: Jumper_3_Bridged12; SolderJumper-3_P1.3mm_Bridged12_Pad1.0x1.5mm
L801, L802: 1u; L_Wuerth_HCI-5040; MPN 744316100; Digikey 732-6176-1-ND
Q801: DMP3098L-7; SOT-23-6; MPN DMP3098L-7; Digikey DMP3098LDICT-ND
Q802: DMMT5401; SOT-23-6; MPN DMMT5401-7-F; Digikey DMMT5401-FDICT-ND
R801, R803, R809: 100k; R_0603_1608Metric; MPN RC0603FR-07100KL; Digikey 311-100KHRCT-ND
R802: 732k; R_0603_1608Metric; MPN RC0603FR-07732KL; Digikey 311-732KHRCT-ND
R804, R808, R812, R813: 10k; R_0603_1608Metric; MPN RC0603FR-0710KL; Digikey 311-10.0KHRCT-ND
R805: 47.5k; R_0603_1608Metric; MPN RC0603FR-0747K5L; Digikey 311-47.5KHRCT-ND
R806: 392k; R_0603_1608Metric; MPN RC0603FR-07392KL; Digikey 311-392KHRCT-ND
R807: 59k; R_0603_1608Metric; MPN RC0603FR-0759KL; Digikey 311-59.0KHRCT-ND
R810, R811: 1k; R_0603_1608Metric; MPN RC0603FR-071KL; Digikey 311-1.00KHRCT-ND
U801: TPS61022; Texas_VQFN-HR-7; MPN TPS61022; Digikey 296-TPS61022RWURCT-ND
U802: TLV62585; SOT-563; MPN TLV62585DRLR; Digikey 296-51694-1-ND
U803: MCP73831-2-OT; SOT-23-5; MPN MCP73831T-2ACI/OT; Digikey MCP73831T-2ACI/OTCT-ND

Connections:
5V_Main: JP803.2, R811.2; also elsewhere on the board
+5V: C806.1, Q801.2 (S), Q802.5 (E2), U802.3 (VIN), U802.4 (EN); also elsewhere on the board
+BATT: C801.1, C802.1, C811.1, D801.2 (A), J801.1, J802.1, JP802.3 (B), L801.1, R801.2, R812.1, U801.7 (VIN), U803.3 (VBAT)
/Power/5VOUT_BST: C803.1, C804.1, C805.1, D801.1 (K), JP801.1, R802.2, U801.3 (VOUT)
/Power/VSW: L801.2, U801.2 (SW)
BATT_Det: R812.2, R813.1; also elsewhere on the board
EN_5V_BST: R801.1, U801.5 (EN); also elsewhere on the board
GND: C801.2, C802.2, C804.2, C805.2, C806.2, C808.2, C809.2, C810.2, C811.2, J801.2, J802.2, JP802.1 (A), R803.1, R804.2, R805.1, R808.2, R809.1, R810.1, R813.2, U801.1 (GND), U802.1 (GND), U803.2 (VSS); also elsewhere on the board
unnamed: C803.2, R802.1, R803.2, U801.4 (FB)
unnamed: C807.2, R807.2, R809.2, U802.5 (FB)
unnamed: C808.1, JP803.1, U803.4 (VDD)
unnamed: D802.1 (K), R810.2
unnamed: D802.2 (A), D803.1 (K), U803.1 (STAT)
unnamed: D803.2 (A), R811.1
unnamed: JP801.2, Q801.3 (D), Q802.6 (E1)
unnamed: JP802.2 (C), U801.6 (MODE)
unnamed: L802.1, U802.2 (SW)
unnamed: Q801.1 (G), Q802.4 (C2), R805.2
unnamed: Q802.1 (C1), Q802.2 (B1), Q802.3 (B2), R804.1
unnamed: R806.2, R807.1
unnamed: R808.1, U803.5 (PROG)

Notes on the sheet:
SERCOM 0
Vmax = 7
Prebias for Vin > 4.5
Auto PFM
V=3.306
Ideal diode



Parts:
C301: 2200p; C_1812_4532Metric; Voltage 2kV; MPN 202S43W222KV4E; LCSC C426624
C302, C304: 1u; C_1210_3225Metric; Voltage 100V; MPN C1210C105K1RACAUTO; Digikey 399-7044-1-ND
C303: 22u; C_Elec_6.3x7.7; Voltage 63V; MPN EEHZC1J220XP; Digikey P15467CT-ND
C305: 680p; C_0603_1608Metric; Voltage 25V; MPN 0603B681K500CT; Digikey 1292-1458-1-ND
C306: 10u; CP_Elec_4x5.8; Voltage 16V; MPN EEEHD1C100AR; Digikey PCE4949CT-ND
C307: 0.22u; C_0805_2012Metric; Voltage 25V; MPN CL21B224KBFNNNE; Digikey 1276-1093-1-ND
C308, C310: 47u; C_1210_3225Metric; Voltage 10V; MPN 1210X476K160CT; LCSC C396815
C309: 47u; CP_Elec_4x5.8; Voltage 6.3V; MPN EEEFT1C470AR; Digikey P15090CT-ND
C311: 1n; C_0805_2012Metric; Voltage 100V; MPN CL21B102KCANNNC; Digikey 1276-1169-1-ND
C312: 0.1u; C_0805_2012Metric; Voltage 100V; MPN CL21B104KCFWPNE; Digikey 1276-6733-1-ND
C313: 330p; C_0805_2012Metric; Voltage 200V; MPN CC0805KRX7RABB331; Digikey 311-4334-1-ND
C314: 100p; C_0603_1608Metric; Voltage 50V; MPN CL10C101JC8NNNC; Digikey 1276-1295-1-ND
C315: 0.1u; C_0603_1608Metric; Voltage 50V; MPN 0603B104K500CT; Digikey 1292-1643-1-ND
C316: 8.2n; C_0603_1608Metric; Voltage 50V; MPN CC0603KRX7R9BB822; Digikey 311-1811-1-ND
C317: 1u; C_0603_1608Metric; MPN TMK107B7105KA-T; Digikey 587-2984-1-ND
C318: 22n; C_0603_1608Metric; Voltage 50V; MPN CL10B223KC8WPNC; Digikey 1276-CL10B223KC8WPNCCT-ND
D301, D302, D303, D304: MURA120; D_SMA; MPN MURA120T3G; Digikey MURA120T3GOSCT-ND
D305, D306, D307: BAS16; D_SOT-23_ANK; MPN BAS16-7-F; Digikey BAS16-FDICT-ND
D308: MBRS540T3; D_SMC; MPN MBRS540T3G; LCSC C31849
D309: SMAJ58A; D_SMA; MPN SMAJ58CA-E3/61; Digikey SMAJ58CA-E3/61GICT-ND
D310: BAV99; SOT-23; MPN BAV99,215; Digikey 1727-2914-1-ND
D311: LED_ALT; LED_0603_1608Metric; MPN 150060RS75000; Digikey 732-4978-1-ND
FB301, FB302: 10; L_0603_1608Metric; MPN PBY160808T-110Y-N; LCSC C280672
J301, J302: PJ-102AH; BarrelJack_CUI_PJ-102AH_Horizontal; MPN PJ-102AH; Digikey CP-102AH-ND
J303, J304: Conn_01x02; PinSocket_1x02_P2.54mm_Vertical
JP301: Jumper_NO_Small; SolderJumper-2_P1.3mm_Open_TrianglePad1.0x1.5mm
L301: 4.7u; L_Taiyo-Yuden_MD-4040; MPN SLW4030S4R7MST; Digikey 587-5994-1-ND
Q301: DMP3098L-7; SOT-23-6; MPN DMP3098L-7; Digikey DMP3098LDICT-ND
Q302: DMMT5401; SOT-23-6; MPN DMMT5401-7-F; Digikey DMMT5401-FDICT-ND
Q303: FDT86244; SOT-223-3_TabPin2; MPN FDT86244; LCSC C489347
R301: 24.9k; R_0603_1608Metric; MPN RC0603FR-0724K9L; Digikey 311-24.9KHRCT-ND
R302: 22.1; R_0603_1608Metric; MPN RC0603FR-0722R1L; Digikey 311-22.1HRCT-ND
R303: 392k; R_0603_1608Metric; MPN RC0603FR-07392KL; Digikey 311-392KHRCT-ND
R304, R311: 49.9; R_0603_1608Metric; MPN RC0603FR-0749R9L; Digikey 311-49.9HRCT-ND
R305: 39.2k; R_0603_1608Metric; MPN AC0603FR-0739K2L; Digikey YAG3602CT-ND
R306: 59k; R_0603_1608Metric; MPN RC0603FR-0759KL; Digikey 311-59.0KHRCT-ND
R307: 80.6k; R_0603_1608Metric; MPN RC0603FR-0780K6L; Digikey 311-80.6KHRCT-ND
R308, R316: 0; R_0603_1608Metric
R309, R314: 10k; R_0603_1608Metric; MPN RC0603FR-0710KL; Digikey 311-10.0KHRCT-ND
R310: 47.5k; R_0603_1608Metric; MPN RC0603FR-0747K5L; Digikey 311-47.5KHRCT-ND
R312: 82; R_2010_5025Metric; LCSC C421678, C20464
R313, R322, R323, R326: 1k; R_0603_1608Metric; MPN RC0603FR-071KL; Digikey 311-1.00KHRCT-ND
R315: 41.2k; R_0603_1608Metric; MPN RC0603FR-0741K2L; Digikey 311-41.2KHRCT-ND
R317: 1.27k; R_0603_1608Metric; MPN RC0603FR-071K27L; Digikey 311-1.27KHRCT-ND
R318: 0.56; R_1206_3216Metric; MPN KDV12FR560ET; Digikey 273-KDV12FR560ETCT-ND
R319: 19.1k; R_0603_1608Metric; MPN AC0603FR-0719K1L; Digikey 13-AC0603FR-0719K1LCT-ND
R320: 499; R_0603_1608Metric; MPN AC0603FR-07499RL; Digikey 13-AC0603FR-07499RLCT-ND
R321, R325: 100k; R_0603_1608Metric; MPN RC0603FR-07100KL; Digikey 311-100KHRCT-ND
R324: 13.3k; R_0603_1608Metric; MPN RC0603FR-0713K3L; Digikey 311-13.3KHRCT-ND
T301: HR051067; MPN HR051067; LCSC C93830
TP301: TestPoint; PinSocket_1x01_P2.54mm_Vertical
U301: TPS23753A; TSSOP-14_4.4x5mm_P0.65mm; MPN TPS23753APWR; Digikey 296-39365-1-ND
U302: TL431A; SOT-23; MPN TL431ACDBZR; Digikey 296-17328-1-ND
U303: TCMT1107; SOIC-4_4.55x2.6mm_P1.27mm; MPN TCMT1107; LCSC C81148

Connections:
5V_Main: C305.1, C308.1, C309.1, C310.1, D308.1 (K), JP301.1, R308.2, R321.2, R322.1, TP301.1; also elsewhere on the board
5V_MainDet: R321.1, R325.2; also elsewhere on the board
+5V: Q301.2 (S), Q302.5 (E2); also elsewhere on the board
/Eth + PoE/PoE Flyback/APD: R303.2, R305.1, U301.12 (APD)
/Eth + PoE/PoE Flyback/DC_BARREL: D303.2 (A), D304.2 (A), D306.2 (A), J302.1
/Eth + PoE/PoE Flyback/DC_FROM_AC: D301.2 (A), D302.2 (A), D305.2 (A), J301.1
/Eth + PoE/PoE Flyback/VN: C311.2, FB302.2, J304.2; also elsewhere on the board
/Eth + PoE/PoE Flyback/VP: C311.1, D301.1 (K), D302.1 (K), D303.1 (K), D304.1 (K), FB301.2, J304.1; also elsewhere on the board
/Eth + PoE/PoE Flyback/VSS_FILT: C312.2, D309.2 (A2), FB302.1, R317.2, U301.7 (VSS)
GND: C301.1, C308.2, C309.2, C310.2, C317.2, D311.1 (K), R309.2, R310.1, R324.2, R325.1, T301.5, T301.6, U302.3 (A); also elsewhere on the board
GNDD: C301.2, C302.2, C303.2, C304.2, C306.2, C307.2, C313.2, C315.2, J301.2, J301.3, J302.2, J302.3, J303.1, R305.2, R306.2, R307.2, R318.2, T301.2, U301.6 (RTN), U303.3
unnamed: C302.1, C303.1, C312.1, D309.1 (A1), FB301.1, L301.1, R301.1, U301.8 (VDD1), U301.9 (VDD)
unnamed: C304.1, L301.2, T301.3
unnamed: C305.2, R302.1
unnamed: C306.1, C307.1, D307.1 (K), U301.4 (VC)
unnamed: C313.1, R312.2
unnamed: C314.1, C316.1, R315.1, R324.1, U302.2 (REF)
unnamed: C314.2, D310.1 (K), R319.2, U302.1 (K), U303.2
unnamed: C315.1, R320.1, R326.1, U301.2 (VB)
unnamed: C316.2, R319.1
unnamed: C317.1, D310.3 (K), R314.2
unnamed: C318.1, R320.2
unnamed: C318.2, R323.2, U301.1 (CTL), U303.4
unnamed: D305.1 (K), D306.1 (K), R303.1
unnamed: D307.2 (A), R304.2
unnamed: D308.2 (A), R302.2, T301.7, T301.8
unnamed: D310.2 (A), R308.1, R313.1, R314.1, R315.2
unnamed: D311.2 (A), R322.2
unnamed: J303.2, R306.1, U301.14 (FRS)
unnamed: JP301.2, Q301.3 (D), Q302.6 (E1)
unnamed: Q301.1 (G), Q302.4 (C2), R310.2
unnamed: Q302.1 (C1), Q302.2 (B1), Q302.3 (B2), R309.1
unnamed: Q303.1 (G), R311.1
unnamed: Q303.2 (D), R312.1, T301.4
unnamed: Q303.3 (S), R316.1, R318.1
unnamed: R301.2, U301.10 (DEN)
unnamed: R304.1, T301.1
unnamed: R307.1, U301.13 (BLNK)
unnamed: R311.2, U301.5 (GATE~)
unnamed: R313.2, U303.1
unnamed: R316.2, U301.3 (CS)
unnamed: R317.1, U301.11 (CLS)
unnamed: R323.1, R326.2

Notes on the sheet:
how poe works: https://application-notes.digchip.com/006/6-8978.pdf
Ideal diode

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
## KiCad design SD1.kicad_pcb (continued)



Board: 4 copper layers, 108.0 x 108.0 mm, 252 parts (45 on the bottom side), 179 nets.

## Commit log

2020-10-21 Initial kicad dump
    With usb-serial, poe, display, and micro
    [SD1.kicad_pcb, SD1.sch, debug.sch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]
2020-10-21 Adding LED driver
    Initial commit CREE LED driver
    [Cree_XML_Driver.kicad_pcb, Cree_XML_Driver.sch]
2020-10-26 Boilerplate for CO sensor
    [SD1.sch, sensor_co.sch]
2020-10-26 Add VOC sensor
    [SD1.sch, debug.sch, eth_poe.sch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]
2020-10-28 Added CO sensor
    Carbon Monoxide Sensor layout
    [SD1.sch, debug.sch, eth_poe.sch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]
2020-10-28 Minor cleanup
    [SD1.sch, debug.sch, eth_poe.sch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]
2020-10-28 Led horiz
    [Cree_XML_Driver.kicad_pcb, Cree_XML_Driver.sch]
2020-10-29 Finish up led
    [Cree_XML_Driver.kicad_pcb, Cree_XML_Driver.sch]
2020-10-31 Add PIR motion and sheet for smoke
    [SD1.sch, debug.sch, eth_poe.sch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]
2020-11-05 Added Smoke Sensor
    [sensor_smoke.sch]
2020-11-05 Minor smoke cleanup
    [SD1.sch, sensor_smoke.sch]
2020-11-06 Add SPS30 PMS sensor
    -Fix cap
    [SD1.sch]
2020-11-06 Add BME280
    [SD1.sch]
2020-11-06 Minor part picking and annotation
    [SD1.sch, debug.sch, poe.sch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]
2020-11-06 Add SCD30 co2 sensor
    [SD1.sch]
2020-11-08 Major power changes
    Added 5v boost, 3.3 buck, ideal diode circuits.
    Poe: added barrel jacks
    Smoke: general cleanup
    [SD1.sch, debug.sch, eth_poe.sch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]
2020-11-08 Starting pin assignment
    [SD1.sch]
2020-11-08 Continue part picking
    [SD1.sch, debug.sch, eth_poe.sch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]
2020-11-13 Set transformer footprint
    [poe.sch]
2020-11-13 PoE layout
    Changed opto and fixed ref diode footprint/symbol
    [SD1.kicad_pcb, SD1.sch, poe.sch]
2020-11-15 Layout for Smoke and Reference Indicators for PoE
    [SD1.kicad_pcb]
2020-11-18 Modified layout for Smoke, Fixed Ideal Diode
    [SD1.kicad_pcb, power.sch]
2020-11-20 Add smoke chamber to sch and layout
    [SD1.kicad_pcb, sensor_smoke.sch]
2020-11-21 Add pull down for display backlight
    When h-z the backlight partially turns on. Possible to DAC this instead of PWM. Appears to use a NPN instead of a NMOS.
    [SD1.sch]
2020-11-21 Added battery charger schematic
    Annotated
    [SD1.sch, poe.sch, power.sch]
2020-11-21 5V boost and 3.3V buck layout
    [SD1.kicad_pcb]
2020-11-21 Cleaned up, Annotated
    Added Global 5V_Main net, solder jumper for battery charger, jumper for speaker and speaker_alt, added parts for battery charger
    [SD1.sch, poe.sch, power.sch]
2020-11-22 Add resistor to battery indicator, battery layout, update font sizes
    [SD1.kicad_pcb, power.sch]
2020-11-22 Add JST cable for easier integration
    Carries power, data and ground over a JST 1.25mm
    [Cree_XML_Driver.kicad_pcb, Cree_XML_Driver.sch]
2020-11-22 Added RGBW connector
    [SD1.sch]
2020-11-28 Add diodes to seperate APD
    Previously the APD feedback network directly shorted DC_FROM_AC and DC_BARREL together.
    [poe.sch]
2020-11-29 4layer layout WIP
    [SD1.kicad_pcb]
2020-11-29 Bugfix: critical net name error for target VDD and debugging connectors
    [SD1.sch]
2020-11-29 Bugfix: net name error for LCD reset
    [SD1.sch]
2020-12-01 4layer layout WIP, 90%.
    Changed SCD30 to reverse mount.
    Connected RGB led and button to io expander.
    Connected all nets to micro.
    Add jumper for CTS line.
    Nettie GNDA and GND for W5500 Eth.
    Changed EN_5V_BST to Global.
    Bugfixes net names: LCD_CS
    [SD1.kicad_pcb, SD1.sch, eth_poe.sch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]
2020-12-11 Layout WIP, sch final
    USB 5V Jumper works for both FTDI and microusb
    Added decoupling caps for micro
    [SD1.kicad_pcb, SD1.sch, debug.sch]
2020-12-11 Re-annotate all parts
    Cleans up annotations
    [SD1.kicad_pcb, SD1.sch, debug.sch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]
2020-12-11 Prefinal, layout done
    Update FB to use inductor footprints
    DNP net tie
    Update diode symbol in power
    Add battery voltage divider in power
    Supply 5V power to aux sensor connector
    [SD1.kicad_pcb, SD1.sch, eth_poe.sch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]
2020-12-12 BOM reduction and part picking
    [SD1.kicad_pcb, SD1.sch, debug.sch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]
2020-12-12 Trace length matching for ETH and USB
    [SD1.kicad_pcb]
2020-12-12 BOM update and text cleanup
    [Cree_XML_Driver.kicad_pcb, Cree_XML_Driver.sch]
2020-12-16 Prep for gerber export
    Update fields
    Align standoff holes
    [Cree_XML_Driver.kicad_pcb, SD1.kicad_pcb, SD1.sch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]
2020-12-16 Increase clearance for SWD connector
    Alternatives are:
    FTSH-105-01-L-DV-K
    BXIDM03
    3221-10-0300-00
    [SD1.kicad_pcb, debug.sch]
2021-01-11 Soldermask clearance fix
    [Cree_XML_Driver.kicad_pcb, RGBWr0_bom_pcbway_r0.xlsx, SD1.kicad_pcb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]
2021-01-18 Schematic field cleanup
    Remove stray spaces
    Cleaned up duplicate fields
    Normalize: 100pF (C314 C803 C807) and 47uF (C308 C310 C804 C805) according to r0 order
    [SD1.sch, debug.sch, eth_poe.sch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]
2021-01-18 Add generated files
    Added title block to pcb
    Fixed backup lib for USB connector
    [SD1-B_Cu.gbr, SD1-B_Mask.gbr, SD1-B_Paste.gbr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]
2021-01-18 Schematic field cleanup
    Fixed rescue libs
    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
    [Cree_XML_Driver.sch]
2021-01-18 Add generated files
    [Cree_XML_Driver-B_Cu.gbr, Cree_XML_Driver-B_Mask.gbr, Cree_XML_Driver-B_Paste.gbr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]
2021-01-22 Add flowchart to readme
2021-03-14 Initial flash mod
    Add on module for additional flash memory
    [FLASH_MOD-NPTH-drl_map.dxf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]
2021-03-14 Flash mod add generated files
    [FLASH_MOD-B_Cu.gbr, FLASH_MOD-B_Mask.gbr, FLASH_MOD-B_SilkS.gbr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]
